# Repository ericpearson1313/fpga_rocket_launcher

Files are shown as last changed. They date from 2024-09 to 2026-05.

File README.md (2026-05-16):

### fpga_rocket_launcher

A long-time hobby of mine is model rocketry where I build and fly models rockets in a club setting.
A launch controller has a push button to electrically launch the models safely from a distance.
The controller feeds current from a battery, through a push button and lead wires to a resistive heater to initiate the launch.
For something so simple it causes consternation when the launch countdown reaches zero, button is pressed, and nothing, due to a fault of the controller!
Years of itteratively building launch controllers has not yet acheived personal perfection in launch controller design, but I'm having fun trying.

This repo contains my design files for a digital, capacitive discharch, launch controller. It was designed as a one-off fully instrumented 
launch controller based on a FPGA which enables built in oscilloscope-like capture and HDMI display. This provides aid in bring-up, observation of algorithm improvements and field analysis during fail-to-launch scenarios to understand how a launch fails (and adjust the design algorithms accordingly, and repeat). 

### Updates / Branches

Well this project has evolved alot. 

The launch controller, fully instrumented, gave me alot of observations of sucessful and failed operations. Burn-through makes this a unique control problem, and when obsereved closely is quite chaotic. Through itterative development and testing I updated the control algorithms and circuits. Alot more testing is needed, but the fpga core 'seems' solid, and my understanding of the initiation process has expanded greatly (and I can see alot more to understand).

Given the core fpga algorithms now for a simple handheld launch controller with rock solid operation.  

Integrating a chip deep within a simple device needs the insight of the development logic (ie hdmi) required tooling(fpgas) to breakout, connect, emulate, monitor, and simulating the system, and test the devices. This required a base architecture and plan to take advantage of the simple interconnect (a dozen I/O signals) available using the algorithm. Since this might be some effort,
planning went into the I/O so that it could address a number of device types in case I wanted to re-use it. The handheld controller was designed and is being trialled.

About this time the TinyTapeout.com course occured. This was an opportunity to move the core logic from Fpga to Asic. The same tooling could be used with an Asic too. 

An ASIC was deveoped integrating the launch control chip core. The system model was used as part of the verification test bench. With some time to spare a BIST (built in self test) was added which contained the system model and runs a 65ms truncated system simulation to self validate the hardware. [3D Chip viewer of the actual chip - way cool!](https://gds-viewer.tinytapeout.com/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)

A quick outline of the different branches that have evolved. The readme docs on the branches are non existant so far.

- main : the fpga launch controller release (V6 = 7298ded) is in regular use.
- lcc_1K : isolated the MVP core and implemented it on a tiny 1k FPGA
- lcc_emu : is the full lauch controller ported to the lcc development board, and then re factoted to use the lcc_1k core and instrument it.
- lcc_mon : is a stand alone monitor that jsut looks at the signals of the LCC. Used to validate correct in system opeation
- lcc_syssim : is a system simulator (in progress) that connects to an LCC to test it.
- lcc_tt : is Tiny Tapeout chip in 130nm on a 0.2 x 0.16 mm die (1x2), it almost fit on a 1x1 tile, but not quite, so utilization is low.
- lccst_tt : is a Tiny Tapeout chip including a full self test (2x2) is 320x200um. The self test logic (a full system simulation) is almost 3x larger than the core, but gives me self test.

The original devlopement doc, where it all started, continues below

# Digital Model Rocket Launch Controller

A FPGA based model rocket digital launch controller.

No embedded CPU, this is Verilog RTL synthesized digital logic.

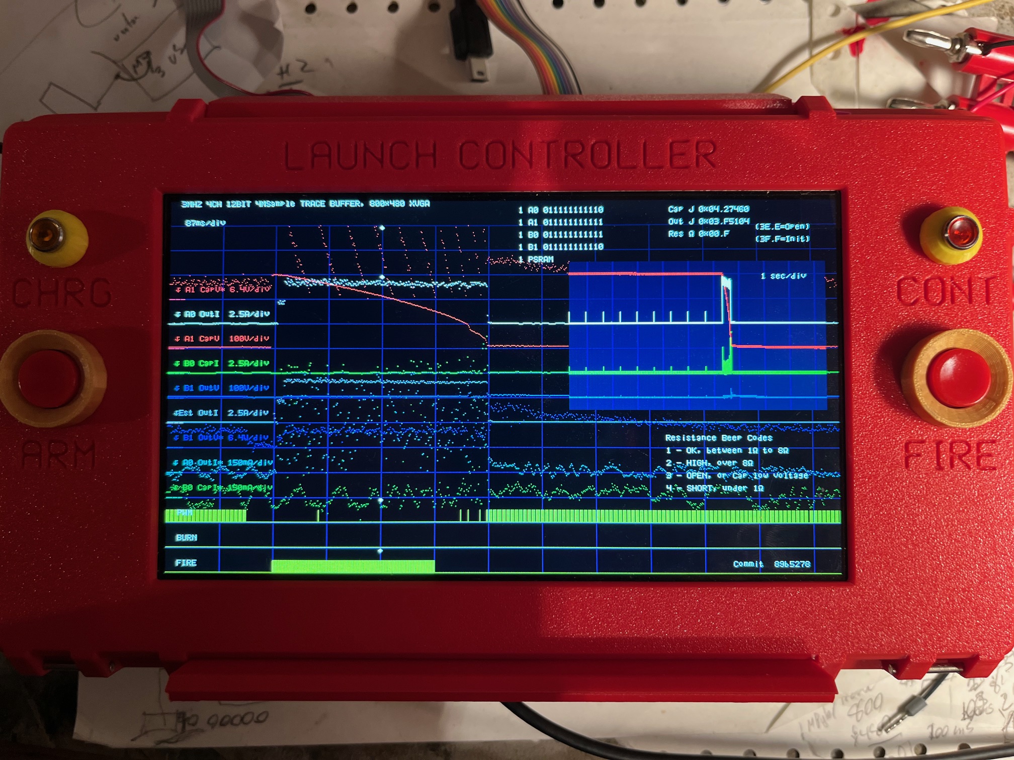
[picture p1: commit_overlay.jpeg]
git commit hash overlay Estes Igniter test


Showing a bench test using an Estes igniter. Observed low resistance (~ 1ohm) and takes 4 Joules at 4 amps for about 300msec.

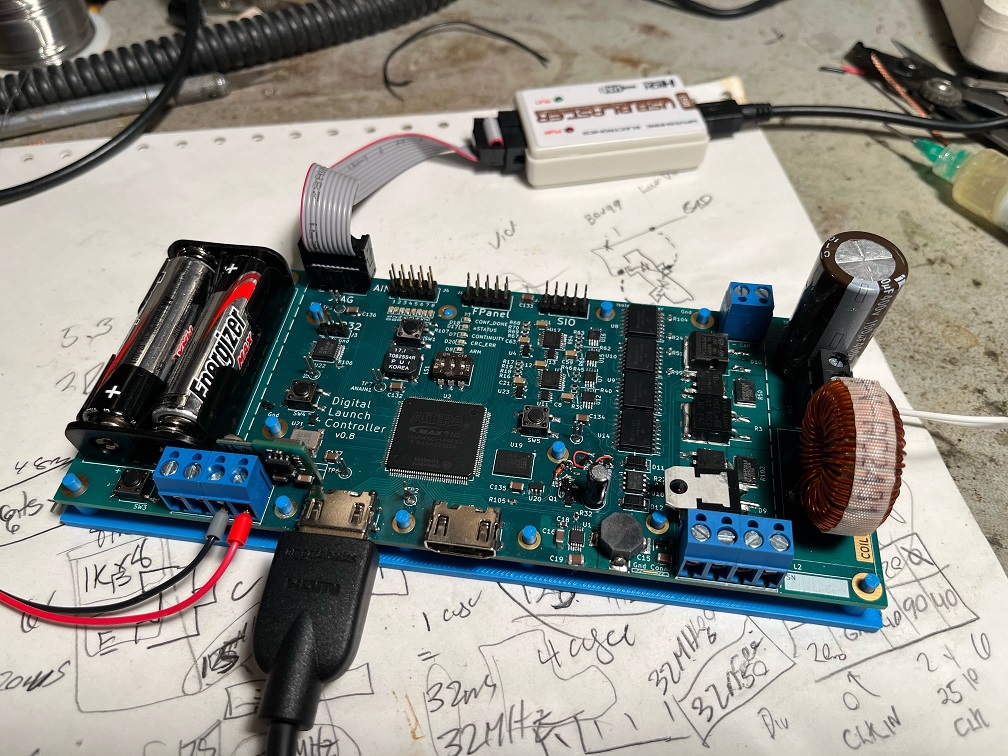
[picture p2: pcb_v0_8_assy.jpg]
Assembled and testing Digital Launch Controller Prototype


[Schematic](fpga_blaster_schem_v0_8.pdf)

### Digital constant current capacitive discharge launch controller.

## Core function

Powered by 4xAA Lithium batteries capable 1A of current. 
When armed, the controller charges a 200uF capactor bank to 320V with a flyback converter giving 10 Joules of stored energy. 
Upon launch, the capacitor is discharged through a 390uH inductor into the igniter.
The discharge is modulated by a FET with a PWM gate drive.
Discharge is digitally current controlled as a buck converter with a setpoint in the range of 2.0 to 6.0 amps.
The set current is maintained over the full capacitor discharge, or until the ignitor burns through and the circuit opens.

The digital control system uses a differential analog front end, used to isolate and instrument the capacitor and output IVs.
12-bit ADCs sample the four signals (cap/out,I/V) which are simultaneously sampled and digitized at 3 Mhz and fed into the digital system.

The PWM signal is generated by a control loop running at 48 Mhz (16x sample rate). 
The control loop models the inductor current based on the PWM signal, ADC capcitor and output voltages (slowly changing), sample rate coil inductance. 
The PWM is turned on when ADC output current falls below a setpoint.
The PWM is turned off when the output current model rises above a setpoint,  
The model used for turn-off to avoid overshoot due to timing accuracy and sample latency.
A stable current pulse is generated limited only by the dropping capacitor voltage with a ripple limited only by the minimum PWM pulse width.

## Extended Functions

Additional uses for FPGA logic and real time ADC data stream can be implemented. These range from simple to Max Headroom.

### Charged LED Hysteresis.

Using the ADC stream include the capacitor voltage, the charge-LED could be operated to reflect the capacitor voltage charge with some hysteresis.
The logic would turn on the charge-LED when the capacitor voltage sample is received and reached 300V, as we want a full charge for launch, 
but would only turn off the charge-LED when the capacitor voltage falls below 50V (<3% energy) as we'ed like to know when it is safe to handle.

```
// Arm is based on vcap with 300v on thresh and 50v off thresh
logic cap_charged;
always @( posedge clk ) begin
	if( reset ) begin
		cap_charged <= 0;
	end else begin
		cap_charged <= ( strobe_d && vcap > (( 300 * 10000 ) / 2005 ) ) ? 1'b1 :
		               ( strobe_d && vcap < (( 50  * 10000 ) / 2005 ) ) ? 1'b0 : cap_charged;
	end
end
```

### Fire Button Debounce and Feedback.

Some dedicated logic to handle the lauch button input is worth while.

To make low cost push button feel nice required: adding debounce logic, and provide audio feedback of its operation. 
To do this debounce counters are used to measure at least 5ms of time before sensing a 'press',
and then generating a fixed 10msec pulse output for logic triggering, and 10msec C5 beep for feedback. 
100ms of release time was required before dectecting another button press. 

Multiple experments and measurements were done to get a basic good enough 'feeling' for this button. The audio feedback worked pleasantly well.

This button also had a long press detect feature to trigger additional functionality. 
If held for 600msec a 2nd signal output would be asserted while held.

### Pulse Energy Accumulation

Ignition energy is a key parameter of igniters. Mensurements
are usefull to check this value.

The instantaneous power (Watts) of the capacitor and outputs can
each be calculated from the ADC samples as E = I * V.

The energy (Joules) over a time period can be accumulated by the sum
of the power measurement.

Using 44 bit sum of product of the unscaled I and V ADC values during ignition period gives allows a 10 Joule range with uJ resolution.
Using the unscaled ADC data elimiates numerical error accumulation. For display the nearest decimal point position was chosen from the 44 bit number
and fixed point hexadecimal coding used for display. 
```
// Acculuate both Cap and Output power products.
always @(posedge clk) begin
	strobe_d <= ad_strobe;
	// P = I * V
   pout[21:0] <= vout[10:0] * iout[10:0];
   pcap[21:0] <= vcap[10:0] * icap[10:0];
	if( strobe_d ) begin
		acc_flag_d <= acc_flag;
		// raw power loaded at flag rise, acculuated during flag, and held afterwards
		eout[43:0] <= ( acc_flag && !acc_flag_d ) ? { 22'b0, pout[21:0] } : ( acc_flag ) ? ({ 22'b0, pout[21:0] } + eout[43:0]) : eout[43:0];
		ecap[43:0] <= ( acc_flag && !acc_flag_d ) ? { 22'b0, pcap[21:0] } : ( acc_flag ) ? ({ 22'b0, pcap[21:0] } + ecap[43:0]) : ecap[43:0];
	end else begin
		acc_flag_d <= acc_flag_d;
		eout[43:0] <= eout[43:0];
		ecap[43:0] <= ecap[43:0];
	end
end
```

Measuring power of both the output and capactor gives insights into the device efficiency and 
some redundancy for measurement validation.

### Continuity Checking

Checking the continuity of an igniter is a resistance measurement to 
check for cases where the circuit is open or shorted.

After the system is armed and waiting for launch, once per second, a 1usec PWM pulse is generated.
Ohms law, R = E / I, is performed on the ADC samples to derive a resistance.

The resistance is averaged and shown to be repeatable over the range 0.4 to 30.0 ohms.

Thresholds are applied to the resistance to decide when the continuity LED is turned on (1.0 to 16 ohms),
and a beep code is generated (A mute dip switch stops the beep codes after the first)

```
1 beep - OK, 1.0 to 8 Ohms
2 beeps - HI, over 8 ohms, but not open
3 beeps - Open circuit,
4 beeps - SHORT circuit maybe, under 1.0 ohms
```
Note: the energy output for this short pulse is accumulated and displayed by the previous function
and usually under 0.25 mJoules which is not enough for ignition.

### HDMI VGA output

Normally on-board LEDs are usefull during development debug to present state to give some insight into
correct operation. Usually there are never enough LEDs as state can get quite involved. 

The next steps usually involve: oscilloscopes, logic analysers, computers and software, however ...

LEDs can be replaced with pixels on an HDMI display. FPGA logic to generate HDMI outputs at XVGA 800x480x60Hz resolution is accomplished
with a 32Mhz pixel clock, and DDR LVDS outputs clocked at 160Mhz giving 320mbit ea for Red, Green and Blue. Digtal counters are used
to generate the video syncronization and maintain the current X and Y locations on the screen.

Connecting an internal signal to a given pixel can be as simple as the logical AND of test signal and desired pixel location, 
with all pels being ORed together to make the video signal
```
assign pel1 = (xcount == 100) & (ycount == 300) & (test_signal1 == 1);
assign pel2 = (xcount == 100) & (ycount == 310) & (test_signal2 == 1);
assign video = pel1 | pel2
```
With some additional logic a font set can be derived giving live text display of binary or hex measurements and dynamic text overlays like:
```
	string_overlay #(.LEN( 9)) _id4 (.clk(hdmi_clk), .reset(reset), .char_x(char_x), .char_y(char_y),
	.ascii_char(ascii_char), .x('h02),.y('h03), .out(id_str[4]), 
	.str(	( zoom == 0 ) ? " 21us/div" :
			( zoom == 1 ) ? " 43us/div" :
			( zoom == 2 ) ? " 85us/div" :
			( zoom == 3 ) ? "170us/div" :
			( zoom == 4 ) ? "340us/div" :
			( zoom == 5 ) ? "680us/div" :
			( zoom == 6 ) ? "1.4ms/div" :
			( zoom == 7 ) ? "2.7ms/div" :
			( zoom == 8 ) ? "5.5ms/div" :
			( zoom == 9 ) ? " 11ms/div" :
			( zoom == 10) ? " 22ms/div" :
			( zoom == 11) ? " 44ms/div" :
			/*zoom == 12)*/ " 87ms/div" ) );
```
Using this method logic was built to allow the display of live values: igniter resistance (ohms), capacitor and output energy (Joules), average ADC binary values, error statuses for ADC channels and PSRAM. Fixed point hex values are used for sake of logic simplicty. Noting that 5 hex digits ~ 1 million is helpful.

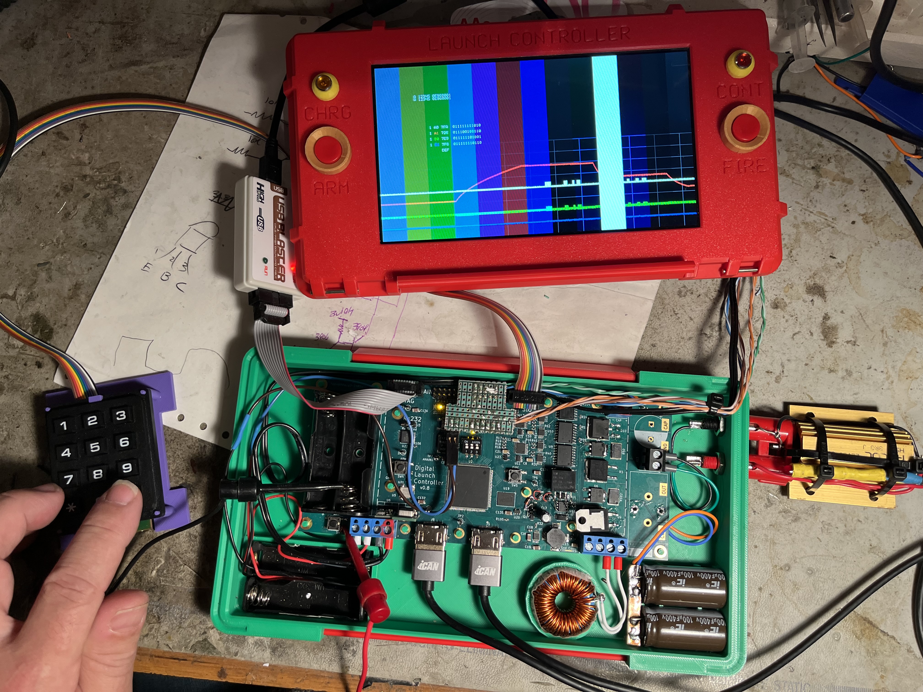
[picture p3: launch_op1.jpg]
Integrated in 3D box with VGA display Integrated with VGA display


### Scrolling Oscilloscope

The 3Mhz ADC samples can have min and max values calculated over longer intervals (1/60s) can be stored
into a 500 sample buffer and plotted and overlayed onto the display giving insight into the coarse
operation of the capacitor charge and discharge without missing a single transient during PWM operation
and allowing sufficient time to visually observer operation. 

This display scrolling is halted 4 seconds after launch to show complete capacitor discharge.

### 32 MBytes Trace Buffer

A PSRAM, or pseudo SRAM, is alow cost ($10), high density (32 Mbytres), high speed (400MBs) sram-like memory, that can connects using only 11 signals. 
It has built in refresh logic, and uses a SPI8 interface for burst access.
A simple controller with an AXI4 interface was developed to configure and 
access the device with 16 byte burst writes, and both 8-byte or 64-byte burst reads.

These PSRAM are only available in ball grid array (BGA) footprints. This was my first home assembled PCB with a BGA. YouTube helped alot for that.

The ADC sampels are stored to a 32 Mbyte circular trace buffer. With 3 Mhz sampling and 64 bits per sample we get 1.3 seconds of storage, which is 
sufficient to capture the full launch operation. 64 bits allows capturing of the 4x 12-bit adc samples, as well as the sampled model (estimated current)
and sampled PWM, and push-button signals as well as an burn-through detect signal.

The buffer is written continuously and only is stopped after launch finished, captureing the full detail from slightly before the launch button is pressed.

### Trace Buffer Display

The 800 samples of data is read from the trace buffer during video blanking and used to plot the sample data multiple scales and colors.
The starting address and stride allows examing the data from very coarse to finest full 3 Mhz detail. 

After launch the fire button is used to step through zoom ranges to see what occured during launch.

### Blipvert

A blipvert is a very brief television advertisement, lasting one second. The term and concept were used in the 1985 film Max Headroom: 20 Minutes into the Future.

HDMI provides a fast and standards compliant way to upload the 32 Mbyte trace buffer to a computer.
The memory is dumped to the RGB video HDMI output, with each visible display line having an memory address
followed by 1 kbyte of data all encoded into the RGB pixels.

This looks like a burst of messy noise, which matched my memory of the blipvert from the film. 

The bipvert is activated by holding down the fire button for at least 1 second and continously dumps the buffer.

Using an HDMI capture card and capturing a second of the video noise gives the entire memory contents,
which can be recovered with a script from the captured video.

#### Blipvert Update #1

The 1st issue is that HDMI capture devices for RGB are costly ($300-$400), but are available
for $20 if a YUV color space is used. That is because the base USB protocol inlcudes support and drivers
for cameras and the cheap HDMI-USB capturee devices only support YUV2 protocol.

So what I planned and did was to switch over to YUV2 during blipvert operation. 
This meant inserting HDMI InfoFrame packets during video blanking, so each viedo frame could be identified
as either RGB24 or YUV2 coded. This swithcing worked.

This raised the 2nd issue was that my awesome and pricy sunlight viewable LCD display only supported the DVI subset of HDMI,
and the presence of InfoFrame packets caused issues. And the HDMI capture device required that the InfoFrames
must always be transmitted (or never transmitted).

The solution was to take advantage of the 2 HDMI ports and simultaneously transmit DVI for the LCD display and HDMI to external devices,
such as the Cheap USB capture device or an LCD display.

### Text Overlay

In addition to the dynamic logic derived text it is useful to have some fixed text overlay.

ROM equivalents for a 5x7 font table and a 16 color text overlay efficiently utilize the FPGA built in SRAMS. 
Unfortuately with this lowest cost (SC) version of the fpga, ROM initialization of the SRAMs is not available,
and the updated device costs 50% more. So logic was added to read the onboard flash and load it into the rom's (SRAMS). 

This text allowed my to display some basic static information without worrying about incremental gate cost if I modified the text.

### Git Commit ID

It is always helpful to be able to trace a running system back to its git commit. 

Some bash and awk scripting was used extract, format, and insert the 7 hex digit git commmit id into the text overlay 
(lower right corner) before the FPGA was compiled. Very handy

## FPGA Selection

The MAX-10 FPGAs from Intel/ALtera were selected as a) free tools were available and b) low cost devices and c) the instant-on (10mSec) boot time.
The 144 pin quad flat pack was chosen as it is hand solderable and probe-able. Devices from 2K to 25K logic cells are avaialable in pin compatible packages.
The free tools support System Verilog design input, and provide support integrating device specific features including differential and DDR IO and PLLs for clock generation. 

The design choice was the Intel Altera 10M04SCE144C8G, breaking down the part number:

```
10M - this family has free software tools.
04 - This was a $20 low cost device, has 4K Logic Elements (LEs) ).
SC - compact(cheap) device, no analog input, limited flash, no rom
E144 - Hand solderable quad flat pack
C - cheap consumer temps only
8G - cheap, slowest speedgrade
```

This 10M04 device also support pin compatibility over a 2 to 25K LE. 

The 10M04 is also a 'limited' device, in that
it is actually an 8K LE device and limited by software to only allow 4K usage. This allow the vendors to sell
their "Floor sweepings", and provides 1/2 cost devices to us. The neat part is that 100% utilization of the 4K LEs is 
then possible as which LEs are used remains flexible, and the interconnect is sized for higher densities, so it can
be fully packed to 99% utilization.

## Free Development Tools 

FPGA Dev Tools : Intel Altera Quartus Prime Lite v23.1

Schematic/PCB  : KiCad 7.0

## Capacitor discharge Pros and Cons

After this experience is a good time to reflect on the trade offs in
capactor discharge launch controllers vs a standard launch controller based with push button.

```
Pros:
+ Current Pulse delivers same power with any cabling
+ safety, can be part of an intrisically safe system
+ Resistance Measurement with 0.1 ohm precision
+ Energy Measurement with 1 uJ precision 
+ Repeatability with constant current with minimal ripple
+ Failure Analysys Data
+ Portable, with small battery
+ Battery Life is extended 
+ Reliability, Feedback gives confidence  

Cons:
- Button - it still needs a push button, and can be replaced by a push button.
- Expensive
- Estes - does not work well with estes igniters
- Complex system
- High Voltage and Arcing
- Majority of limited capacitor energy can be dissipated in launch leads and connections.
```

### A ForgeFPGA-1K implementation

Update: A ForgeFPGA implementation. 

I came across ForgeFPGAs which are 3x3mmm low power low cost ($0.50) FPGA chips containing a respectable 1120 logic cells. 
The 24 pins package had the IO needed and the logic cells seemed appropriate for a the launch controllers core functions.
The free tools for synthesis and place-route worked with my verilog code with minor tweaking.
With functional simplification (eg: no hdmi video, no dividers) the tools fit the core launch controller logic gates into 
the ForgeFPGA-1K and generated power and timing reports. 
I then verified the forgefpga verilog by embedding it into my altera max10 fpga launch controller allowing me to view the instrumented interface 
 between the co-synthesized core ForgeFPGA and the real hardware (very nice!).
I plan to use this launch control fpga for an minimalist handheld digital launch controller PCB. It would have connectors for mounting the ForgeFPGA Eval board for development, and would otherwise re-use the ADC and power circuitry interface as needed from the previous controller.

With the size of the FPGA now reduced to basically nothing, a compact size could be looked at. I stopped and considered the shapes limited by the large components: 4xAA, 2x Caps, 1x Coil, and along with output jacks. 3D printing each allowed some ergonomic testing and locating the 2 pairs of buttons and Leds.
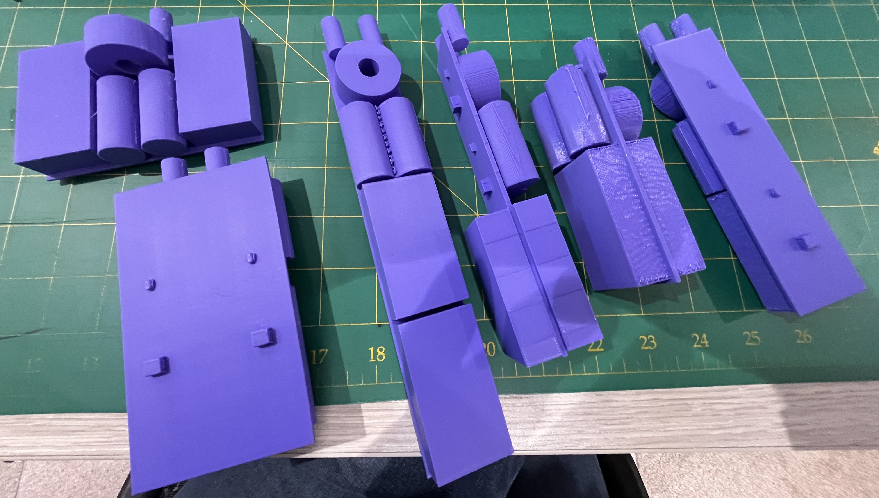
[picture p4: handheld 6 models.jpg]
handheld model trials trial configurations


A starting layout of the PCB using the landscape packing was chosen from among the models.
The landscape form factor nicely extends to put a connector for the ForgeFPGA evaluation board to be plugged into. That part of the PCB is intended to be cut away (but could be integrated into a taller handheld unit). Mouting land for a spare FPGA is nice. The isolation of high voltage areas is considered from the beginning.  The isolation barrier and components crossing it are clear and visible.
The layout packed the high power connections to the top center of the PCB.

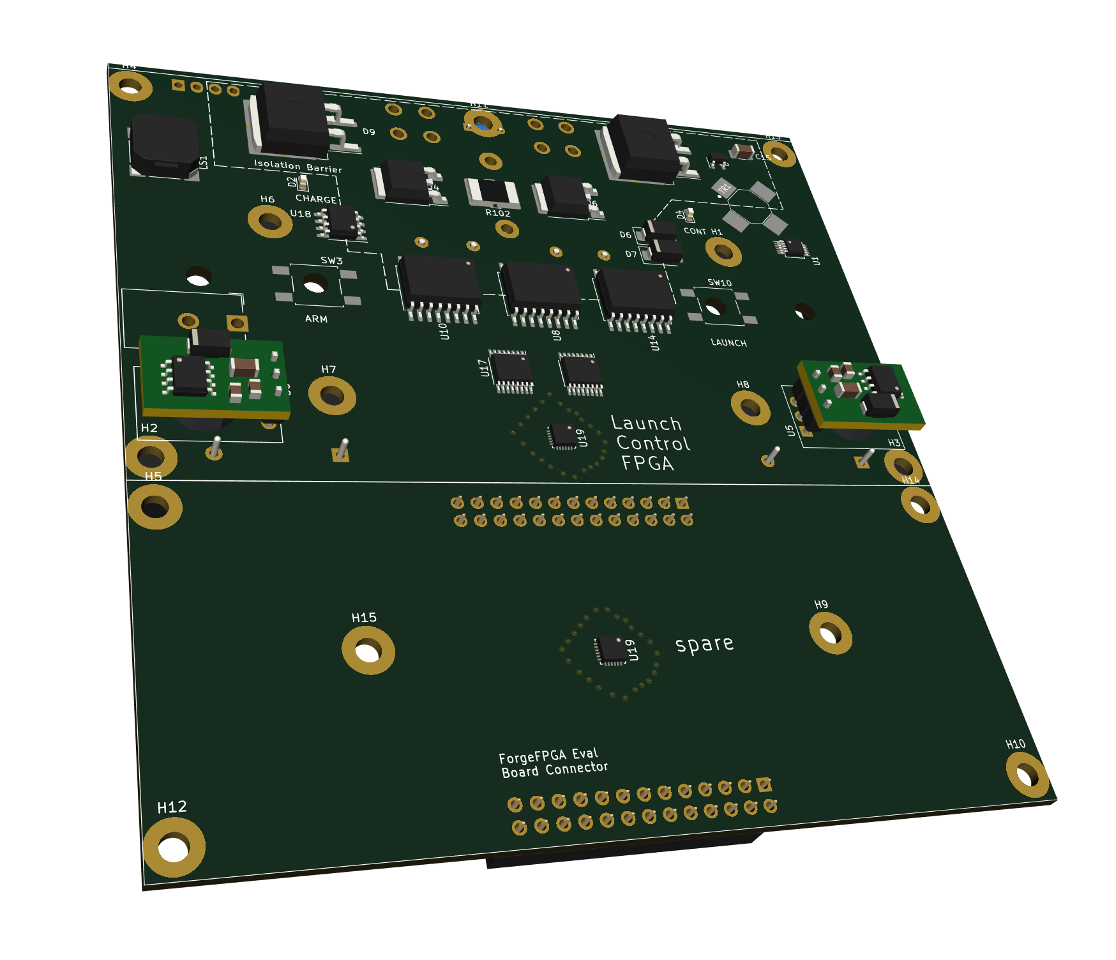
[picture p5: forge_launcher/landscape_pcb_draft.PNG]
landscape PCB starting point Initial PCB layout


Prior to fully detailing the PCB outline and button/led positions and clearnaces are needed.
I wanted to integrate the leds and buttons into the enclosure. Light pipes for the leds, and frogs
for the buttons. (frog aka pushbutton-with-integrated-spring-for-tactile-switch).
A basic 3d printed model of the enclosure was printed to see how it feels and test the frogs.
I definitely want it thinner and rounded/bevelled. The influence of this model will be far reaching in
the final design. 

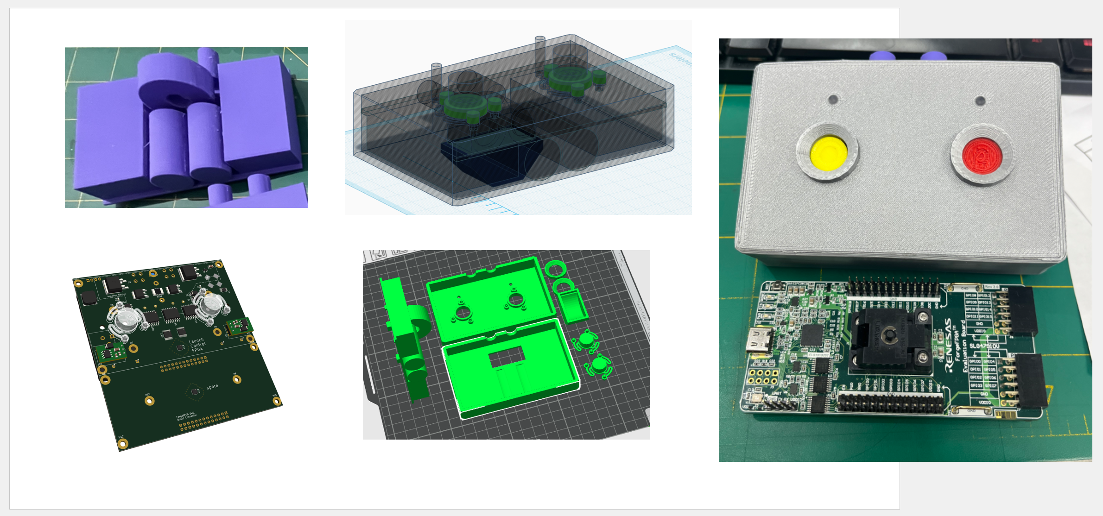
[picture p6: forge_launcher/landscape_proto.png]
landscape prototype Handheld Prototype


Next steps for the minimalist fpga launch controller will be parts ordering, pcb tapeout, and initial 3d enclosure and development stands ...

Its a good point to pause and consider things. So I'm going to loop back and re-examine everything before committing to the next design...

# A Chip ...

lccst_chip Tiny Tapeout of Lauch control chip - 130nm 3x2 tile

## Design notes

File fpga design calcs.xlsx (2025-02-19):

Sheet: Sheet1
Current | Amps | 30 |  |  |  | 48 | mhz vin
 |  |  |  |  |  | 24 | M div
 |  |  |  |  |  | 1152 | mhz vco
Driving | Ohms | Power | Ratio |  | co | 6 | 192 | ext differtial clock
Fet | 0.145 | 130.5 | 5.2 |  | c1 | 24 | 48 | main clock |  |  |  | 60
Sense | 0.05 | 45 | 1.8 |  | c2 | 6 | 192 | 4x for SPI clock |  |  |  | 525
Coil | 0.072 | 64.8 | 2.6 |  | c3 | 45 | 25.6 | VGA video clock |  |  |  | 800
Cable | 0.5 | 450 | 18.1 |  | c4 | 9 | 128 | 5x VGA clock |  |  |  | 25200000
Igniter | 2 | 1800 | 72.3
Coasting
Coil | 0.072 | 64.8 | 2.8 |  |  |  |  |  |  |  |  | 480
Cable | 0.5 | 450 | 19.2 |  |  |  |  |  | 60 |  |  | 256
Igniter | 2 | 1800 | 76.6 |  |  |  |  |  | 106.6666667 |  |  | 224 | 11100000
Diode(v) | 1.15 | 34.5 | 1.5 |  |  |  |  |  |  |  |  | 7
 |  |  |  |  |  |  |  |  |  |  | Energy
 |  |  |  |  |  |  |  |  |  | 0 | 3.260162602e-08
 |  |  |  |  |  |  |  |  |  | 40 | 35845.86689
 |  |  | 800 | 840
 |  |  | 480 | 660
 |  |  | 60 | 60
 |  |  | 23.04 | 33.264
 |  |  |  | 166.32 |  |  |  |  | 19.05
 |  |  |  |  |  |  |  |  |  | 15 | 10682.90081 | nJ
 |  |  |  |  |  |  |  |  |  | 16 | 21365.80163
 |  |  |  |  |  |  |  |  |  | 17 | 42731.60325
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

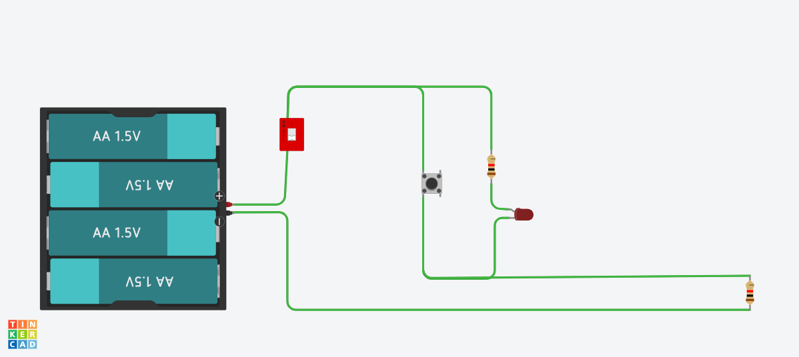
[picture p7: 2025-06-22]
estes_schematic.png

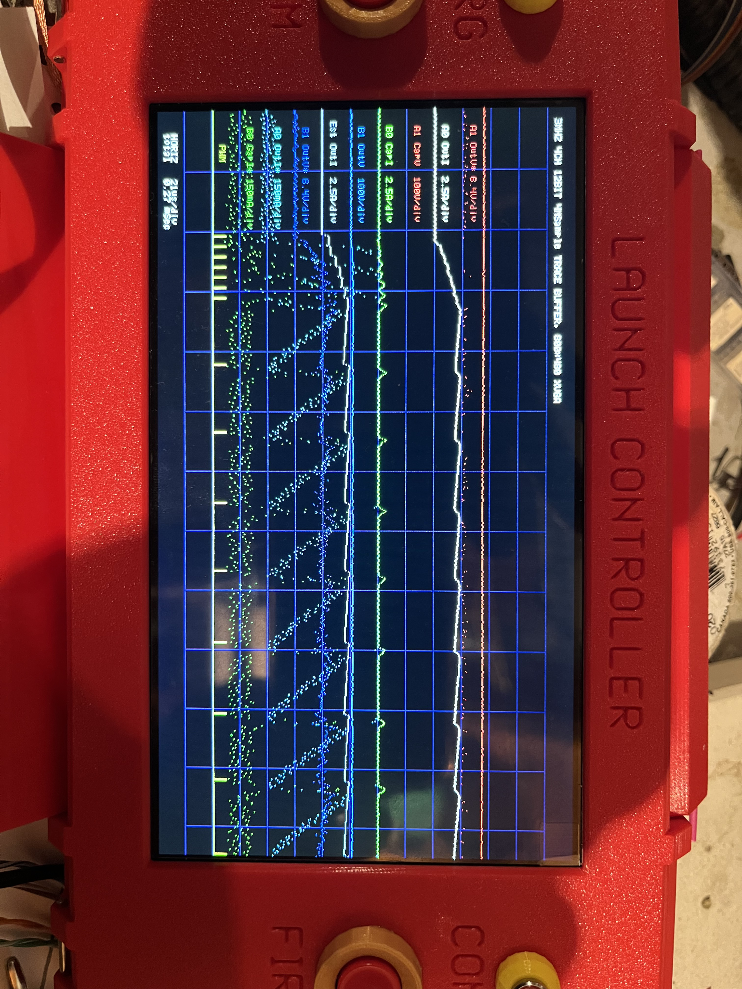
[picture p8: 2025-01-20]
pulse30.jpg

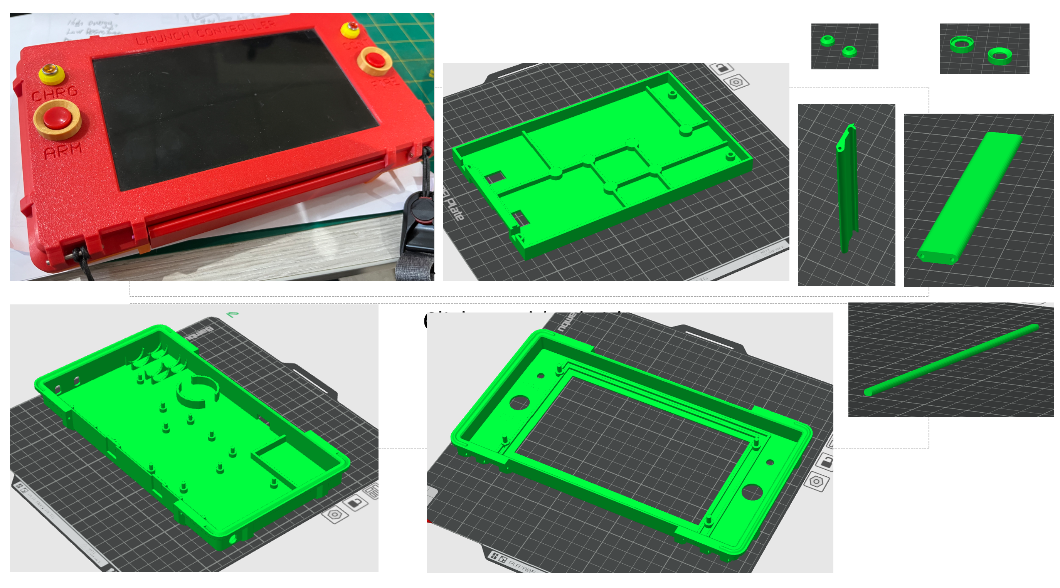
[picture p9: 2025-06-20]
vga_enclosure.png

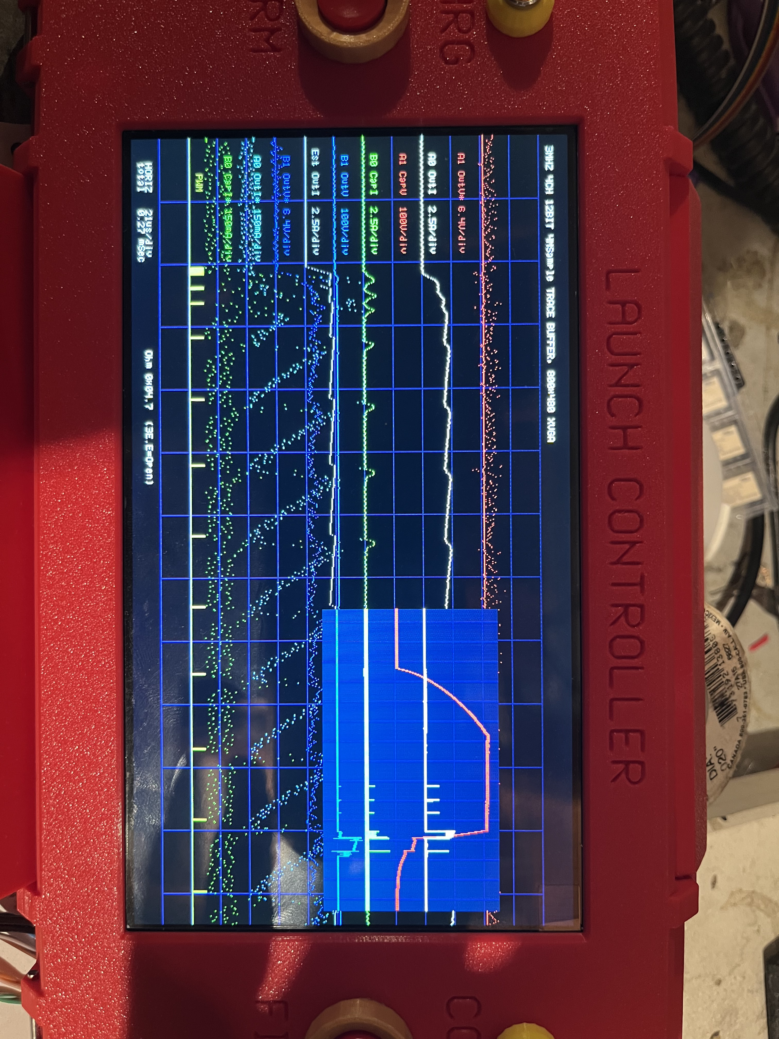
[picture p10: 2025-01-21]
copper_head_trace.jpeg

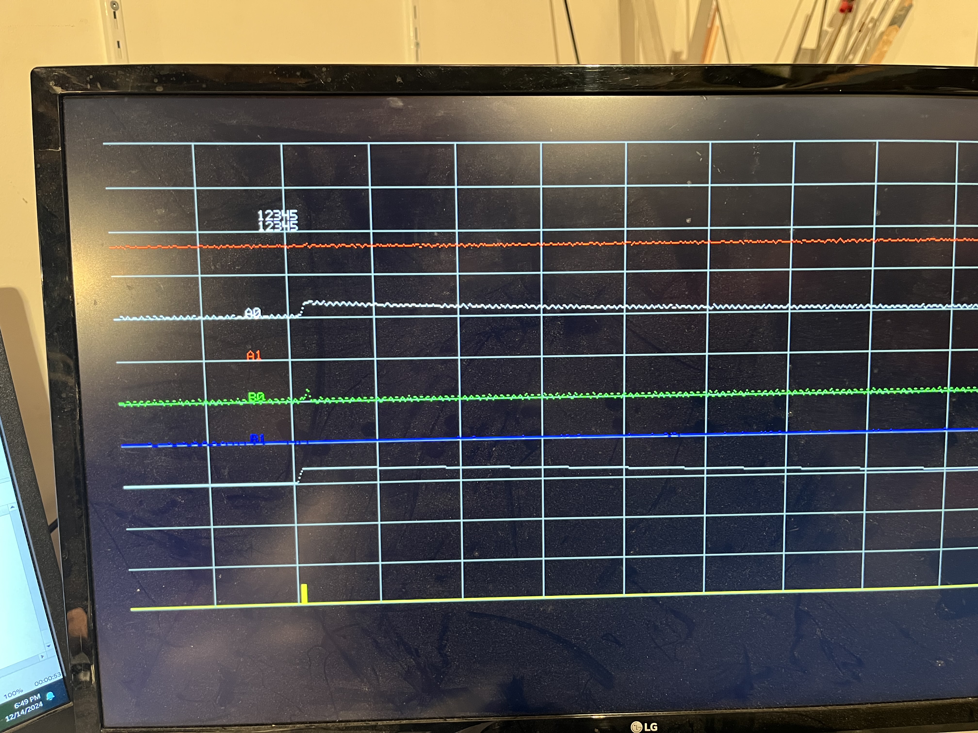
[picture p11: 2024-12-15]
launch_op2.jpg

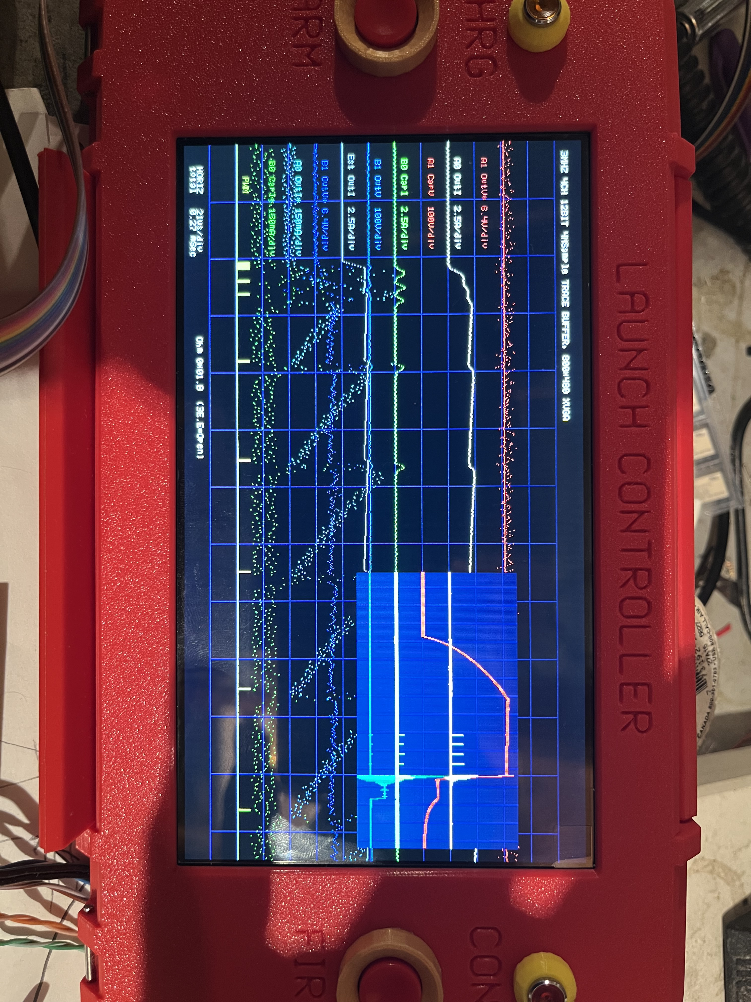
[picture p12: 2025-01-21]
ematch_trace.jpeg

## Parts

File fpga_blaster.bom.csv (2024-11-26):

Qty | Reference(s) | Value | DPN
1 | BT1 | ~ | 36-2462-ND
25 | C1, C3, C5, C7, C10, C11, C18, C20, C26, C30, C34, C45, C50, C51, C66, C70, C75, C87, C88, C89, C90, C91, C128, C129, C130 | 1u | 399-C0603C105K3RAC7867CT-ND
21 | C2, C23, C28, C31, C37, C38, C39, C40, C41, C47, C48, C52, C54, C55, C56, C57, C71, C74, C77, C78, C80 | 0.001u | 399-C0603C102K3RAC7867CT-ND
8 | C4, C6, C27, C33, C36, C44, C65, C72 | 0.01u | 399-C0603C103K3RAC7867CT-ND
6 | C8, C12, C21, C59, C61, C63 | 10u | 399-C1206C106K4PAC7800CT-ND
66 | C9, C13, C14, C22, C24, C25, C29, C32, C35, C42, C43, C46, C49, C53, C58, C60, C62, C64, C68, C69, C73, C76, C79, C81, C82, C83, C84, C85, C86, C92, C93, C94, C95, C96, C97, C98, C99, C100, C101, C102, C103, C104, C105, C106, C107, C108, C109, C110, C111, C112, C113, C114, C115, C116, C117, C118, C119, C120, C121, C122, C123, C124, C125, C126, C127, C131 | 0.1u | 399-C0603C104K3RAC7867CT-ND
1 | C15 | 0.022u 630v | 399-13296-1-ND
8 | C16, C19, C132, C133, C134, C135, C136, C137 | 4.7u | 399-C1206C475K5PAC7800CT-ND
1 | C17 | 100u 20v | 1572-1659-ND
1 | C67 | 100u 400V | 1572-1041-ND
13 | D1, D2, D4, D6, D13, D14, D15, D16, D7, D8, D17, D18, D20 | Yel | 754-2039-1-ND
2 | D3, D19 | BAV99 | 1655-BAV99CT-ND
1 | D5 | MMBD3004SE | GSD2004S-E3-08CT-ND
2 | D9, D10 | ‎STPSC10065G2 | 497-STPSC10065G2-TRCT-ND
2 | D11, D12 | ES1J | 1655-ES1JCT-ND
11 | FB1, FB2, FB3, FB4, FB5, FB6, FB7, FB8, FB9, FB10, FB11 | Ferrite | 490-5254-1-ND
4 | J1, J2, J4, J6 | Conn_02x05_Odd_Even | 732-2672-ND
1 | J3 | Conn_01x03 | 732-5316-ND
2 | J5, J8 | HDMI_D_1.4 | 609-4614-1-ND
6 | J7, J9, J10, J11, J12, J13 | Screw_Terminal_01x02 | 281-2888-ND
1 | L2 | 390uH 5A | M8893-ND
1 | LS1 | Speaker | 668-1068-1-ND
1 | Q1 | STR2P3LLH6(Pfet) | 497-15520-1-ND
4 | Q2, Q5, Q7, Q8 | 2N3904 | 4530-MMBT3904CT-ND
1 | Q3 | 2N3906 | 4878-MMBT3906CT-ND
2 | Q4, Q6 | IPD60R145 | 448-IPD60R145CFD7ATMA1CT-ND
12 | R1, R6, R7, R10, R11, R71, R72, R75, R76, R77, R95, R98 | 10K | P10.0KHCT-ND
3 | R2, R23, R32 | 100K | P100KHCT-ND
1 | R3 | 3K3 25W | 118-PWR263S-20-3301F-ND
14 | R4, R13, R14, R15, R24, R31, R49, R51, R99, R100, R101, R103, R104, R110 | 0R | P0.0GCT-ND
17 | R5, R9, R73, R78, R83, R84, R85, R86, R87, R88, R89, R90, R91, R92, R108, R109, R111 | 1K | P1.00KHCT-ND
1 | R8 | 2K | P2.00KHCT-ND
21 | R12, R16, R17, R18, R19, R39, R40, R45, R46, R61, R62, R63, R64, R67, R68, R69, R70, R74, R105, R106, R107 | 22R | P22.0HCT-ND
4 | R20, R21, R80, R81 | 1.99M | 541-MCT0603MD2004BP500CT-ND
5 | R22, R25, R26, R33, R34 | 10R | P10.0HCT-ND
4 | R27, R30, R52, R79 | 47K | P47KGCT-ND
6 | R28, R47, R48, R65, R66, R82 | 10.01K | 10-ERA-3VRW1002VCT-ND
1 | R29 | 51.1K | P51.1KDBCT-ND
8 | R35, R36, R41, R42, R53, R54, R55, R56 | 1.50K | P1.5KDBCT-ND
8 | R37, R38, R43, R44, R57, R58, R59, R60 | 3.01K | P3.01KDBCT-ND
2 | R50, R102 | 0.005R 1W | 541-3275-1-ND
4 | SW1, SW3, SW4, SW5 | FIRE | 360-2595-1-ND
1 | SW2 | SW_DIP_x03 | CT2193LPST-ND
7 | TP1, TP2, TP3, TP4, TP5, TP6, TP7 | ~ | 36-1037-ND
1 | TR1 | PA0367A | 553-1978-1-ND
1 | U1 | LT3420 | LT3420EMS#PBF-ND
1 | U2 | MAX10M04 | 544-3054-ND
2 | U3, U17 | AD7352 | 505-AD7352BRUZ-ND
2 | U4, U23 | TLV74325 | 296-48989-1-ND
1 | U5 | LMO78_03 | 3182-LMO78_03-1.0-ND
1 | U6 | 4945 | 2183-4945-ND
4 | U7, U12, U15, U16 | LTC6362 | 505-LTC6362CMS8#PBF-ND
2 | U8, U10 | AMC3330 | 296-AMC3330QDWERQ1CT-ND
2 | U9, U14 | AMC3302 | 296-AMC3302DWERCT-ND
2 | U11, U13 | TLV9062xD | 296-TLV9062IDDFRCT-ND
1 | U18 | IR2127 | IR2127SPBFCT-ND
1 | U19 | S80KS2563GABHV020 | 448-S80KS2563GABHV020-ND
1 | U20 | TLV74318 | 296-48712-1-ND
1 | U21 | LM809 | LM809M3-2.63/NOPBCT-ND
1 | U22 | MAX3227 | 296-19849-1-ND
1 | X1 | ASE-48MHz | 535-9328-1-ND

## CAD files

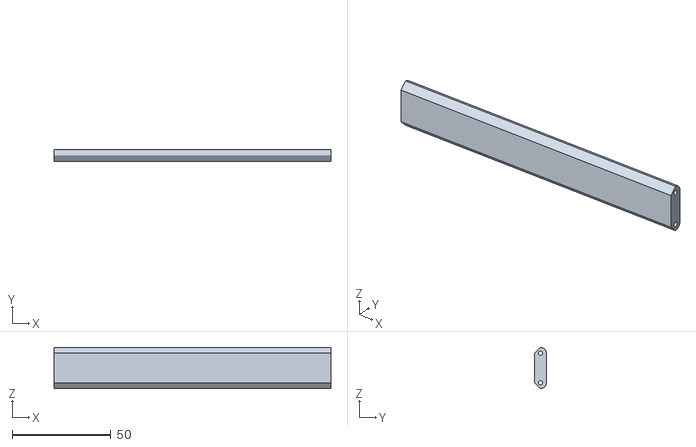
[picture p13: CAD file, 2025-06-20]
vga box hinge v1.stl
140.5 x 6.00 x 21.0

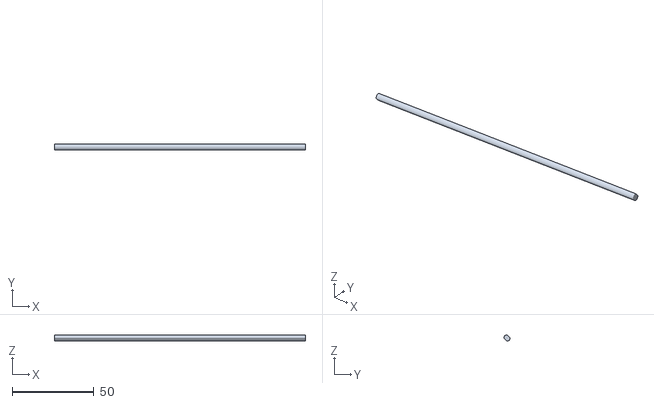
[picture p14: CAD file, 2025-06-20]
vga box pin v1.stl
153.3 x 3.90 x 3.90

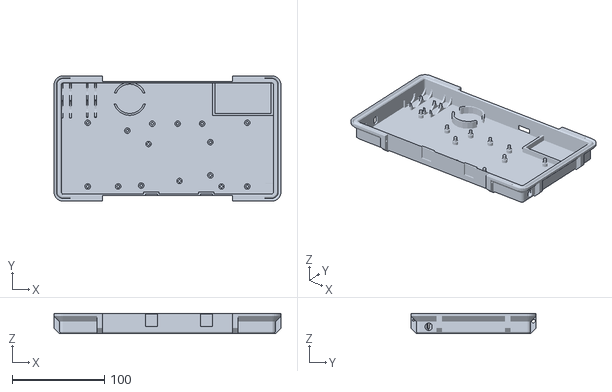
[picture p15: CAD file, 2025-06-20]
vga box bot v4.stl
246.0 x 136.0 x 22.0

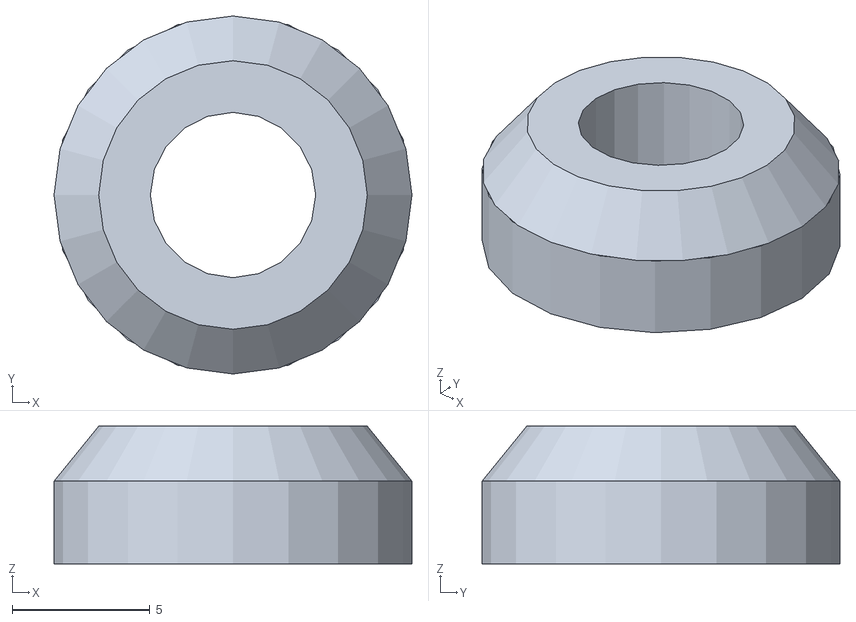
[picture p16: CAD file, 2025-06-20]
led standoff 5mm.stl
13.0 x 13.0 x 5.00

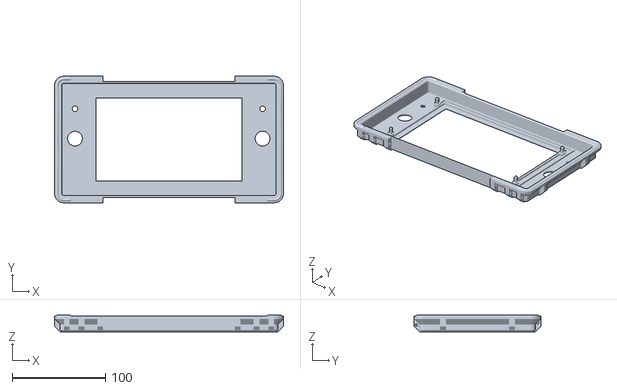
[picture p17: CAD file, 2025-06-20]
vga box top v2.stl
246.0 x 136.1 x 18.1

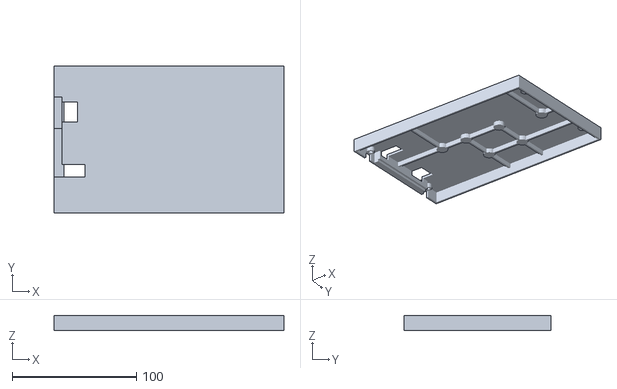
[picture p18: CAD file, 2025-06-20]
lcd 7in rear cover v2.stl
185.0 x 118.0 x 12.0

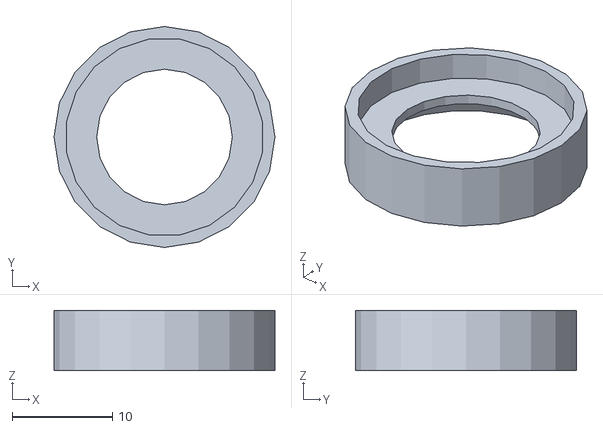
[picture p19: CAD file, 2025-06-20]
button ring v4.stl
22.0 x 22.0 x 6.00

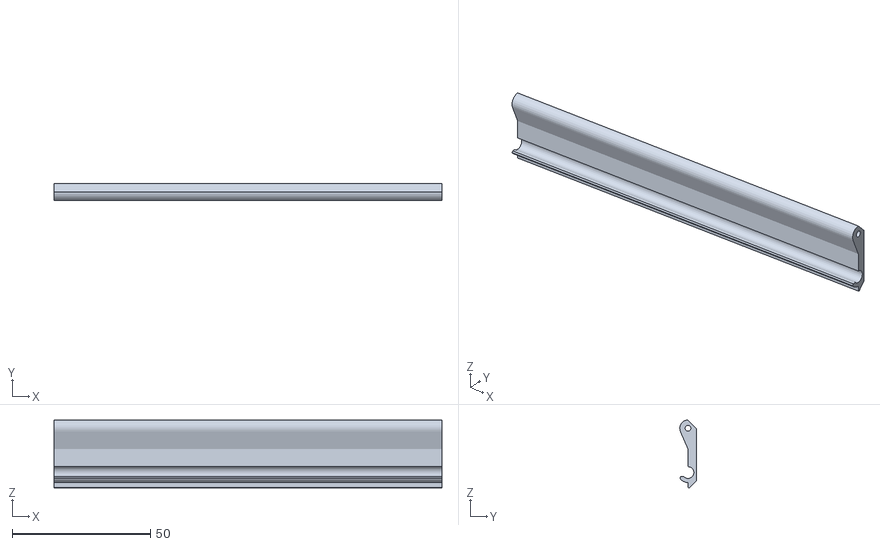
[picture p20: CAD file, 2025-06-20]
vga box clasp v1.stl
140.5 x 6.00 x 24.6

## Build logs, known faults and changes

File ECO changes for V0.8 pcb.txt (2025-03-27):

ECOs for v0.8 PCB

Dec 28, 2024

R23 remove , disconnect continuity circuit.
Q2, Q5, Q7, Q8, footprint fix sot-23 3904 
Q3, footprint fix sot-23 3906
D3, D19, footprint fix sot-23 bav99
D9, D10, Footprint fix
D10 remove 
GDT Add, across coil
R1 replace with 100K
Add 10K R1 to 12V
J6-4 isolate and connect to 12V
Add 3904, 10K for arm LEd
Add 3904, 10K for cont LEd
R43,44,38,37,57,58,59,60 repalce with 1.50K
Add .0022u across differential filters x4
C40,41,38,39,54,56,55,57 replace with 2.2nf
u9.14,10,8 wire pin 15 to gnd
c36,72 remove cap
Add ISO 12v/12v DCDC converter to add power to top gate drive.

Jan 20, 2025

R25,26,33,34 replace 10 ohm with 56 ohm to increase current filtering. 
 observed: had no effect on HAF noise, and current signal too smooth now. (maybe reverse)

Feb, 2025

Added 6K pulldown on pwm signal either end of R105.

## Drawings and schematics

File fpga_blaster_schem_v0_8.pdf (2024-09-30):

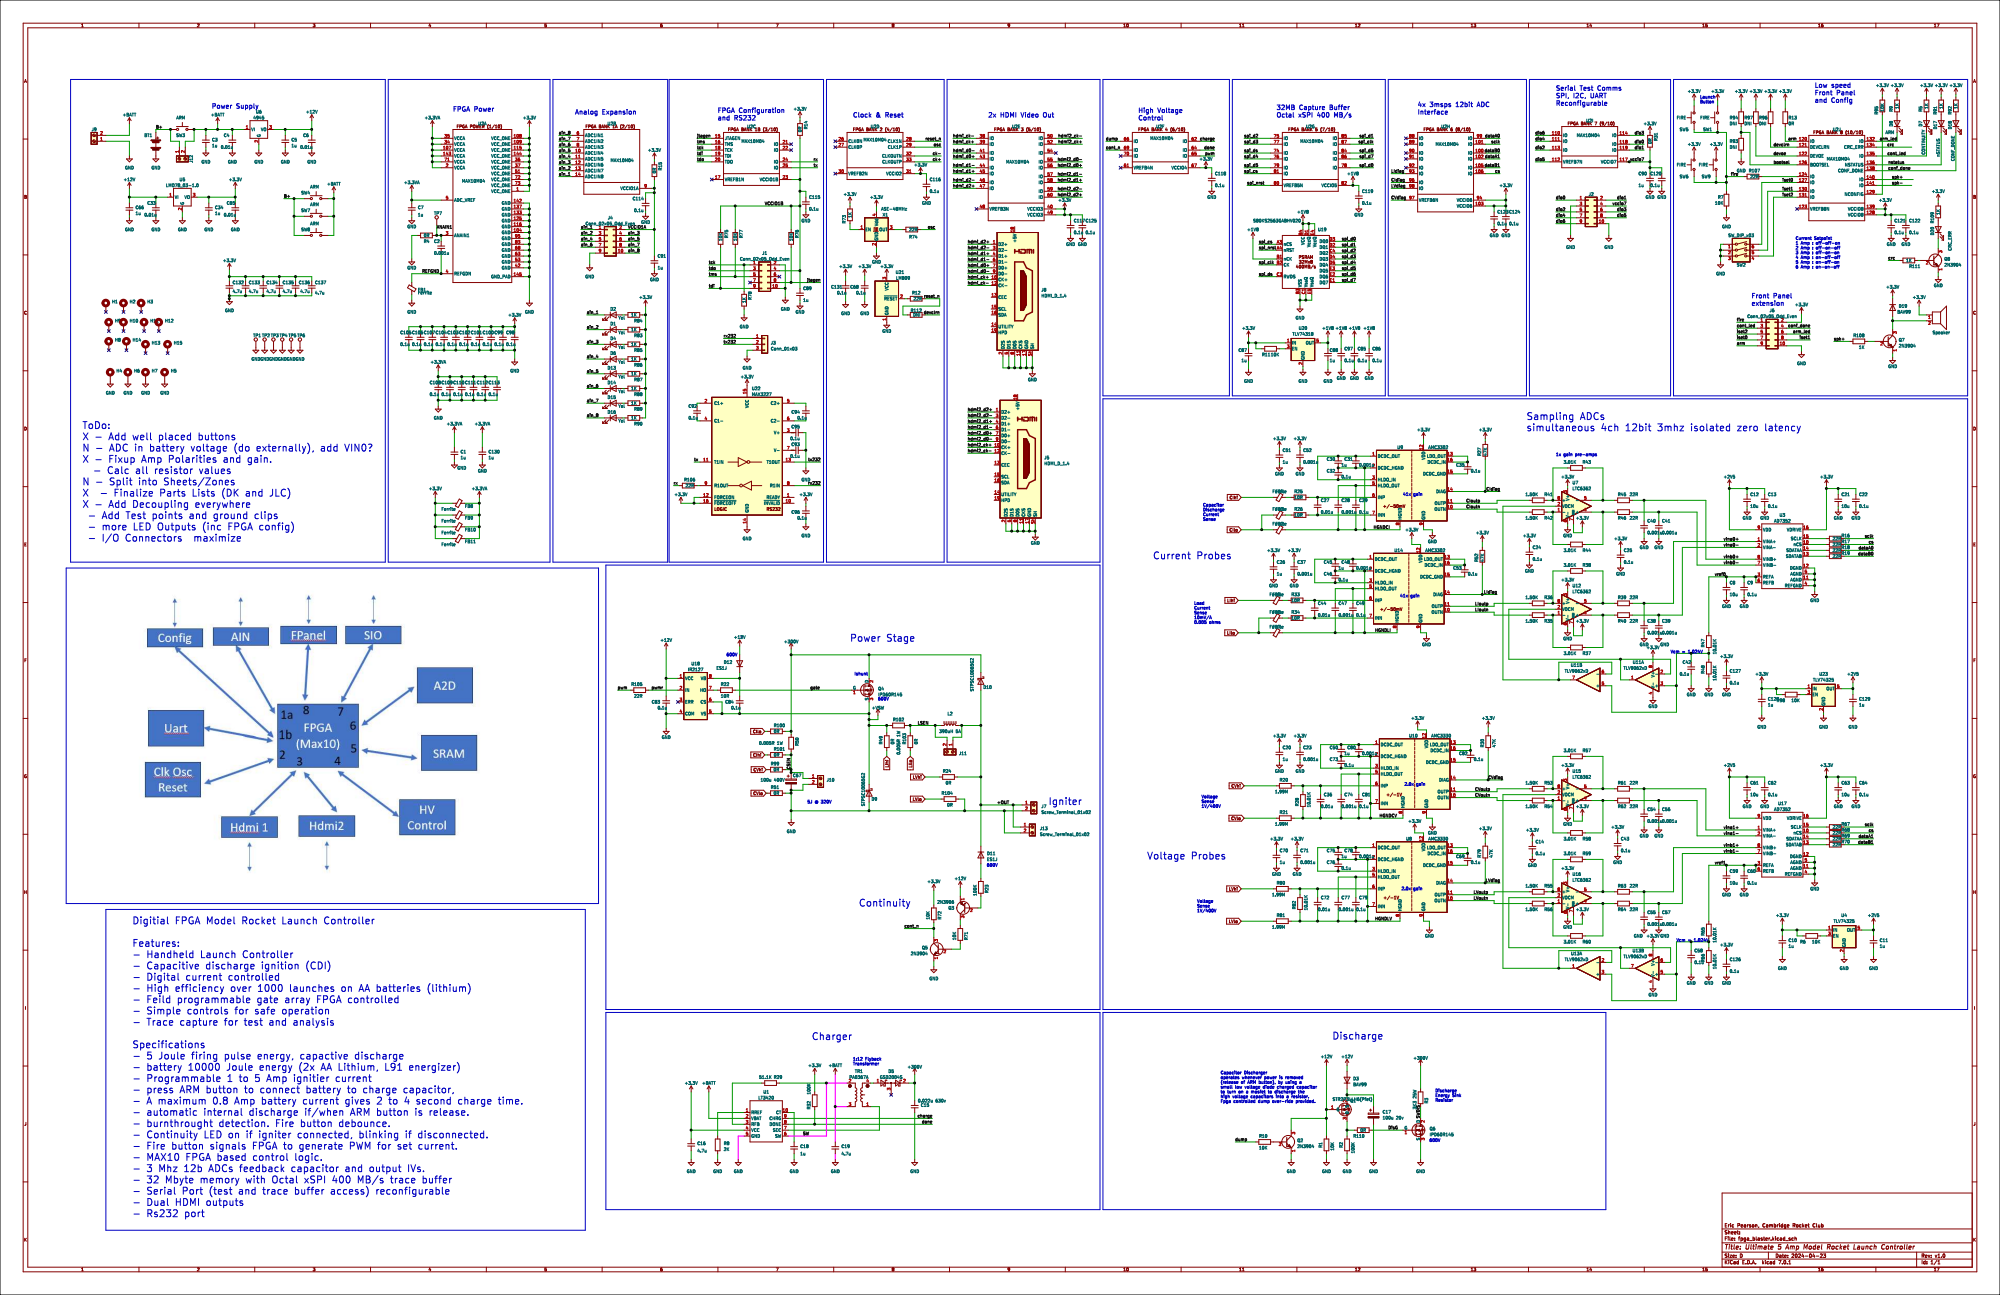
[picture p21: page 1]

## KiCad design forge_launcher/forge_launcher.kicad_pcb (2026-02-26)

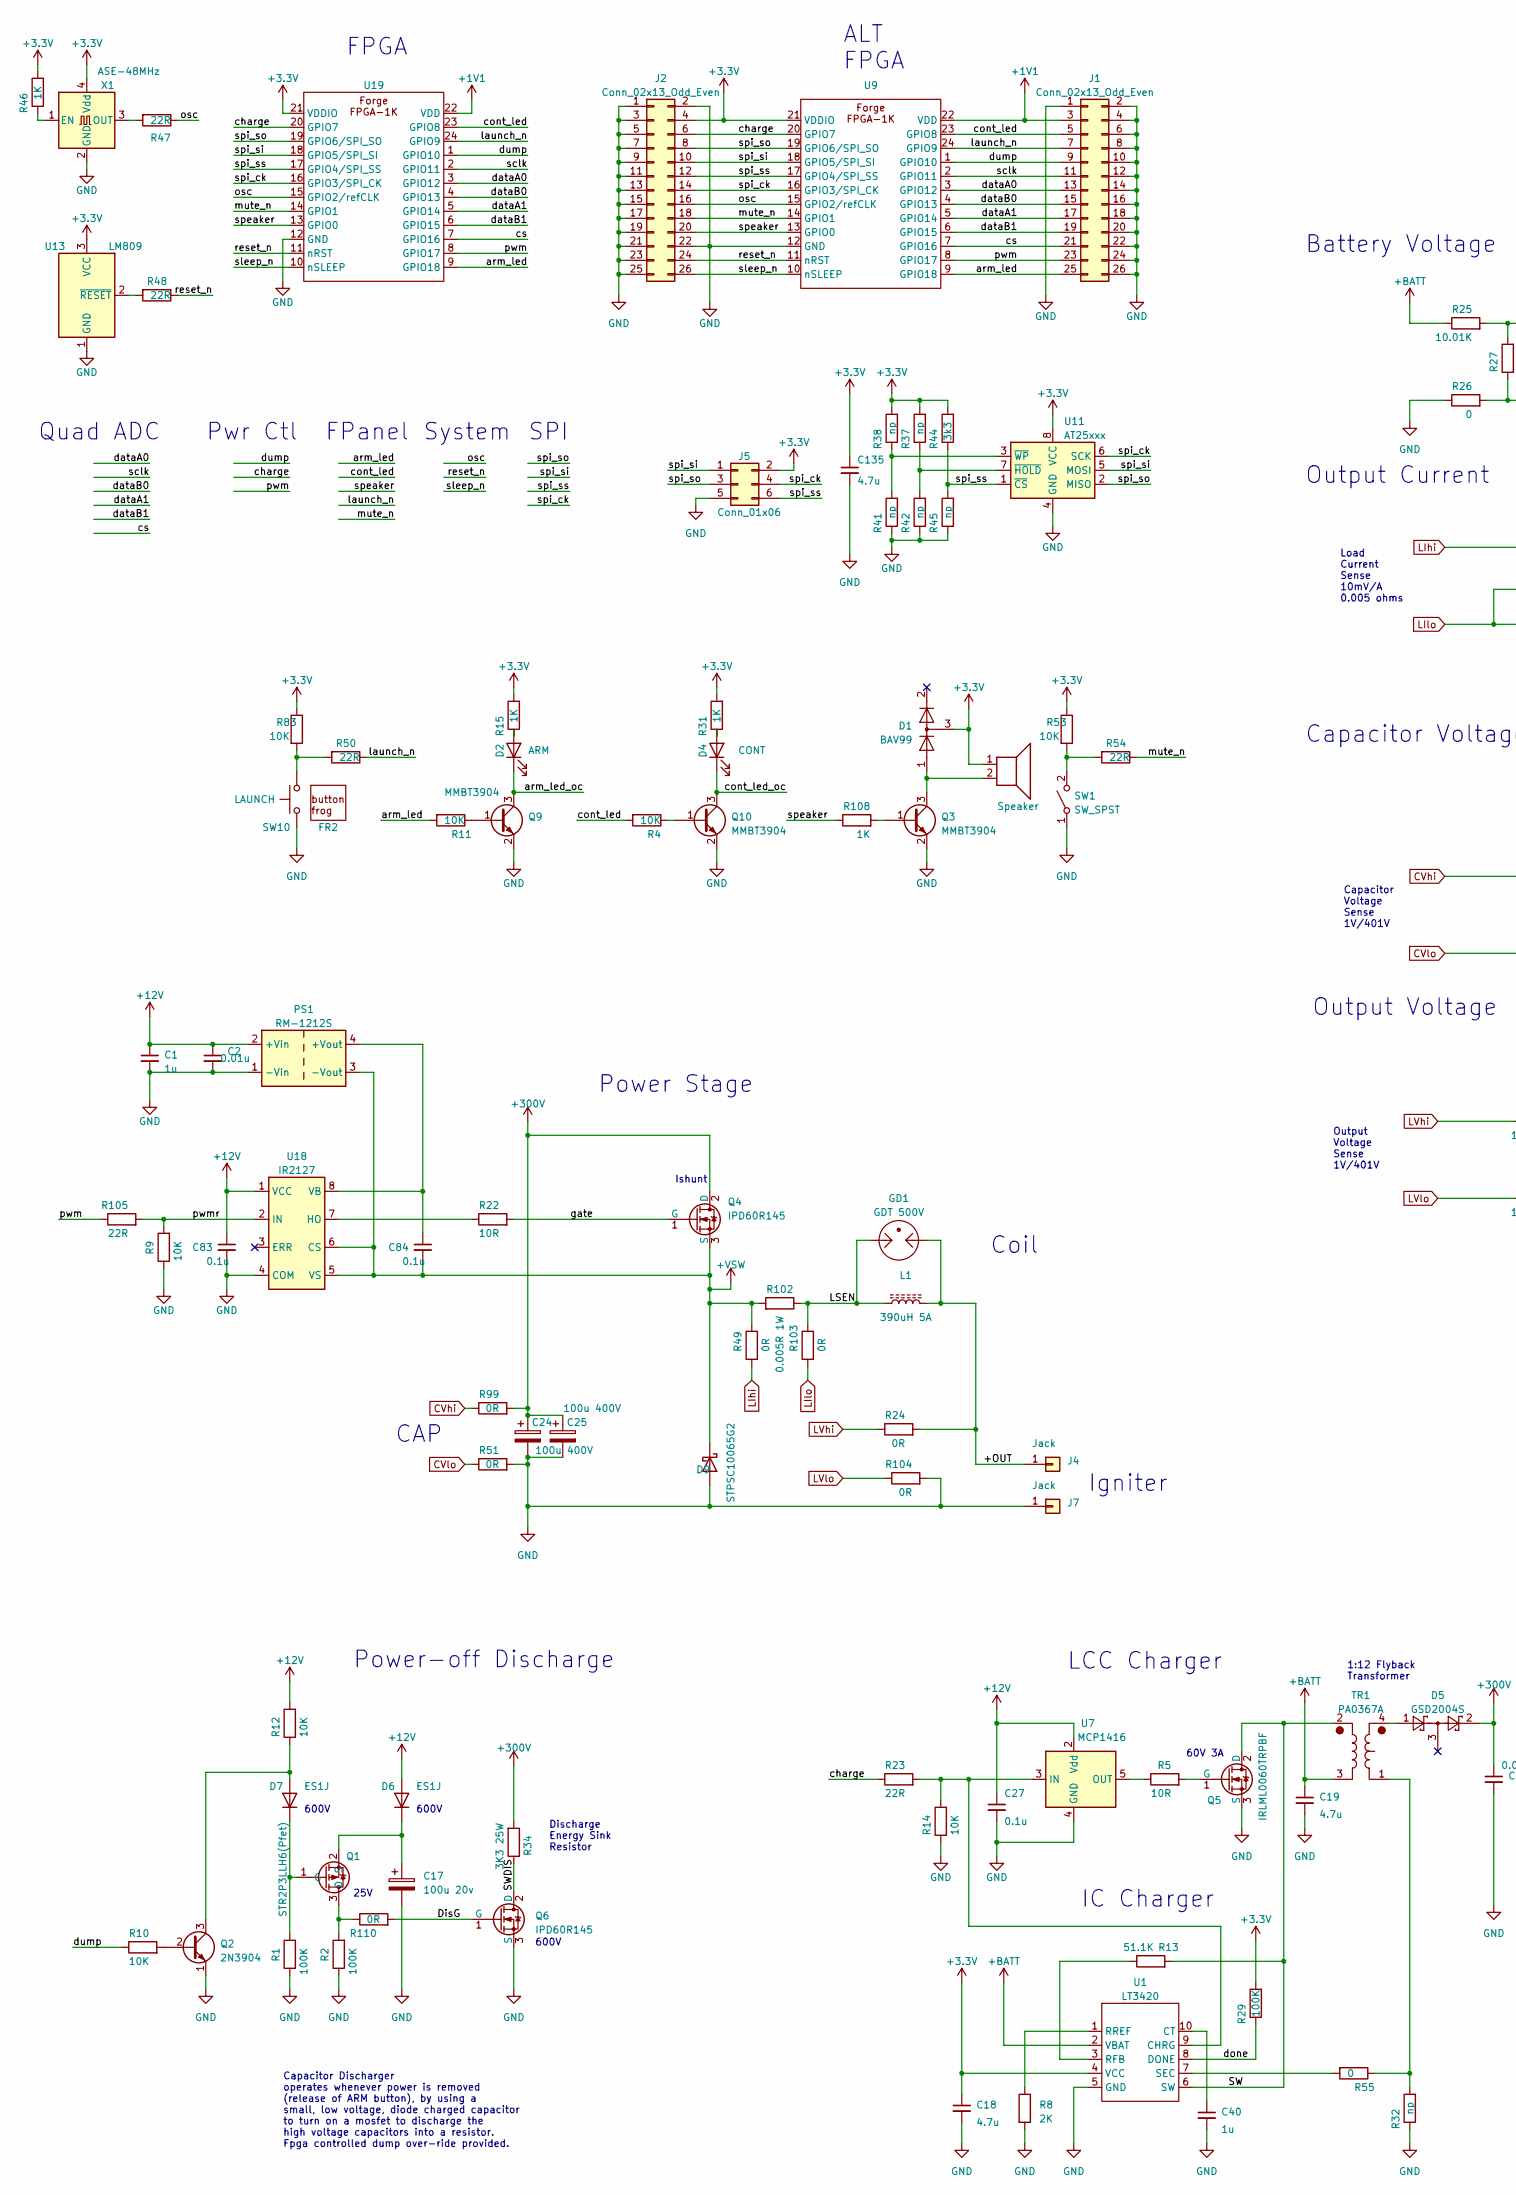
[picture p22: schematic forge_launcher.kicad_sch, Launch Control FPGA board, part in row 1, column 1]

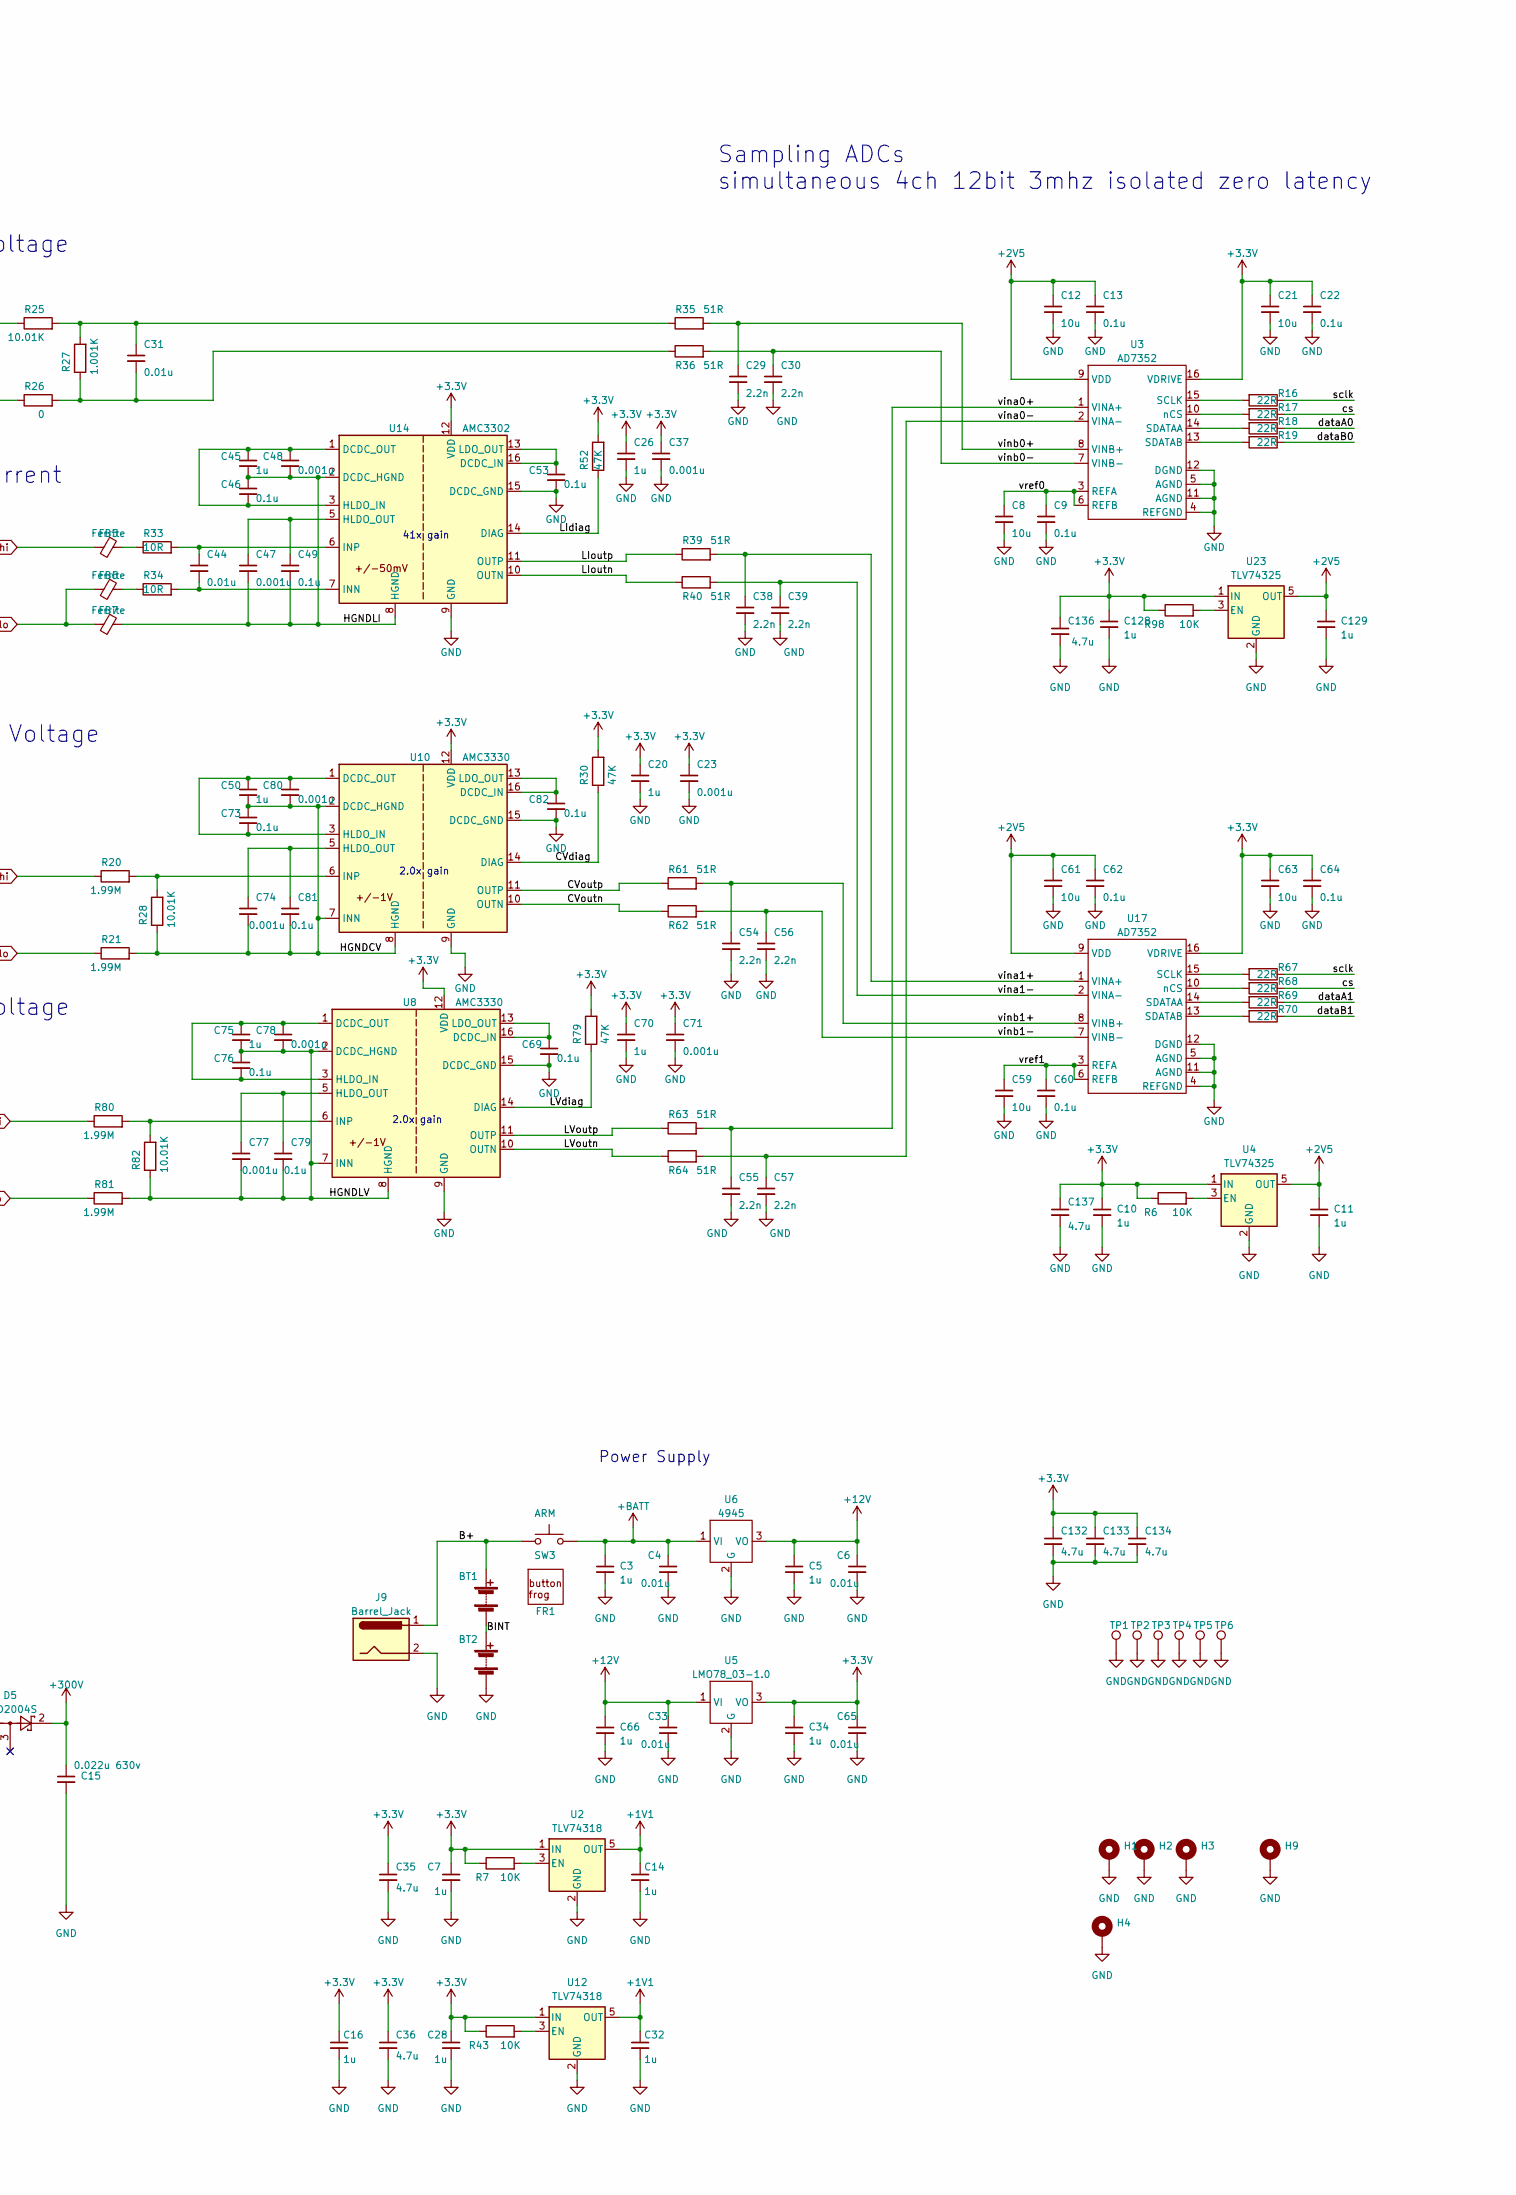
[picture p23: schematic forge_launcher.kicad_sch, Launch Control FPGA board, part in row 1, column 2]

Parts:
BT1, BT2: BatteryHolder_Keystone_2462_2xAA
C1, C3, C5, C7, C10, C11, C14, C16, C20, C26, C28, C32, C34, C40, C45, C50, C66, C70, C75, C128, C129: 1u; C_0603_1608Metric
C2, C4, C6, C31, C33, C44, C65: 0.01u; C_0603_1608Metric
C8, C12, C21, C59, C61, C63: 10u; C_1206_3216Metric
C9, C13, C22, C27, C46, C49, C53, C60, C62, C64, C69, C73, C76, C79, C81, C82, C83, C84: 0.1u; C_0603_1608Metric
C15: 0.022u 630v; C_1206_3216Metric
C17: 100u 20v; C_Radial_D5.0mm_H7.0mm_P2.00mm
C18, C19, C35, C36, C132, C133, C134, C135, C136, C137: 4.7u; C_1206_3216Metric
C23, C37, C47, C48, C71, C74, C77, C78, C80: 0.001u; C_0603_1608Metric
C24, C25: 100u 400V; CP_Radial_D16.0mm_P7.50mm
C29, C30, C38, C39, C54, C55, C56, C57: 2.2n; C_0603_1608Metric
D1: BAV99; SOT-23
D2: ARM; LED_0603_1608Metric
D4: CONT; LED_0603_1608Metric
D5: GSD2004S; SOT-23; JLC C85606
D6, D7: ES1J; D_SMA; JLC C99410
D9: ‎STPSC10065G2; TO-263-2_TabPin1; JLC C602663
FB5, FB6, FB7: Ferrite; L_0603_1608Metric
FR1, FR2: button_frog
GD1: GDT 500V; C_1812_4532Metric_Pad1.57x3.40mm_HandSolder
H1, H2, H3, H4, H9: MountingHole_3mm_Pad
J1, J2: Conn_02x13_Odd_Even
J4, J7: Jack; CalTest_CT3151
J5: Conn_01x06; PinHeader_2x03_P2.54mm_Vertical
J9: Barrel_Jack; BarrelJack_CUI_PJ-063AH_Horizontal
L1: 390uH 5A; L_Toroid_Vertical_L35.6mm_W17.8mm_P12.70mm_Pulse_E
LS1: Speaker; PUIAudio_SMT_0825_S_4_R
PS1: RM-1212S; Converter_DCDC_Murata_MEE1SxxxxSC_THT
Q1: STR2P3LLH6(Pfet); SOT-23
Q2: 2N3904; SOT-23
Q3, Q9, Q10: MMBT3904; SOT-23
Q4, Q6: IPD60R145; TO-252-2; JLC C3277918
Q5: IRLML0060TRPBF; SOT-23; JLC C3277918
R1, R2, R29: 100K; R_0603_1608Metric; JLC C319967
R4, R11: 10K; R_0603_1608Metric; JLC C319967
R5, R22, R33, R34: 10R; R_0603_1608Metric; JLC C778416
R6, R7, R43, R98: 10K; R_0603_1608Metric; JLC C778416
R8: 2K; R_0603_1608Metric; JLC C319700
R9, R12, R14, R53, R83: 10K; R_0603_1608Metric; JLC C491211
R10: 10K; R_0603_1608Metric
R13: 51.1K; R_0603_1608Metric; JLC C234563
R15, R31, R46, R108: 1K; R_0603_1608Metric; JLC C319967
R16, R17, R18, R19, R47, R48, R50, R54, R67, R68, R69, R70: 22R; R_0603_1608Metric; JLC C319967
R20, R21, R80, R81: 1.99M; R_0603_1608Metric; JLC C778416
R23, R105: 22R; R_0603_1608Metric; JLC C778416
R24, R49, R51, R99, R103, R104: 0R; R_0603_1608Metric; JLC C778416
R25, R28, R82: 10.01K; R_0603_1608Metric; JLC C778416
R26: 0; R_0603_1608Metric; JLC C778416
R27: 1.001K; R_0603_1608Metric; JLC C778416
R30, R52, R79: 47K; R_0603_1608Metric; JLC C778416
R32, R37, R38, R41, R42, R45: np; R_0603_1608Metric; JLC C319967
R35, R36, R39, R40, R61, R62, R63, R64: 51R; R_0603_1608Metric; JLC C778416
R44: 3k3; R_0603_1608Metric; JLC C319967
R55: 0; R_0603_1608Metric; JLC C319967
R102: 0.005R 1W; R_2818 current sense
R110: 0R; R_0603_1608Metric; JLC C319967
SW1: SW_SPST; SW_E-Switch_EG1224_SPDT_Angled
SW3: ARM; SW_SPST_HP03
SW10: LAUNCH; SW_SPST_HP03
TP1, TP2, TP3, TP4, TP5, TP6: TestPoint_Keystone_5000-5004_Miniature
TR1: PA0367A; PA0637A Pulse Coil 3D; JLC C5382098
U1: LT3420; MSOP-10_3x3mm_P0.5mm; JLC C670531
U2, U12: TLV74318; SOT-23-5
U3, U17: AD7352; TSSOP-16_4.4x5mm_P0.65mm
U4, U23: TLV74325; SOT-23-5
U5: LMO78_03-1.0; Converter_DCDC_Murata_OKI-78SR_Horizontal
U6: 4945; Converter_DCDC_Murata_OKI-78SR_Horizontal
U7: MCP1416; SOT-23-5
U8, U10: AMC3330; SOIC-16W_7.5x10.3mm_P1.27mm
U9, U19: QFN-24-3x3mm
U11: AT25xxx; SOIC-8_3.9x4.9mm_P1.27mm
U13: LM809; SOT-23
U14: AMC3302; SOIC-16W_7.5x10.3mm_P1.27mm
U18: IR2127; SOIC-8_3.9x4.9mm_P1.27mm; JLC C356723
X1: ASE-48MHz; Oscillator_SMD_Abracon_ASV-4Pin_7.0x5.1mm_HandSoldering

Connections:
+1V1: C14.1, C32.1, J1.3, U2.5 (OUT), U9.22 (VDD), U12.5 (OUT), U19.22 (VDD)
+2V5: C11.1, C12.1, C13.1, C61.1, C62.1, C129.1, U3.9 (VDD), U4.5 (OUT), U17.9 (VDD), U23.5 (OUT)
+3.3V: C7.1, C10.1, C16.1, C18.1, C20.1, C21.1, C22.1, C23.1, C26.1, C28.1, C34.1, C35.1, C36.1, C37.1, C63.1, C64.1, C65.1, C70.1, C71.1, C128.1, C132.1, C133.1, C134.1, C135.1, C136.1, C137.1, D1.3 (K), J2.4, J5.2, LS1.1, R6.1, R7.1, R15.2, R29.2, R30.2, R31.2, R37.2, R38.2, R43.1, R44.2, R46.2, R52.2, R53.1, R79.2, R83.1, R98.1, U1.4 (VCC), U2.1 (IN), U3.16 (VDRIVE), U4.1 (IN), U5.3 (VO), U8.12 (VDD), U9.21 (VDDIO), U10.12 (VDD), U11.8 (VCC), U12.1 (IN), U13.3 (VCC), U14.12 (VDD), U17.16 (VDRIVE), U19.21 (VDDIO), U23.1 (IN), X1.4 (Vdd)
+12V: C1.1, C2.1, C5.1, C6.1, C27.1, C33.1, C66.1, C83.1, D6.2 (A), PS1.2 (+Vin), R12.2, U5.1 (VI), U6.3 (VO), U7.2 (Vdd), U18.1 (VCC)
+BATT: C3.1, C4.1, C19.1, R25.1, SW3.2, TR1.3, U1.2 (VBAT), U6.1 (VI)
+VSW: C84.2, D9.1 (K), PS1.3 (-Vout), Q4.3 (S), R49.1, R102.2, U18.5 (VS), U18.6 (CS)
/+OUT: GD1.1, J4.1, L1.2, R24.2
/B+: BT1.1 (+), J9.1, SW3.1
/BINT: BT1.2 (-), BT2.1 (+)
/CVdiag: R30.1, U10.14 (DIAG)
/CVoutn: R62.1, U10.10 (OUTN)
/CVoutp: R61.1, U10.11 (OUTP)
/DisG: Q6.1 (G), R110.2
/HGNDCV: C50.2, C73.1, C74.2, C80.2, C81.2, R21.2, R28.1, U10.2 (DCDC_HGND), U10.7 (INN), U10.8 (HGND)
/HGNDLI: C45.2, C46.1, C47.2, C48.2, C49.2, FB7.1, U14.2 (DCDC_HGND), U14.8 (HGND)
/HGNDLV: C75.2, C76.1, C77.2, C78.2, C79.2, R81.2, R82.1, U8.2 (DCDC_HGND), U8.7 (INN), U8.8 (HGND)
/LIdiag: R52.1, U14.14 (DIAG)
/LIoutn: R40.1, U14.10 (OUTN)
/LIoutp: R39.1, U14.11 (OUTP)
/LSEN: GD1.3, L1.1, R102.1, R103.1
/LVdiag: R79.1, U8.14 (DIAG)
/LVoutn: R64.1, U8.10 (OUTN)
/LVoutp: R63.1, U8.11 (OUTP)
/SW: Q5.2 (D), R13.2, TR1.2, U1.6 (SW)
/arm_led: J1.25, R11.2, U9.9 (GPIO18), U19.9 (GPIO18)
/arm_led_oc: D2.1 (K), Q9.3 (C)
/charge: J2.6, R23.1, U9.20 (GPIO7), U19.20 (GPIO7)
/cont_led: J1.5, R4.2, U9.23 (GPIO8), U19.23 (GPIO8)
/cont_led_oc: D4.1 (K), Q10.3 (C)
/cs: J1.21, R17.1, R68.1, U9.7 (GPIO16), U19.7 (GPIO16)
/dataA0: J1.13, R18.1, U9.3 (GPIO12), U19.3 (GPIO12)
/dataA1: J1.17, R69.1, U9.5 (GPIO14), U19.5 (GPIO14)
/dataB0: J1.15, R19.1, U9.4 (GPIO13), U19.4 (GPIO13)
/dataB1: J1.19, R70.1, U9.6 (GPIO15), U19.6 (GPIO15)
/done: R29.1, U1.8 (DONE)
/dump: J1.9, R10.1, U9.1 (GPIO10), U19.1 (GPIO10)
/gate: Q4.1 (G), R22.2
/launch_n: J1.7, R50.1, U9.24 (GPIO9), U19.24 (GPIO9)
/mute_n: J2.18, R54.1, U9.14 (GPIO1), U19.14 (GPIO1)
/osc: J2.16, R47.1, U9.15 (GPIO2/refCLK), U19.15 (GPIO2/refCLK)
/pwm: J1.23, R105.1, U9.8 (GPIO17), U19.8 (GPIO17)
/pwmr: R9.2, R105.2, U18.2 (IN)
/reset_n: J2.24, R48.1, U9.11 (nRST), U19.11 (nRST)
/sclk: J1.11, R16.1, R67.1, U9.2 (GPIO11), U19.2 (GPIO11)
/sleep_n: J2.26, U9.10 (nSLEEP), U19.10 (nSLEEP)
/speaker: J2.20, R108.1, U9.13 (GPIO0), U19.13 (GPIO0)
/spi_ck: J2.14, J5.4, U9.16 (GPIO3/SPI_CK), U11.6 (SCK), U19.16 (GPIO3/SPI_CK)
/spi_si: J2.10, J5.1, U9.18 (GPIO5/SPI_SI), U11.5 (MOSI), U19.18 (GPIO5/SPI_SI)
/spi_so: J2.8, J5.3, U9.19 (GPIO6/SPI_SO), U11.2 (MISO), U19.19 (GPIO6/SPI_SO)
/spi_ss: J2.12, J5.6, R44.1, R45.2, U9.17 (GPIO4/SPI_SS), U11.1 (~CS), U19.17 (GPIO4/SPI_SS)
/vina0+: C55.1, R63.2, U3.1 (VINA+)
/vina0-: C57.1, R64.2, U3.2 (VINA-)
/vina1+: C38.1, R39.2, U17.1 (VINA+)
/vina1-: C39.1, R40.2, U17.2 (VINA-)
/vinb0+: C29.1, R35.2, U3.8 (VINB+)
/vinb0-: C30.1, R36.2, U3.7 (VINB-)
/vinb1+: C54.1, R61.2, U17.8 (VINB+)
/vinb1-: C56.1, R62.2, U17.7 (VINB-)
/vref0: C8.1, C9.1, U3.3 (REFA), U3.6 (REFB)
/vref1: C59.1, C60.1, U17.3 (REFA), U17.6 (REFB)
CVhi: R20.1, R99.1
CVlo: R21.1, R51.1
GND: BT2.2 (-), C1.2, C2.2, C3.2, C4.2, C5.2, C6.2, C7.2, C8.2, C9.2, C10.2, C11.2, C12.2, C13.2, C14.2, C15.2, C16.2, C17.2, C18.2, C19.2, C20.2, C21.2, C22.2, C23.2, C24.2, C25.2, C26.2, C27.2, C28.2, C29.2, C30.2, C32.2, C33.2, C34.2, C35.2, C36.2, C37.2, C38.2, C39.2, C40.2, C53.2, C54.2, C55.2, C56.2, C57.2, C59.2, C60.2, C61.2, C62.2, C63.2, C64.2, C65.2, C66.2, C69.2, C70.2, C71.2, C82.2, C83.2, C128.2, C129.2, C132.2, C133.2, C134.2, C135.2, C136.2, C137.2, D9.2 (A), H1.1, H2.1, H3.1, H4.1, H9.1, J1.1, J1.2, J1.4, J1.6, J1.8, J1.10, J1.12, J1.14, J1.16, J1.18, J1.20, J1.22, J1.24, J1.26, J2.1, J2.2, J2.3, J2.5, J2.7, J2.9, J2.11, J2.13, J2.15, J2.17, J2.19, J2.21, J2.22, J2.23, J2.25, J5.5, J7.1, J9.2, PS1.1 (-Vin), Q2.1 (E), Q3.2 (E), Q5.3 (S), Q6.3 (S), Q9.2 (E), Q10.2 (E), R1.1, R2.1, R8.2, R9.1, R14.1, R26.1, R32.1, R41.1, R42.1, R45.1, R51.2, R104.2, SW1.1 (A), SW10.1, TP1.1, TP2.1, TP3.1, TP4.1, TP5.1, TP6.1, U1.5 (GND), U2.2 (GND), U3.4 (REFGND), U3.5 (AGND), U3.11 (AGND), U3.12 (DGND), U4.2 (GND), U5.2 (G), U6.2 (G), U7.4 (GND), U8.9 (GND), U8.15 (DCDC_GND), U9.12 (GND), U10.9 (GND), U10.15 (DCDC_GND), U11.4 (GND), U12.2 (GND), U13.1 (GND), U14.9 (GND), U14.15 (DCDC_GND), U17.4 (REFGND), U17.5 (AGND), U17.11 (AGND), U17.12 (DGND), U18.4 (COM), U19.12 (GND), U23.2 (GND), X1.2 (GND)
LIhi: FB5.2, R49.2
LIlo: FB6.2, FB7.2, R103.2
LVhi: R24.1, R80.1
LVlo: R81.1, R104.1
unnamed: C31.1, R25.2, R27.2, R35.1
unnamed: C31.2, R26.2, R27.1, R36.1
unnamed: D2.2 (A), R15.1
unnamed: D4.2 (A), R31.1
unnamed: D5.1, TR1.4
unnamed: C17.1, D6.1 (K), Q1.2 (S)
unnamed: D7.2 (A), Q2.3 (C), R12.1
unnamed: D7.1 (K), Q1.1 (G), R1.2
unnamed: FB5.1, R33.1
unnamed: C84.1, PS1.4 (+Vout), U18.8 (VB)
unnamed: Q1.3 (D), R2.2, R110.1
unnamed: Q2.2 (B), R10.2
unnamed: Q3.1 (B), R108.2
unnamed: D1.1 (K), LS1.2, Q3.3 (C)
unnamed: Q5.1 (G), R5.2
unnamed: Q9.1 (B), R11.1
unnamed: Q10.1 (B), R4.1
unnamed: R32.2, R55.1, TR1.1
unnamed: R50.2, R83.2, SW10.2
unnamed: R53.2, R54.2, SW1.2 (B)
unnamed: R14.2, R23.2, U1.9 (CHRG), U7.3 (IN)
unnamed: C40.1, U1.10 (CT)
unnamed: R13.1, U1.3 (RFB)
unnamed: R8.1, U1.1 (RREF)
unnamed: R55.2, U1.7 (SEC)
unnamed: R7.2, U2.3 (EN)
unnamed: R16.2, U3.15 (SCLK)
unnamed: R18.2, U3.14 (SDATAA)
unnamed: R19.2, U3.13 (SDATAB)
unnamed: R17.2, U3.10 (nCS)
unnamed: R6.2, U4.3 (EN)
unnamed: R5.1, U7.5 (OUT)
unnamed: C69.1, U8.13 (LDO_OUT), U8.16 (DCDC_IN)
unnamed: C75.1, C76.2, C78.1, U8.1 (DCDC_OUT), U8.3 (HLDO_IN)
unnamed: C77.1, C79.1, U8.5 (HLDO_OUT)
unnamed: R80.2, R82.2, U8.6 (INP)
unnamed: C82.1, U10.13 (LDO_OUT), U10.16 (DCDC_IN)
unnamed: C50.1, C73.2, C80.1, U10.1 (DCDC_OUT), U10.3 (HLDO_IN)
unnamed: C74.1, C81.1, U10.5 (HLDO_OUT)
unnamed: R20.2, R28.2, U10.6 (INP)
unnamed: R37.1, R42.2, U11.7 (~HOLD)
unnamed: R38.1, R41.2, U11.3 (~WP)
unnamed: R43.2, U12.3 (EN)
unnamed: R48.2, U13.2 (~RESET)
unnamed: C53.1, U14.13 (LDO_OUT), U14.16 (DCDC_IN)
unnamed: C45.1, C46.2, C48.1, U14.1 (DCDC_OUT), U14.3 (HLDO_IN)
unnamed: C47.1, C49.1, U14.5 (HLDO_OUT)
unnamed: C44.1, R33.2, U14.6 (INP)
unnamed: R67.2, U17.15 (SCLK)
unnamed: R69.2, U17.14 (SDATAA)
unnamed: R70.2, U17.13 (SDATAB)
unnamed: R68.2, U17.10 (nCS)
unnamed: R22.1, U18.7 (HO)
unnamed: R98.2, U23.3 (EN)
unnamed: R46.1, X1.1 (EN)
unnamed: R47.2, X1.3 (OUT)

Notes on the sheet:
600V
Power-off Discharge
Igniter
Quad ADC
Capacitor Voltage
41x gain
Coil
Capacitor Voltage Sense 1V/401V
Output Voltage
SPI
Ishunt
Output Voltage Sense 1V/401V
Sampling ADCs simultaneous 4ch 12bit 3mhz isolated zero latency
CAP
2.0x gain
FPGA
25V
IC Charger
System
Pwr Ctl
FPanel
ALT FPGA
Discharge Energy Sink Resistor
60V 3A
Power Supply
Power Stage
Output Current
Battery Voltage
Load Current Sense 10mV/A 0.005 ohms
Capacitor Discharger operates whenever power is removed (release of ARM button), by using a small, low voltage, diode charged capacitor to turn on a mosfet to discharge the high voltage capacitors into a resistor. Fpga controlled dump over-ride provided.
1:12 Flyback Transformer
LCC Charger

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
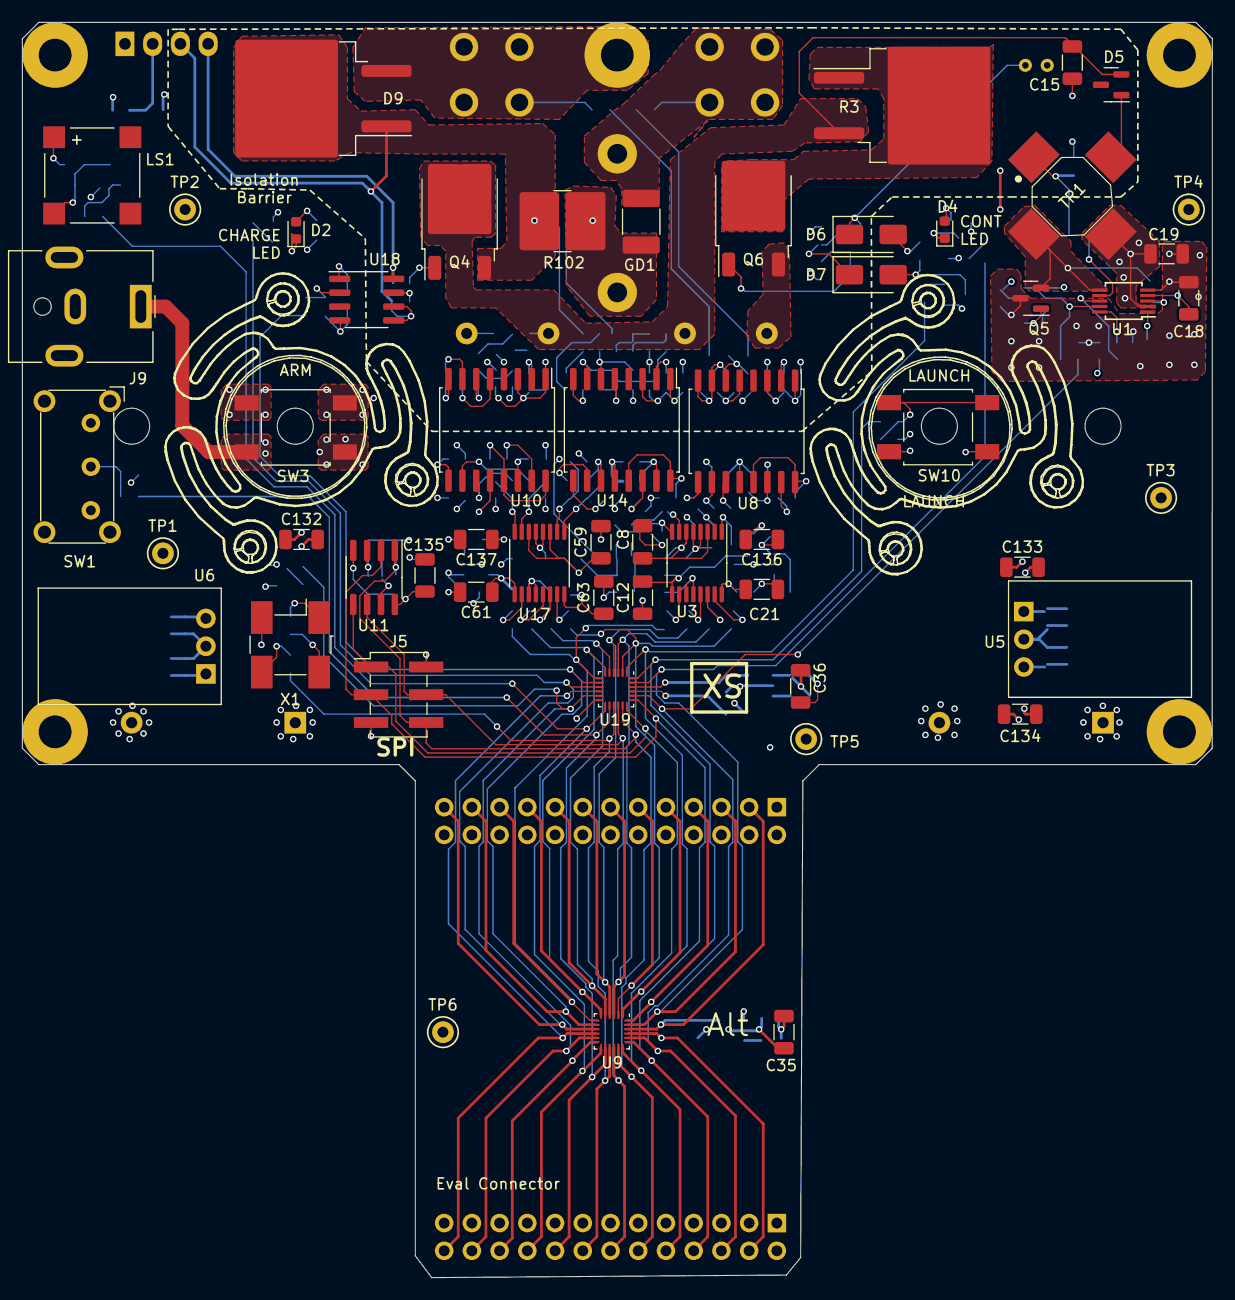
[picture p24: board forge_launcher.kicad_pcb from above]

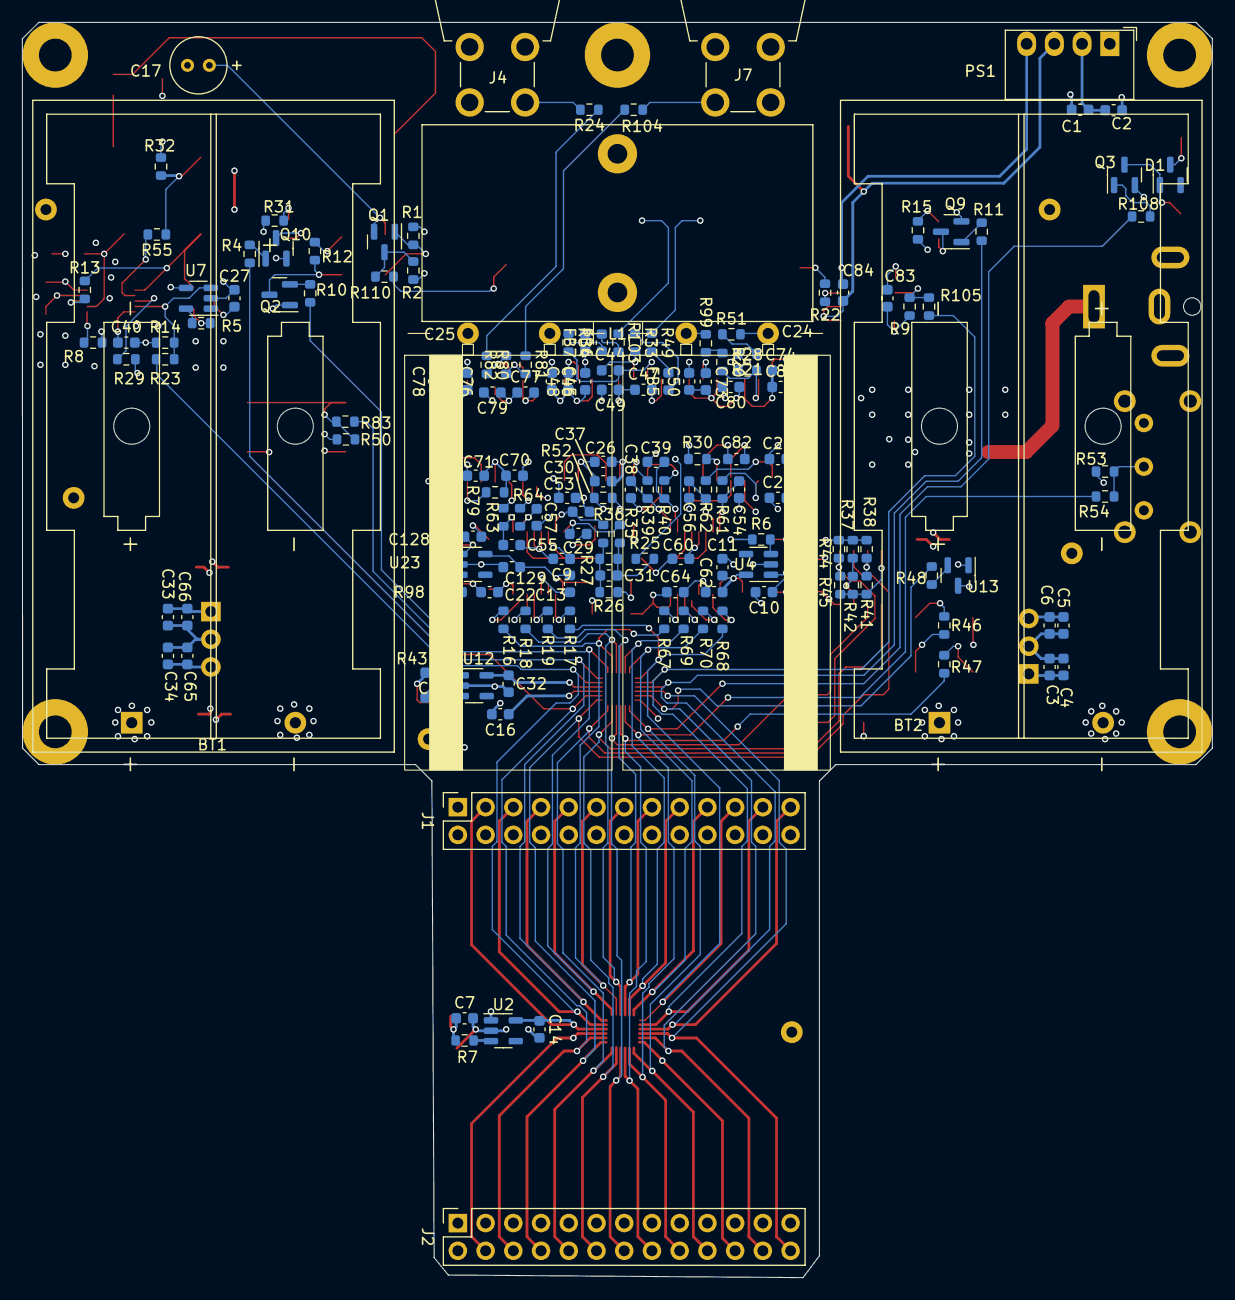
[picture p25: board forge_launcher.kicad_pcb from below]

Board: 6 copper layers, 109.0 x 115.0 mm, 225 parts (163 on the bottom side), 127 nets.

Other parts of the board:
R3: 3K3 25W; TO-263-2_TabPin1

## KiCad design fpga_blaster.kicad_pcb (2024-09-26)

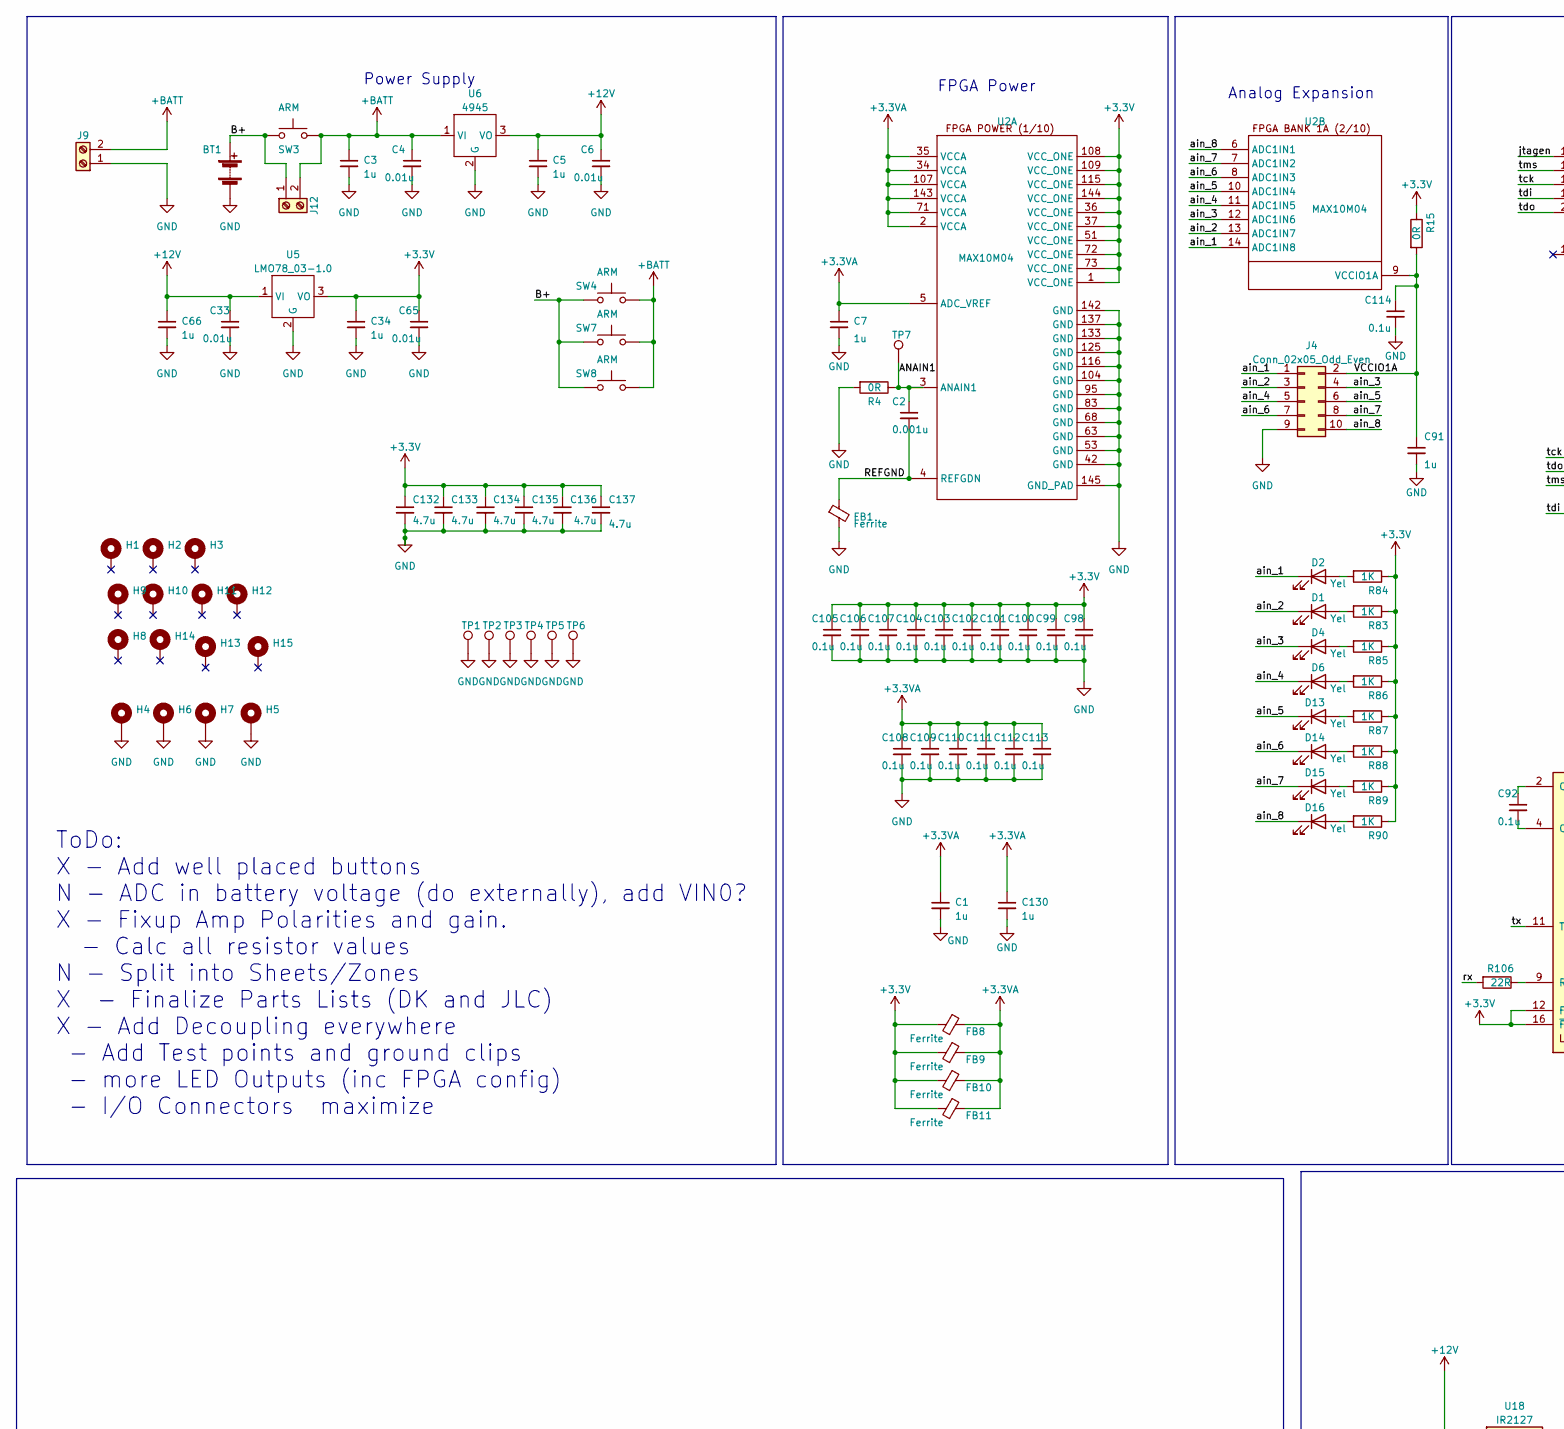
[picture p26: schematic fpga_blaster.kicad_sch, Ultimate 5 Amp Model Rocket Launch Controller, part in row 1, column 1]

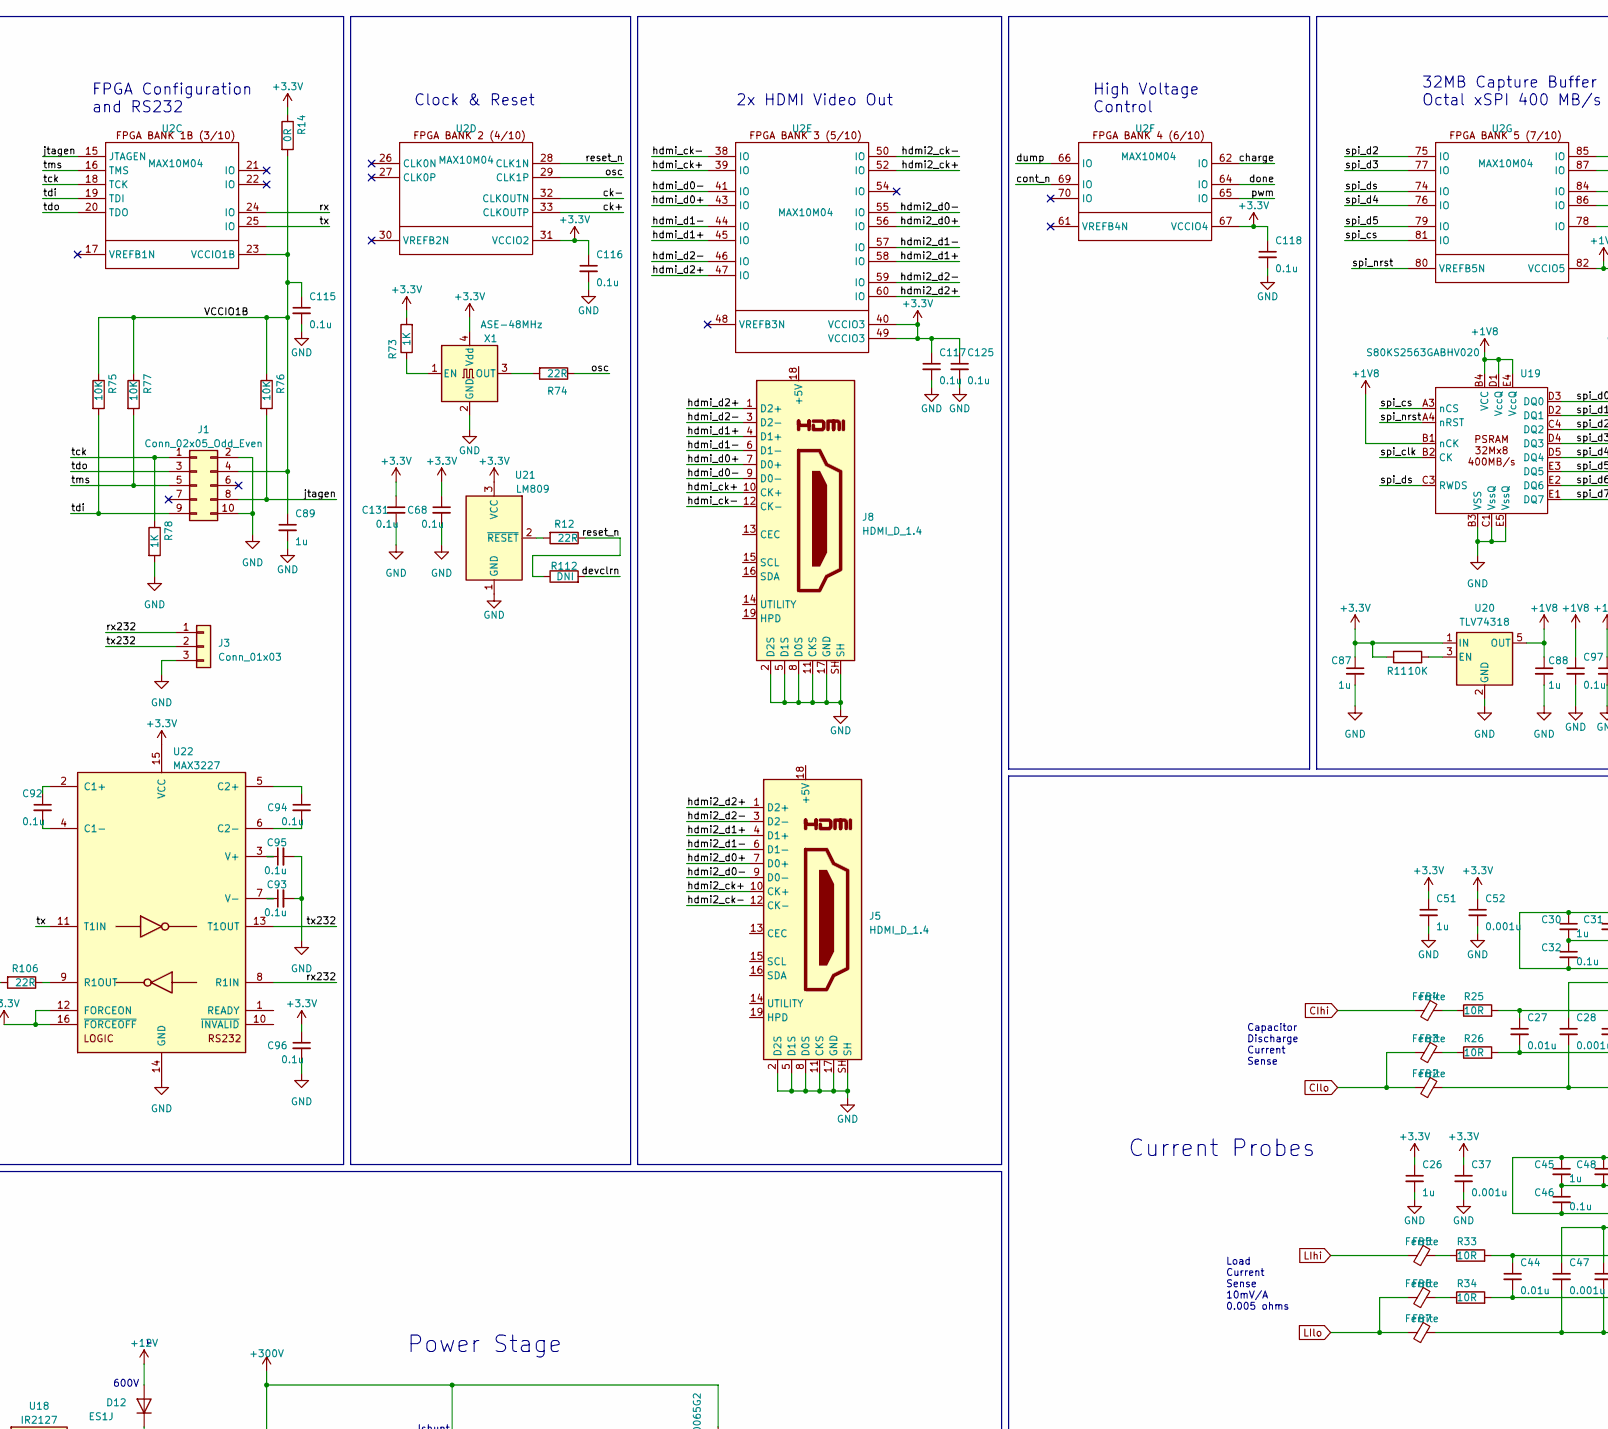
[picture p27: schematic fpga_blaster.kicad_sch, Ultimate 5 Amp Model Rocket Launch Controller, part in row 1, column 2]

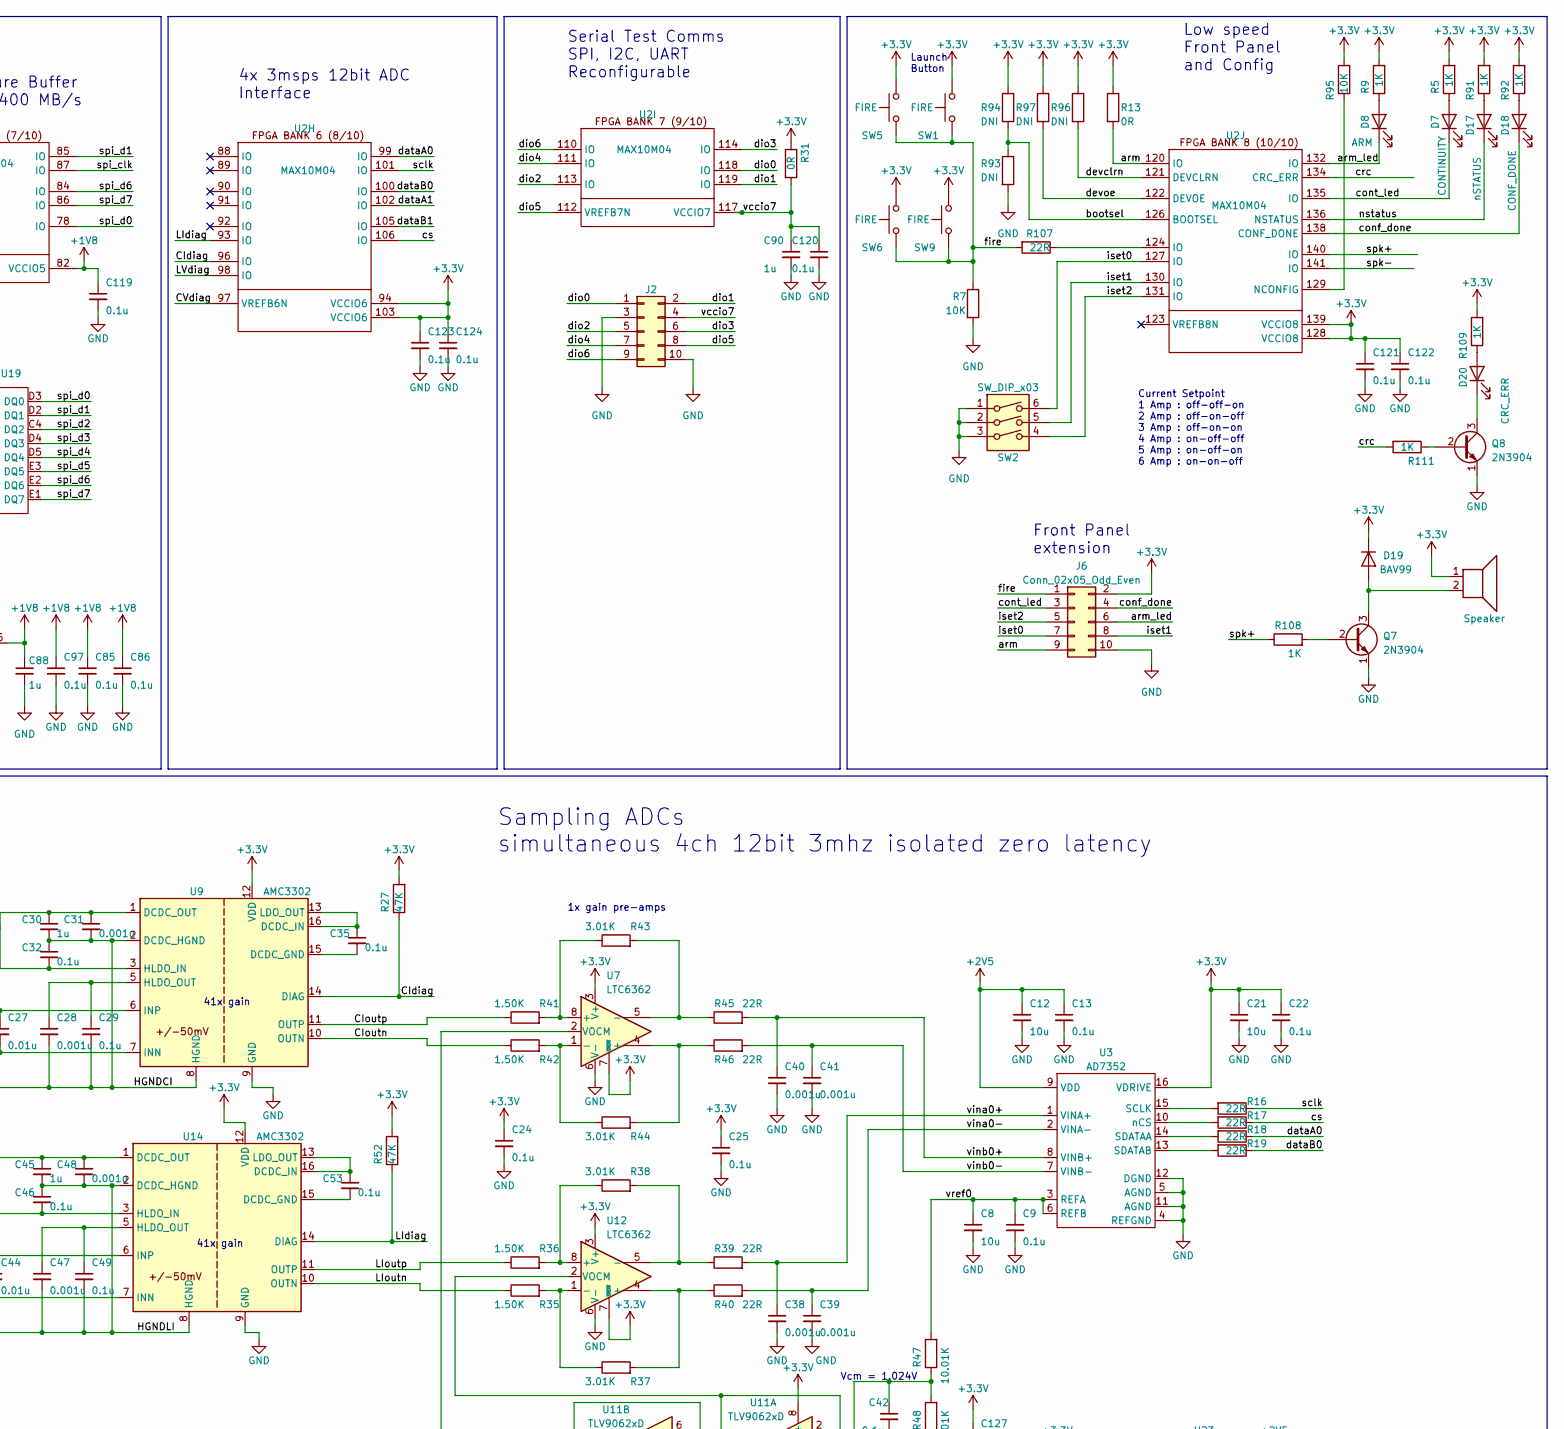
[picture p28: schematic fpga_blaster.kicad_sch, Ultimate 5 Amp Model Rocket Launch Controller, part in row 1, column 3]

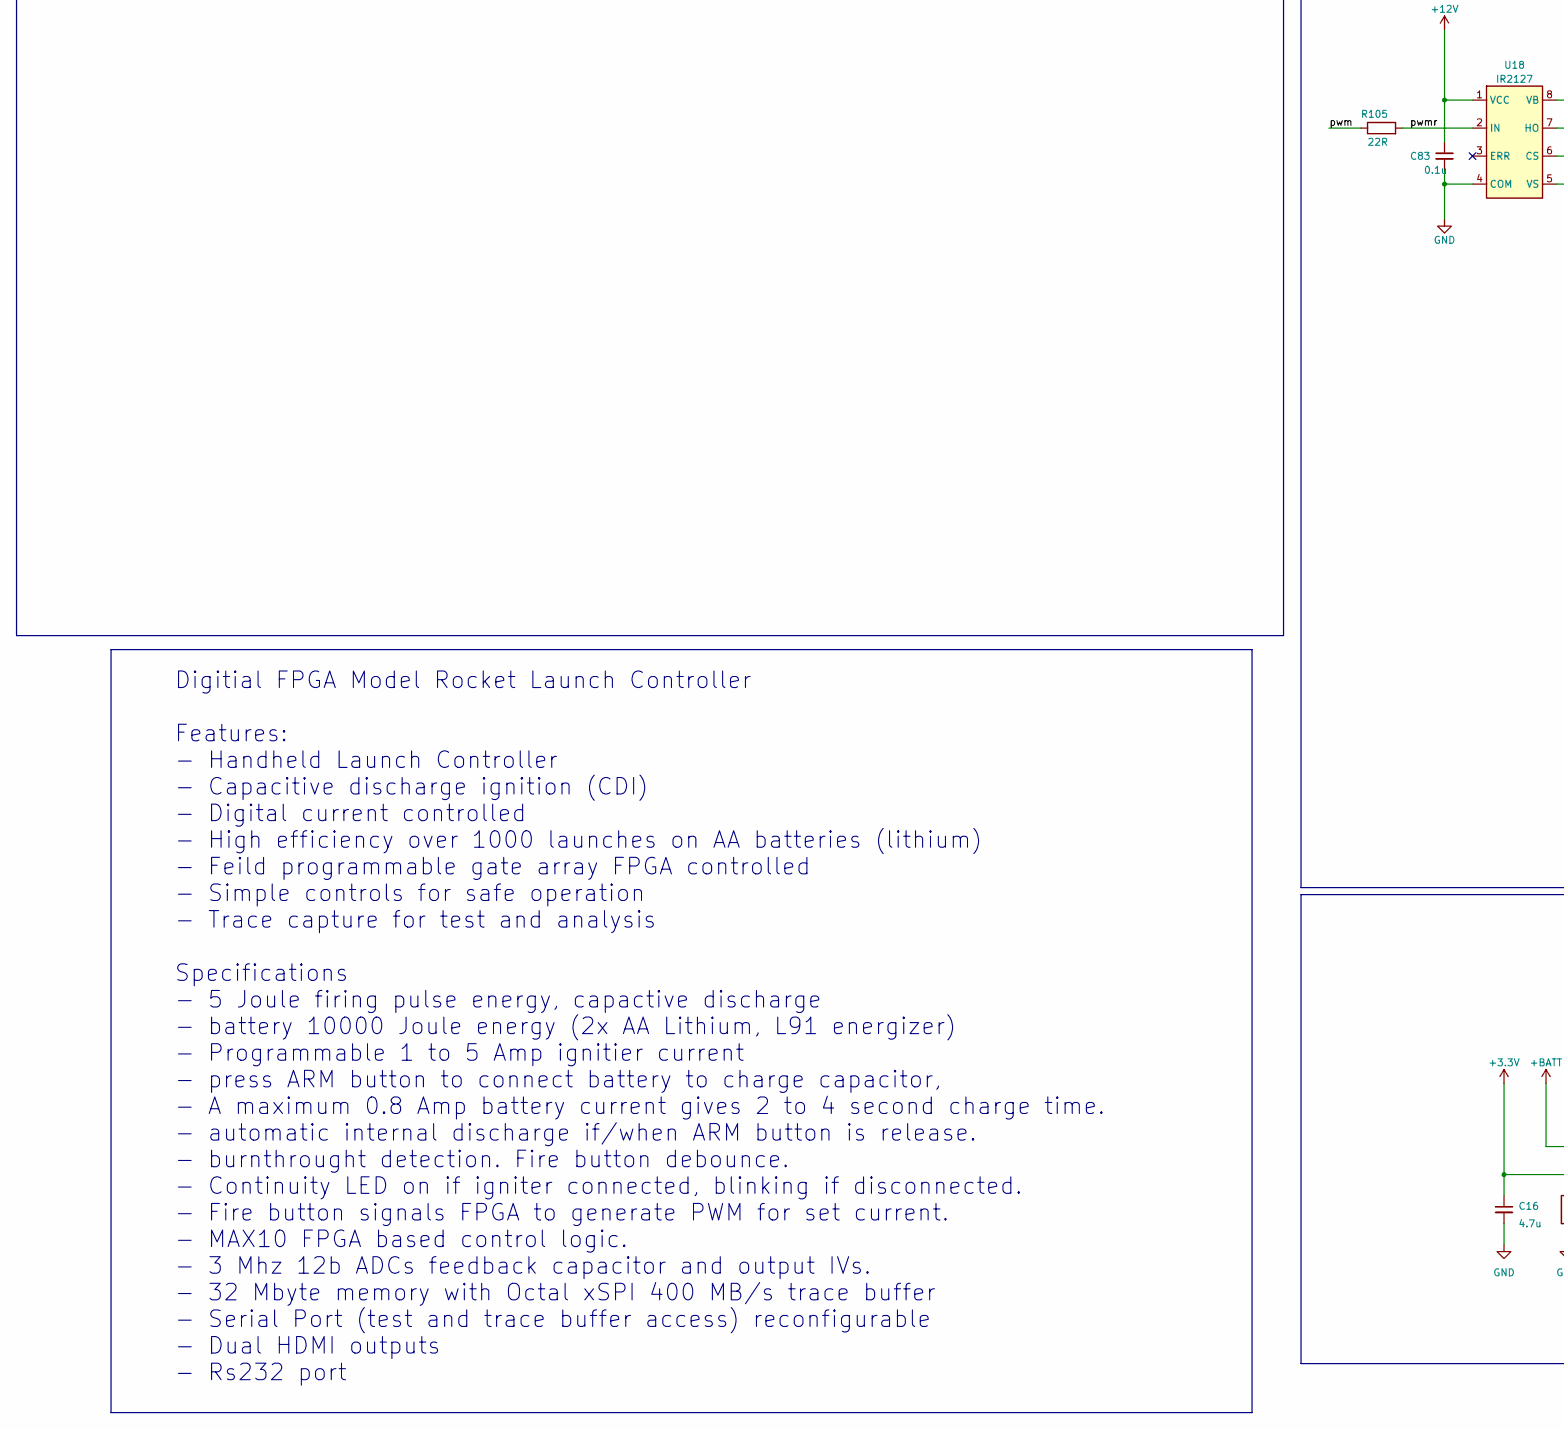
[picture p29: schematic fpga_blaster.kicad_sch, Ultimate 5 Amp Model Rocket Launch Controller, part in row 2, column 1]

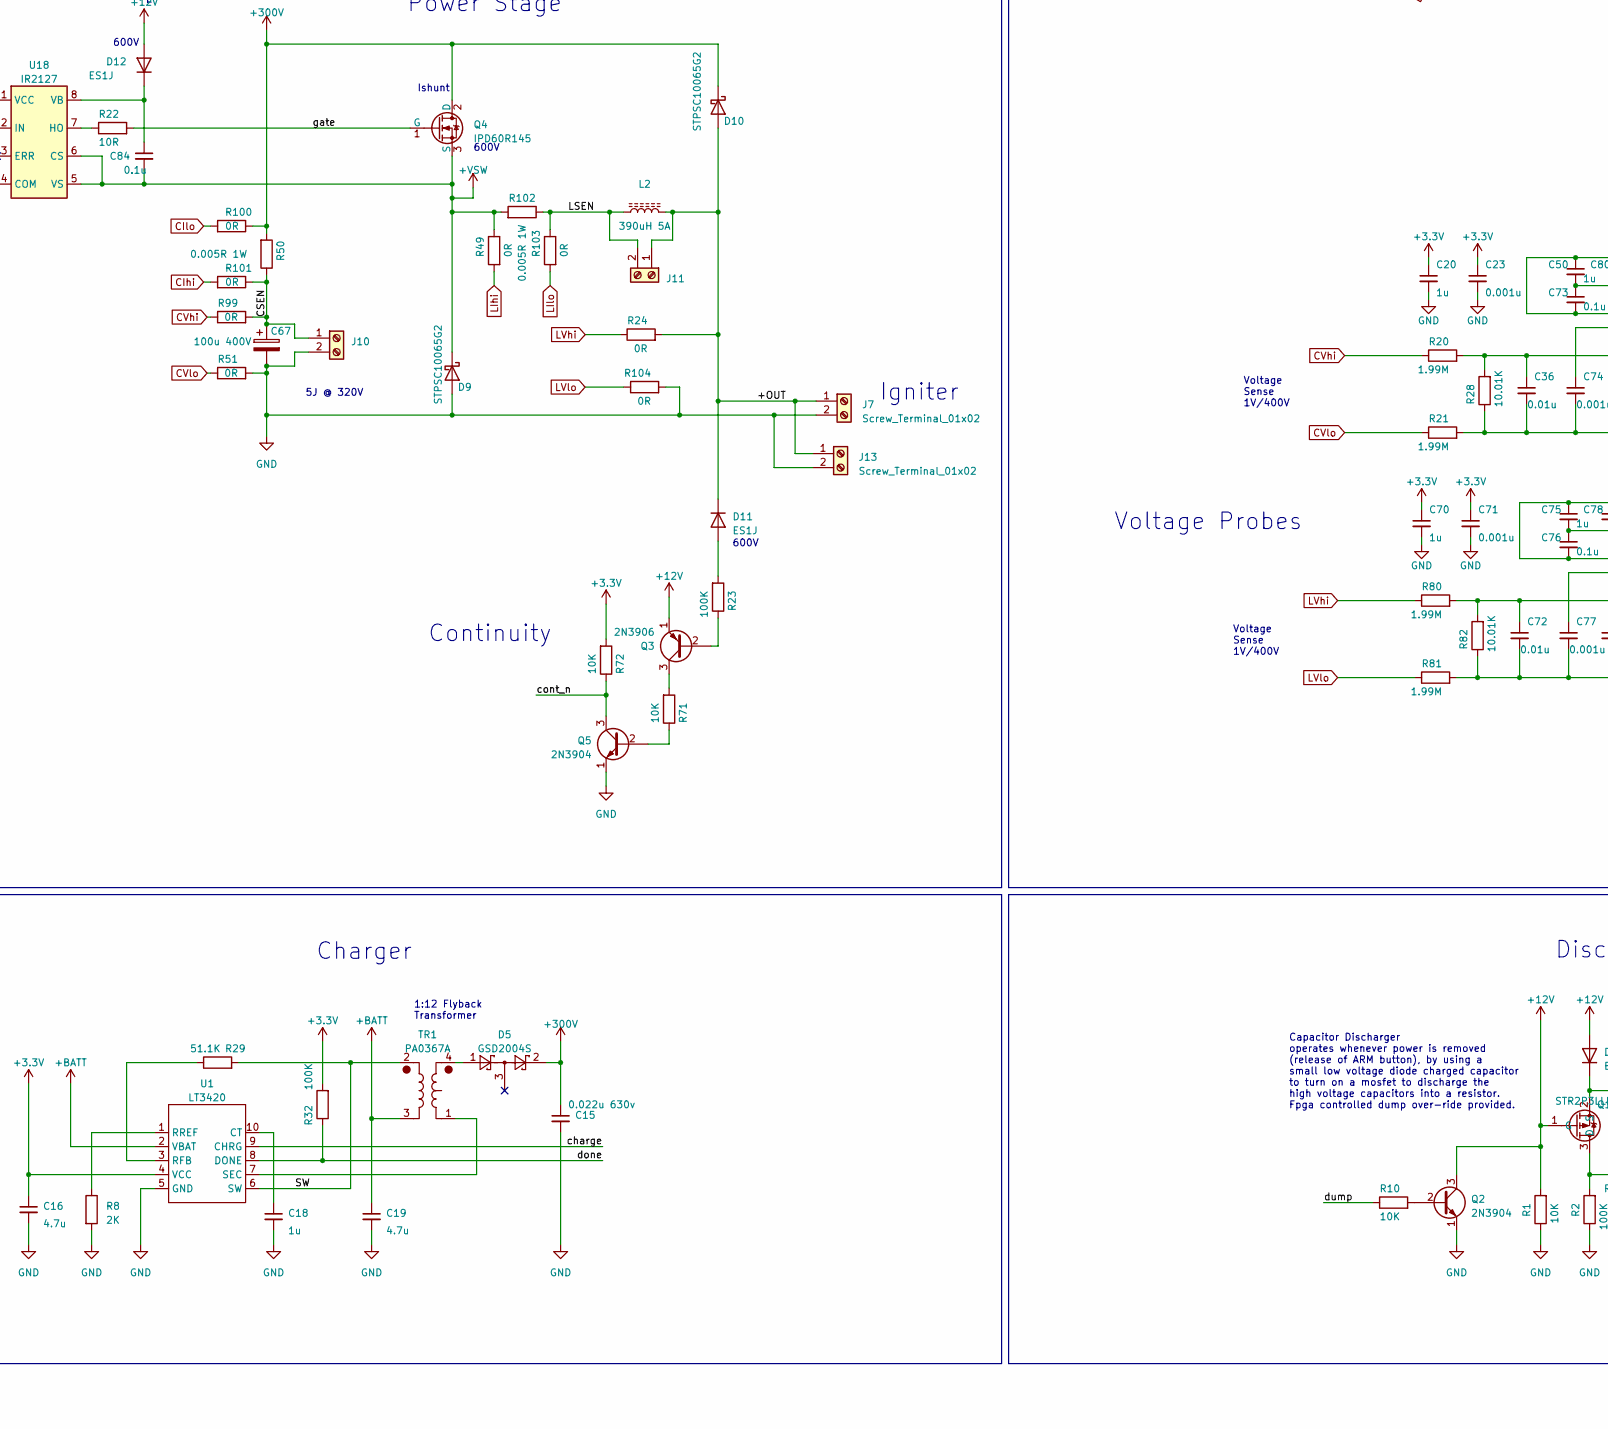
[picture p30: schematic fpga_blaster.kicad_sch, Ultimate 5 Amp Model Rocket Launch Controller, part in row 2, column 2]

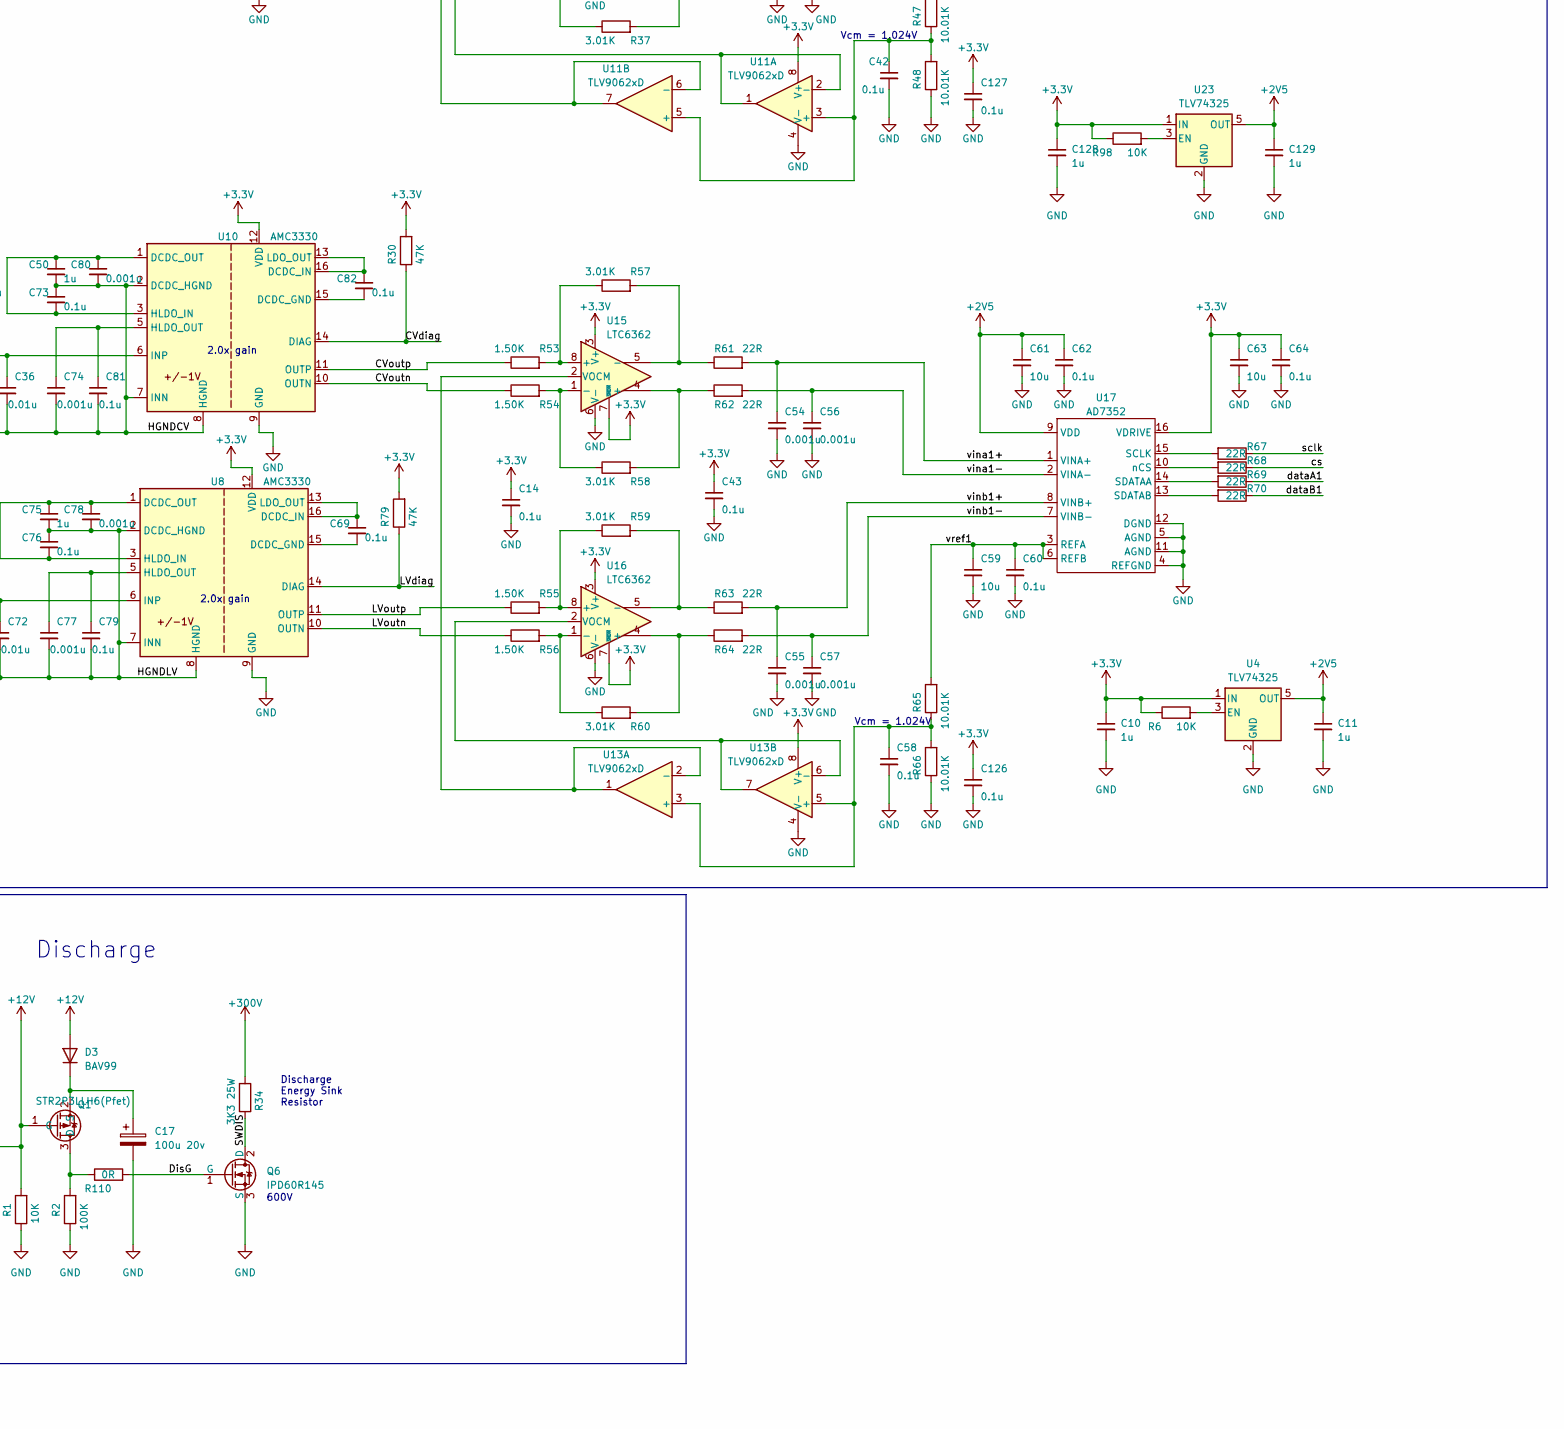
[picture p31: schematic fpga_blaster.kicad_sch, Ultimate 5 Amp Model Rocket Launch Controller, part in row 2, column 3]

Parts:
BT1: BatteryHolder_Keystone_2462_2xAA
C1, C3, C5, C7, C10, C11, C18, C20, C26, C30, C34, C45, C50, C51, C66, C70, C75, C87, C88, C89, C90, C91, C128, C129, C130: 1u; C_0603_1608Metric
C2, C23, C28, C31, C37, C38, C39, C40, C41, C47, C48, C52, C54, C55, C56, C57, C71, C74, C77, C78, C80: 0.001u; C_0603_1608Metric
C4, C6, C27, C33, C36, C44, C65, C72: 0.01u; C_0603_1608Metric
C8, C12, C21, C59, C61, C63: 10u; C_1206_3216Metric
C9, C13, C14, C22, C24, C25, C29, C32, C35, C42, C43, C46, C49, C53, C58, C60, C62, C64, C68, C69, C73, C76, C79, C81, C82, C83, C84, C85, C86, C92, C93, C94, C95, C96, C97, C98, C99, C100, C101, C102, C103, C104, C105, C106, C107, C108, C109, C110, C111, C112, C113, C114, C115, C116, C117, C118, C119, C120, C121, C122, C123, C124, C125, C126, C127, C131: 0.1u; C_0603_1608Metric
C15: 0.022u 630v; C_1206_3216Metric
C16, C19, C132, C133, C134, C135, C136, C137: 4.7u; C_1206_3216Metric
C17: 100u 20v; C_Radial_D5.0mm_H7.0mm_P2.00mm
C67: 100u 400V; CP_Radial_D16.0mm_P7.50mm
D1, D2, D4, D6, D13, D14, D15, D16: Yel; LED_0603_1608Metric
D3, D19: BAV99; SOT-23; JLC C7420336
D5: GSD2004S; SOT-23; JLC C85606
D7: CONTINUITY; LED_0603_1608Metric
D8: ARM; LED_0603_1608Metric
D9, D10: ‎STPSC10065G2; TO-263-2_TabPin1; JLC C602663
D11, D12: ES1J; D_SMA; JLC C99410
D17: nSTATUS; LED_0603_1608Metric
D18: CONF_DONE; LED_0603_1608Metric
D20: CRC_ERR; LED_0603_1608Metric
FB1, FB2, FB3, FB4, FB5, FB6, FB7, FB8, FB9, FB10, FB11: Ferrite; L_0603_1608Metric
H1, H2, H3, H4, H5, H6, H7, H8, H9, H10, H11, H12, H13, H14, H15: MountingHole_3mm_Pad
J1, J2, J4, J6: Conn_02x05_Odd_Even; PinHeader_2x05_P2.54mm_Vertical
J3: Conn_01x03; PinHeader_1x03_P2.54mm_Vertical
J5, J8: HDMI_D_1.4; HDMI_A_Amphenol_10029449-x01xLF_Horizontal
J7, J9, J10, J11, J12, J13: Screw_Terminal_01x02; TerminalBlock_Phoenix_MKDS-1,5-2-5.08_1x02_P5.08mm_Horizont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
L2: 390uH 5A; L_Toroid_Vertical_L35.6mm_W17.8mm_P12.70mm_Pulse_E
LS1: Speaker; PUIAudio_SMT_0825_S_4_R
Q1: STR2P3LLH6(Pfet); SOT-23
Q2, Q5, Q7, Q8: 2N3904; SOT-23
Q3: 2N3906; SOT-23; JLC C909755
Q4, Q6: IPD60R145; TO-252-2; JLC C3277918
R1, R7: 10K; R_0603_1608Metric; JLC C491211
R2, R32: 100K; R_0603_1608Metric; JLC C319967
R4, R13: 0R; R_0603_1608Metric; JLC C491211
R5, R9, R73, R78, R83, R84, R85, R86, R87, R88, R89, R90, R91, R92, R108, R109, R111: 1K; R_0603_1608Metric; JLC C319967
R6, R11, R98: 10K; R_0603_1608Metric; JLC C778416
R8: 2K; R_0603_1608Metric; JLC C319700
R10, R71, R72: 10K; R_0603_1608Metric
R12, R16, R17, R18, R19, R67, R68, R69, R70, R74, R106, R107: 22R; R_0603_1608Metric; JLC C319967
R14, R15, R31, R110: 0R; R_0603_1608Metric; JLC C319967
R20, R21, R80, R81: 1.99M; R_0603_1608Metric; JLC C778416
R22, R25, R26, R33, R34: 10R; R_0603_1608Metric; JLC C778416
R23: 100K; R_0603_1608Metric; JLC C491211
R24, R49, R51, R99, R100, R101, R103, R104: 0R; R_0603_1608Metric; JLC C778416
R27, R30, R52, R79: 47K; R_0603_1608Metric; JLC C778416
R28, R47, R48, R65, R66, R82: 10.01K; R_0603_1608Metric; JLC C778416
R29: 51.1K; R_0603_1608Metric; JLC C234563
R35, R36, R41, R42, R53, R54, R55, R56: 1.50K; R_0603_1608Metric; JLC C778416
R37, R38, R43, R44, R57, R58, R59, R60: 3.01K; R_0603_1608Metric; JLC C778416
R39, R40, R45, R46, R61, R62, R63, R64, R105: 22R; R_0603_1608Metric; JLC C778416
R50, R102: 0.005R 1W; R_2818 current sense
R75, R76, R77, R95: 10K; R_0603_1608Metric; JLC C319967
R93, R94, R96, R97, R112: DNI; R_0603_1608Metric; JLC C491211
SW1, SW5, SW6, SW9: FIRE; SW_SPST_HP03
SW2: SW_DIP_x03; SW_DIP_SPSTx03_Slide_Omron_A6S-310x_W8.9mm_P2.54mm
SW3, SW4, SW7, SW8: ARM; SW_SPST_HP03
TP1, TP2, TP3, TP4, TP5, TP6, TP7: TestPoint_Keystone_5000-5004_Miniature
TR1: PA0367A; PA0637A Pulse Coil; JLC C5382098
U1: LT3420; MSOP-10_3x3mm_P0.5mm; JLC C670531
U2: MAX10M04; EQFP-144-1EP_20x20mm_P0.5mm_EP8.93x8.7mm_ThermalVias
U3, U17: AD7352; TSSOP-16_4.4x5mm_P0.65mm
U4, U23: TLV74325; SOT-23-5
U5: LMO78_03-1.0; TO-220-3_Vertical
U6: 4945; TO-220-3_Vertical
U7, U12, U15, U16: LTC6362; MSOP-8_3x3mm_P0.65mm
U8, U10: AMC3330; SOIC-16W_7.5x10.3mm_P1.27mm
U9, U14: AMC3302; SOIC-16W_7.5x10.3mm_P1.27mm
U11, U13: TLV9062xD; SOT-23-8
U18: IR2127; SOIC-8_3.9x4.9mm_P1.27mm; JLC C356723
U19: S80KS2563GABHV020; FBGA-24_6mmx8mm_Layout5x5_P1.00mm
U20: TLV74318; SOT-23-5
U21: LM809; SOT-23
U22: MAX3227; SSOP-16_5.3x6.2mm_P0.65mm
X1: ASE-48MHz; Oscillator_SMD_Abracon_ASV-4Pin_7.0x5.1mm_HandSoldering

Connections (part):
+1V8: C85.1, C86.1, C88.1, C97.1, C119.1, U2.82 (VCCIO5), U19.B1 (nCK), U19.B4 (VCC), U19.D1 (VccQ), U19.E4 (VccQ), U20.5 (OUT)
+2V5: C11.1, C12.1, C13.1, C61.1, C62.1, C129.1, U3.9 (VDD), U4.5 (OUT), U17.9 (VDD), U23.5 (OUT)
+3.3V: C10.1, C14.1, C16.1, C20.1, C21.1, C22.1, C23.1, C24.1, C25.1, C26.1, C34.1, C37.1, C43.1, C51.1, C52.1, C63.1, C64.1, C65.1, C68.1, C70.1, C71.1, C87.1, C96.1, C98.1, C99.1, C100.1, C101.1, C102.1, C103.1, C104.1, C105.1, C106.1, C107.1, C116.1, C117.1, C118.1, C121.1, C122.1, C123.1, C124.1, C125.1, C126.1, C127.1, C128.1, C131.1, C132.1, C133.1, C134.1, C135.1, C136.1, C137.1, D19.1 (K), FB8.1, FB9.1, FB10.1, FB11.1, J6.2, LS1.1, R5.2, R6.1, R9.2, R11.1, R13.1, R14.1, R15.1, R27.2, R30.2, R31.1, R32.2, R52.2, R72.2, R73.2, R79.2, R83.1, R84.1, R85.1, R86.1, R87.1, R88.1, R89.1, R90.1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
+3.3VA: C1.1, C7.1, C108.1, C109.1, C110.1, C111.1, C112.1, C113.1, C130.1, FB8.2, FB9.2, FB10.2, FB11.2, U2.2 (VCCA), U2.5 (ADC_VREF), U2.34 (VCCA), U2.35 (VCCA), U2.71 (VCCA), U2.107 (VCCA), U2.143 (VCCA)
+12V: C5.1, C6.1, C33.1, C66.1, C83.1, D3.2 (A), D12.2 (A), Q1.1 (G), Q2.3 (C), Q3.1 (E), R1.2, U5.1 (VI), U6.3 (VO), U18.1 (VCC)
+BATT: C3.1, C4.1, C19.1, J9.2, J12.2, SW3.2, SW4.2, SW7.2, SW8.2, TR1.3, U1.2 (VBAT), U6.1 (VI)
+VSW: C84.2, D9.2 (K), Q4.3 (S), R49.1, R102.2, U18.5 (VS), U18.6 (CS)
/+OUT: D10.1 (A), D11.1 (K), J7.1, J11.1, J13.1, L2.2, R24.2
/ANAIN1: C2.1, R4.1, TP7.1, U2.3 (ANAIN1)
/B+: BT1.1 (+), J12.1, SW3.1, SW4.1, SW7.1, SW8.1
/CIdiag: R27.1, U2.96 (IO), U9.14 (DIAG)
/CIoutn: R42.1, U9.10 (OUTN)
/CIoutp: R41.1, U9.11 (OUTP)
/CSEN: C67.1, J10.1, R50.1, R99.2, R101.1
/CVdiag: R30.1, U2.97 (VREFB6N), U10.14 (DIAG)
/CVoutn: R54.1, U10.10 (OUTN)
/CVoutp: R53.1, U10.11 (OUTP)
/DisG: Q6.1 (G), R110.2
/HGNDCI: C28.2, C29.2, C30.2, C31.2, C32.1, FB2.1, U9.2 (DCDC_HGND), U9.8 (HGND)
/HGNDCV: C36.2, C50.2, C73.1, C74.2, C80.2, C81.2, R21.2, R28.1, U10.2 (DCDC_HGND), U10.7 (INN), U10.8 (HGND)
/HGNDLI: C45.2, C46.1, C47.2, C48.2, C49.2, FB7.1, U14.2 (DCDC_HGND), U14.8 (HGND)
/HGNDLV: C72.2, C75.2, C76.1, C77.2, C78.2, C79.2, R81.2, R82.1, U8.2 (DCDC_HGND), U8.7 (INN), U8.8 (HGND)
/LIdiag: R52.1, U2.93 (IO), U14.14 (DIAG)
/LIoutn: R35.1, U14.10 (OUTN)
/LIoutp: R36.1, U14.11 (OUTP)
/LSEN: J11.2, L2.1, R102.1, R103.1
/LVdiag: R79.1, U2.98 (IO), U8.14 (DIAG)
/LVoutn: R56.1, U8.10 (OUTN)
/LVoutp: R55.1, U8.11 (OUTP)
/REFGND: C2.2, FB1.1, U2.4 (REFGDN)
/SW: R29.2, TR1.2, U1.6 (SW)
/VCCIO1A: C91.1, C114.1, J4.2, R15.2, U2.9 (VCCIO1A)
/VCCIO1B: C89.1, C115.1, J1.4, R14.2, R75.1, R76.1, R77.1, U2.23 (VCCIO1B)
/ain_1: D2.1 (K), J4.1, U2.14 (ADC1IN8)
/ain_2: D1.1 (K), J4.3, U2.13 (ADC1IN7)
/ain_3: D4.1 (K), J4.4, U2.12 (ADC1IN6)
/ain_4: D6.1 (K), J4.5, U2.11 (ADC1IN5)
/ain_5: D13.1 (K), J4.6, U2.10 (ADC1IN4)
/ain_6: D14.1 (K), J4.7, U2.8 (ADC1IN3)
/ain_7: D15.1 (K), J4.8, U2.7 (ADC1IN2)
/ain_8: D16.1 (K), J4.10, U2.6 (ADC1IN1)
/arm: J6.9, R13.2, U2.120 (IO)
/arm_led: D8.1 (K), J6.6, U2.132 (IO)
/bootsel: R93.1, R94.2, U2.126 (BOOTSEL)
/charge: U1.9 (CHRG), U2.62 (IO)
/ck+: U2.33 (CLKOUTP)
/ck-: U2.32 (CLKOUTN)
/conf_done: D18.1 (K), J6.4, U2.138 (CONF_DONE)
/cont_led: D7.1 (K), J6.3, U2.135 (IO)
/cont_n: Q5.3 (C), R72.1, U2.69 (IO)
/crc: R111.2, U2.134 (CRC_ERR)
/cs: R17.1, R68.1, U2.106 (IO)
/dataA0: R18.1, U2.99 (IO)
/dataA1: R69.1, U2.102 (IO)
/dataB0: R19.1, U2.100 (IO)
/dataB1: R70.1, U2.105 (IO)
/devclrn: R96.2, R112.2, U2.121 (DEVCLRN)
/devoe: R97.2, U2.122 (DEVOE)
/dio0: J2.1, U2.118 (IO)
/dio1: J2.2, U2.119 (IO)
/dio2: J2.5, U2.113 (IO)
/dio3: J2.6, U2.114 (IO)
/dio4: J2.7, U2.111 (IO)
/dio5: J2.8, U2.112 (VREFB7N)
/dio6: J2.9, U2.110 (IO)
/done: R32.1, U1.8 (DONE), U2.64 (IO)
/dump: R10.1, U2.66 (IO)
/fire: J6.1, R7.1, R107.2, SW1.1, SW5.1, SW6.1, SW9.1
/gate: Q4.1 (G), R22.2
/hdmi2_ck+: J5.10 (CK+), U2.52 (IO)
/hdmi2_ck-: J5.12 (CK-), U2.50 (IO)
/hdmi2_d0+: J5.7 (D0+), U2.56 (IO)
/hdmi2_d0-: J5.9 (D0-), U2.55 (IO)
/hdmi2_d1+: J5.4 (D1+), U2.58 (IO)
/hdmi2_d1-: J5.6 (D1-), U2.57 (IO)
/hdmi2_d2+: J5.1 (D2+), U2.60 (IO)
/hdmi2_d2-: J5.3 (D2-), U2.59 (IO)
/hdmi_ck+: J8.10 (CK+), U2.39 (IO)
/hdmi_ck-: J8.12 (CK-), U2.38 (IO)
/hdmi_d0+: J8.7 (D0+), U2.43 (IO)
/hdmi_d0-: J8.9 (D0-), U2.41 (IO)
/hdmi_d1+: J8.4 (D1+), U2.45 (IO)
/hdmi_d1-: J8.6 (D1-), U2.44 (IO)
/hdmi_d2+: J8.1 (D2+), U2.47 (IO)
/hdmi_d2-: J8.3 (D2-), U2.46 (IO)
/iset0: J6.7, SW2.6, U2.127 (IO)
/iset1: J6.8, SW2.5, U2.130 (IO)
/iset2: J6.5, SW2.4, U2.131 (IO)
/jtagen: J1.8, R76.2, U2.15 (JTAGEN)
/nstatus: D17.1 (K), U2.136 (NSTATUS)
/osc: R74.1, U2.29 (CLK1P)
/pwm: R105.1, U2.65 (IO)
/pwmr: R105.2, U18.2 (IN)
/reset_n: R12.1, R112.1, U2.28 (CLK1N)
/rx: R106.2, U2.24 (IO)
/rx232: J3.1, U22.8 (R1IN)
/sclk: R16.1, R67.1, U2.101 (IO)
/spi_clk: U2.87 (IO), U19.B2 (CK)
/spi_cs: U2.81 (IO), U19.A3 (nCS)
/spi_d0: U2.78 (IO), U19.D3 (DQ0)
/spi_d1: U2.85 (IO), U19.D2 (DQ1)
/spi_d2: U2.75 (IO), U19.C4 (DQ2)
/spi_d3: U2.77 (IO), U19.D4 (DQ3)
/spi_d4: U2.76 (IO), U19.D5 (DQ4)
/spi_d5: U2.79 (IO), U19.E3 (DQ5)
/spi_d6: U2.84 (IO), U19.E2 (DQ6)
/spi_d7: U2.86 (IO), U19.E1 (DQ7)
/spi_ds: U2.74 (IO), U19.C3 (RWDS)
/spi_nrst: U2.80 (VREFB5N), U19.A4 (nRST)
/spk+: R108.1, U2.140 (IO)
/spk-: U2.141 (IO)
/tck: J1.1, R78.1, U2.18 (TCK)
/tdi: J1.9, R75.2, U2.19 (TDI)
/tdo: J1.3, U2.20 (TDO)
/tms: J1.5, R77.2, U2.16 (TMS)
/tx: U2.25 (IO), U22.11 (T1IN)
/tx232: J3.2, U22.13 (T1OUT)
/vccio7: C90.1, C120.1, J2.4, R31.2, U2.117 (VCCIO7)
/vina0+: C38.1, R39.2, U3.1 (VINA+)
/vina0-: C39.1, R40.2, U3.2 (VINA-)
/vina1+: C54.1, R61.2, U17.1 (VINA+)
/vina1-: C56.1, R62.2, U17.2 (VINA-)
/vinb0+: C40.1, R45.2, U3.8 (VINB+)
/vinb0-: C41.1, R46.2, U3.7 (VINB-)
/vinb1+: C55.1, R63.2, U17.8 (VINB+)
/vinb1-: C57.1, R64.2, U17.7 (VINB-)
/vref0: C8.1, C9.1, R47.2, U3.3 (REFA), U3.6 (REFB)
/vref1: C59.1, C60.1, R65.2, U17.3 (REFA), U17.6 (REFB)
CIhi: FB4.2, R101.2
CIlo: FB2.2, FB3.2, R100.2
CVhi: R20.1, R99.1
CVlo: R21.1, R51.1
GND: BT1.2 (-), C1.2, C3.2, C4.2, C5.2, C6.2, C7.2, C8.2, C9.2, C10.2, C11.2, C12.2, C13.2, C14.2, C15.2, C16.2, C17.2, C18.2, C19.2, C20.2, C21.2, C22.2, C23.2, C24.2, C25.2, C26.2, C33.2, C34.2, C37.2, C38.2, C39.2, C40.2, C41.2, C42.2, C43.2, C51.2, C52.2, C54.2, C55.2, C56.2, C57.2, C58.2, C59.2, C60.2, C61.2, C62.2, C63.2, C64.2, C65.2, C66.2, C67.2, C68.2, C70.2, C71.2, C83.2, C85.2, C86.2, C87.2, C88.2, C89.2, C90.2, C91.2, C93.2, C95.2, C96.2, C97.2, C98.2, C99.2, C100.2, C101.2, C102.2, C103.2, C104.2, C105.2, C106.2, C107.2, C108.2, C109.2, C110.2, C111.2, C112.2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
LIhi: FB5.2, R49.2
LIlo: FB6.2, FB7.2, R103.2
LVhi: R24.1, R80.1
LVlo: R81.1, R104.1
unnamed: D1.2 (A), R83.2
unnamed: D2.2 (A), R84.2
unnamed: C17.1, D3.1 (K), Q1.2 (S)
unnamed: D4.2 (A), R85.2
unnamed: D5.1, TR1.4
unnamed: D6.2 (A), R86.2
unnamed: D7.2 (A), R5.1
unnamed: D8.2 (A), R9.1
unnamed: D11.2 (A), R23.2
unnamed: C84.1, D12.1 (K), U18.8 (VB)
unnamed: D13.2 (A), R87.2
unnamed: D14.2 (A), R88.2
unnamed: D15.2 (A), R89.2
unnamed: D16.2 (A), R90.2
unnamed: D17.2 (A), R91.1
unnamed: D18.2 (A), R92.1
unnamed: D19.2 (A), LS1.2, Q7.3 (C)
unnamed: D20.2 (A), R109.1
unnamed: D20.1 (K), Q8.3 (C)
unnamed: FB3.1, R26.1
unnamed: FB4.1, R25.1
unnamed: FB5.1, R33.1
unnamed: Q1.3 (D), R2.2, R110.1
unnamed: Q2.2 (B), R10.2
unnamed: Q3.2 (B), R23.1
unnamed: Q3.3 (C), R71.2
unnamed: Q5.2 (B), R71.1
unnamed: Q7.2 (B), R108.2
unnamed: Q8.2 (B), R111.1
unnamed: R35.2, R37.1, U12.1 (-)
unnamed: R36.2, R38.1, U12.8 (+)
unnamed: R37.2, R40.1, U12.4 (+)
unnamed: R38.2, R39.1, U12.5 (-)
unnamed: R41.2, R43.1, U7.8 (+)
unnamed: R42.2, R44.1, U7.1 (-)
unnamed: R43.2, R45.1, U7.5 (-)
unnamed: R44.2, R46.1, U7.4 (+)
unnamed: R53.2, R57.1, U15.8 (+)
unnamed: R54.2, R58.1, U15.1 (-)
unnamed: R55.2, R59.1, U16.8 (+)
unnamed: R56.2, R60.1, U16.1 (-)
unnamed: R57.2, R61.1, U15.5 (-)
unnamed: R58.2, R62.1, U15.4 (+)
unnamed: R59.2, R63.1, U16.5 (-)
unnamed: R60.2, R64.1, U16.4 (+)
unnamed: R107.1, U2.124 (IO)
unnamed: C18.1, U1.10 (CT)
unnamed: R29.1, U1.3 (RFB)
unnamed: R8.1, U1.1 (RREF)
unnamed: TR1.1, U1.7 (SEC)
unnamed: R95.1, U2.129 (NCONFIG)
unnamed: R16.2, U3.15 (SCLK)
unnamed: R18.2, U3.14 (SDATAA)
unnamed: R19.2, U3.13 (SDATAB)
unnamed: R17.2, U3.10 (nCS)
unnamed: R6.2, U4.3 (EN)
unnamed: C69.2, U8.15 (DCDC_GND)
unnamed: C69.1, U8.13 (LDO_OUT), U8.16 (DCDC_IN)
unnamed: C75.1, C76.2, C78.1, U8.1 (DCDC_OUT), U8.3 (HLDO_IN)
unnamed: C77.1, C79.1, U8.5 (HLDO_OUT)
unnamed: C72.1, R80.2, R82.2, U8.6 (INP)
unnamed: C35.2, U9.15 (DCDC_GND)
unnamed: C35.1, U9.13 (LDO_OUT), U9.16 (DCDC_IN)
unnamed: C30.1, C31.1, C32.2, U9.1 (DCDC_OUT), U9.3 (HLDO_IN)
unnamed: C28.1, C29.1, U9.5 (HLDO_OUT)
unnamed: C27.2, R26.2, U9.7 (INN)
unnamed: C27.1, R25.2, U9.6 (INP)
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

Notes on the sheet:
600V
Front Panel extension
Discharge
Igniter
4x 3msps 12bit ADC Interface
32MB Capture Buffer Octal xSPI 400 MB/s
41x gain
2x HDMI Video Out
Voltage Sense 1V/400V
Voltage Probes
Ishunt
Sampling ADCs simultaneous 4ch 12bit 3mhz isolated zero latency
FPGA Power
2.0x gain
FPGA Configuration and RS232
Vcm = 1.024V
Continuity
Discharge Energy Sink Resistor
Capacitor Discharge Current Sense
Digitial FPGA Model Rocket Launch Controller Features: - Handheld Launch Controller - Capacitive discharge ignition (CDI) - Digital current controlled - High efficiency over 1000 launches on AA batteries (lithium) - Feild programmable gate array FPGA controlled - Simple controls for safe operation 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
Serial Test Comms SPI, I2C, UART Reconfigurable
5J @ 320V
Power Supply
Low speed Front Panel and Config
Power Stage
Analog Expansion
Current Probes
1x gain pre-amps
Current Setpoint 1 Amp : off-off-on 2 Amp : off-on-off 3 Amp : off-on-on 4 Amp : on-off-off 5 Amp : on-off-on 6 Amp : on-on-off
Load Current Sense 10mV/A 0.005 ohms
Capacitor Discharger operates whenever power is removed (release of ARM button), by using a small low voltage diode charged capacitor to turn on a mosfet to discharge the high voltage capacitors into a resistor. Fpga controlled dump over-ride provided.
1:12 Flyback Transformer
High Voltage Control
Launch Button
Charger
Clock & Reset
ToDo: X - Add well placed buttons N - ADC in battery voltage (do externally), add VIN0? X - Fixup Amp Polarities and gain. - Calc all resistor values N - Split into Sheets/Zones X - Finalize Parts Lists (DK and JLC) X - Add Decoupling everywhere - Add Test points and ground clips - more LED Outputs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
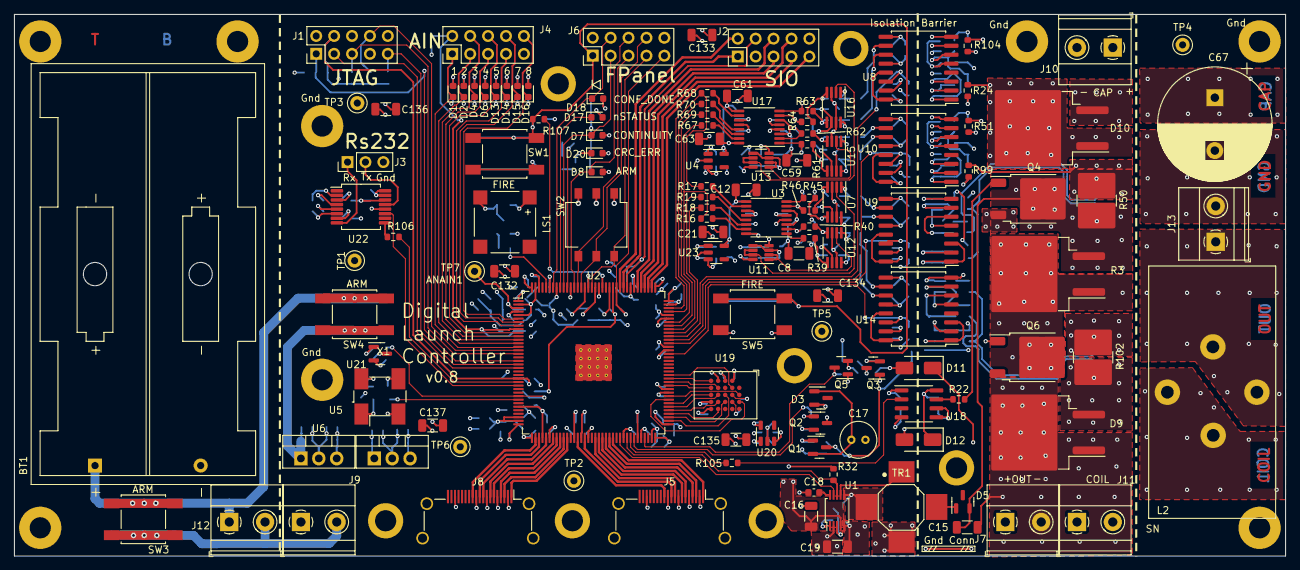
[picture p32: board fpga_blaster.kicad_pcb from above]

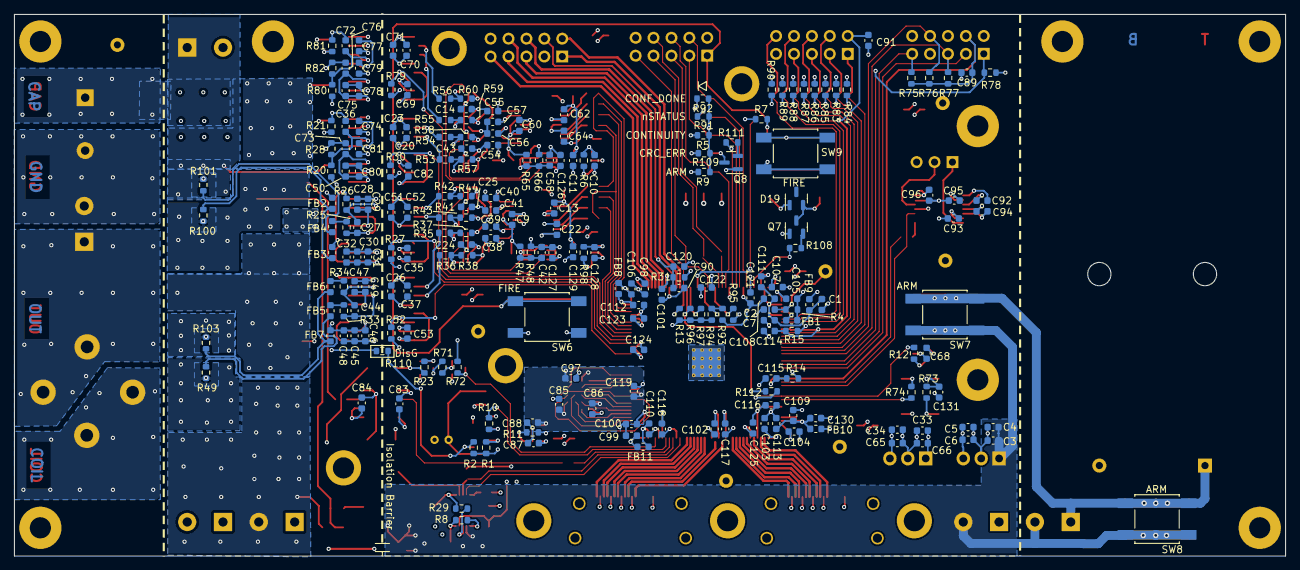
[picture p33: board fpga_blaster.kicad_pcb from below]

Board: 4 copper layers, 180.3 x 76.8 mm, 360 parts (221 on the bottom side), 238 nets.

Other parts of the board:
R3: 3K3 25W; TO-263-2_TabPin1

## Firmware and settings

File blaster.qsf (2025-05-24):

# -------------------------------------------------------------------------- #
#
# Copyright (C) 2023  Intel Corporation. All rights reserved.
# Your use of Intel Corporation's design tools, logic functions 
# and other software and tools, and any partner logic 
# functions, and any output files from any of the foregoing 
# (including device programming or simulation files), and any 
# associated documentation or information are expressly subject 
# to the terms and conditions of the Intel Program License 
# Subscription Agreement, the Intel Quartus Prime License Agreement,
# the Intel FPGA IP License Agreement, or other applicable license
# agreement, including, without limitation, that your use is for
# the sole purpose of programming logic devices manufactured by
# Intel and sold by Intel or its authorized distributors.  Please
# refer to the applicable agreement for further details, at
# https://fpgasoftware.intel.com/eula.
#
# -------------------------------------------------------------------------- #
#
# Quartus Prime
# Version 23.1std.0 Build 991 11/28/2023 SC Lite Edition
# Date created = 11:07:06  May 16, 2024
#
# -------------------------------------------------------------------------- #
#
# Notes:
#
# 1) The default values for assignments are stored in the file:
#		blaster_assignment_defaults.qdf
#    If this file doesn't exist, see file:
#		assignment_defaults.qdf
#
# 2) Intel recommends that you do not modify this file. This
#    file is updated automatically by the Quartus Prime software
#    and any changes you make may be lost or overwritten.
#
# -------------------------------------------------------------------------- #


set_global_assignment -name FAMILY "MAX 10"
set_global_assignment -name DEVICE 10M04SCE144C8G
set_global_assignment -name TOP_LEVEL_ENTITY blaster_chip
set_global_assignment -name ORIGINAL_QUARTUS_VERSION 23.1STD.0
set_global_assignment -name PROJECT_CREATION_TIME_DATE "11:07:06  MAY 16, 2024"
set_global_assignment -name LAST_QUARTUS_VERSION "23.1std.0 SP0.02std Lite Edition"
set_global_assignment -name PROJECT_OUTPUT_DIRECTORY output_files
set_global_assignment -name MIN_CORE_JUNCTION_TEMP 0
set_global_assignment -name MAX_CORE_JUNCTION_TEMP 85
set_global_assignment -name DEVICE_FILTER_PACKAGE EQFP
set_global_assignment -name DEVICE_FILTER_PIN_COUNT 144
set_global_assignment -name DEVICE_FILTER_SPEED_GRADE 8
set_global_assignment -name ERROR_CHECK_FREQUENCY_DIVISOR 256
set_global_assignment -name EDA_SIMULATION_TOOL "Questa Intel FPGA (Verilog)"
set_global_assignment -name EDA_TIME_SCALE "1 ps" -section_id eda_simulation
set_global_assignment -name EDA_OUTPUT_DATA_FORMAT "VERILOG HDL" -section_id eda_simulation
set_global_assignment -name EDA_GENERATE_FUNCTIONAL_NETLIST OFF -section_id eda_board_design_timing
set_global_assignment -name EDA_GENERATE_FUNCTIONAL_NETLIST OFF -section_id eda_board_design_symbol
set_global_assignment -name EDA_GENERATE_FUNCTIONAL_NETLIST OFF -section_id eda_board_design_signal_integrity
set_global_assignment -name EDA_GENERATE_FUNCTIONAL_NETLIST OFF -section_id eda_board_design_boundary_scan
set_global_assignment -name POWER_PRESET_COOLING_SOLUTION "23 MM HEAT SINK WITH 200 LFPM AIRFLOW"
set_global_assignment -name POWER_BOARD_THERMAL_MODEL "NONE (CONSERVATIVE)"
set_global_assignment -name EDA_TEST_BENCH_ENABLE_STATUS TEST_BENCH_MODE -section_id eda_simulation
set_global_assignment -name EDA_NATIVELINK_SIMULATION_TEST_BENCH testbench -section_id eda_simulation
set_global_assignment -name EDA_TEST_BENCH_NAME testbench -section_id eda_simulation
set_global_assignment -name EDA_DESIGN_INSTANCE_NAME NA -section_id testbench
set_global_assignment -name EDA_TEST_BENCH_MODULE_NAME testbench -section_id testbench
set_global_assignment -name EDA_TEST_BENCH_FILE testbench.sv -section_id testbench
set_global_assignment -name FLOW_ENABLE_POWER_ANALYZER ON
set_global_assignment -name POWER_DEFAULT_INPUT_IO_TOGGLE_RATE "12.5 %"
set_location_assignment PIN_33 -to clk_out
set_location_assignment PIN_29 -to clk_in
set_location_assignment PIN_120 -to arm_button
set_location_assignment PIN_124 -to fire_button
set_location_assignment PIN_127 -to iset[0]
set_location_assignment PIN_130 -to iset[1]
set_location_assignment PIN_131 -to iset[2]
set_location_assignment PIN_132 -to arm_led_n
set_location_assignment PIN_135 -to cont_led_n
set_location_assignment PIN_140 -to speaker
set_location_assignment PIN_141 -to speaker_n
set_location_assignment PIN_62 -to lt3420_charge
set_location_assignment PIN_64 -to lt3420_done
set_location_assignment PIN_28 -to reset_n
set_location_assignment PIN_65 -to pwm
set_location_assignment PIN_69 -to cont_n
set_location_assignment PIN_66 -to dump
set_location_assignment PIN_106 -to ad_cs
set_location_assignment PIN_102 -to ad_sdata_a[1]
set_location_assignment PIN_99 -to ad_sdata_a[0]
set_location_assignment PIN_105 -to ad_sdata_b[1]
set_location_assignment PIN_100 -to ad_sdata_b[0]
set_location_assignment PIN_86 -to spi8_data_pad[7]
set_location_assignment PIN_84 -to spi8_data_pad[6]
set_location_assignment PIN_79 -to spi8_data_pad[5]
set_location_assignment PIN_76 -to spi8_data_pad[4]
set_location_assignment PIN_77 -to spi8_data_pad[3]
set_location_assignment PIN_75 -to spi8_data_pad[2]
set_location_assignment PIN_85 -to spi8_data_pad[1]
set_location_assignment PIN_78 -to spi8_data_pad[0]
set_location_assignment PIN_74 -to spi_ds
set_location_assignment PIN_81 -to spi_ncs
set_location_assignment PIN_87 -to spi_clk0
set_location_assignment PIN_101 -to ad_sclk
set_location_assignment PIN_96 -to CIdiag
set_location_assignment PIN_97 -to CVdiag
set_location_assignment PIN_93 -to LIdiag
set_location_assignment PIN_98 -to LVdiag
set_location_assignment PIN_39 -to hdmi_ck
set_location_assignment PIN_38 -to "hdmi_ck(n)"
set_location_assignment PIN_43 -to hdmi_d0
set_location_assignment PIN_41 -to "hdmi_d0(n)"
set_location_assignment PIN_45 -to hdmi_d1
set_location_assignment PIN_44 -to "hdmi_d1(n)"
set_location_assignment PIN_47 -to hdmi_d2
set_location_assignment PIN_46 -to "hdmi_d2(n)"
set_location_assignment PIN_13 -to anain[7]
set_location_assignment PIN_12 -to anain[6]
set_location_assignment PIN_11 -to anain[5]
set_location_assignment PIN_10 -to anain[4]
set_location_assignment PIN_8 -to anain[3]
set_location_assignment PIN_7 -to anain[2]
set_location_assignment PIN_6 -to anain[1]
set_location_assignment PIN_24 -to rx232
set_location_assignment PIN_25 -to tx232
set_location_assignment PIN_110 -to digio[6]
set_location_assignment PIN_112 -to digio[5]
set_location_assignment PIN_111 -to digio[4]
set_location_assignment PIN_114 -to digio[3]
set_location_assignment PIN_113 -to digio[2]
set_location_assignment PIN_119 -to digio[1]
set_location_assignment PIN_14 -to anain[8]
set_location_assignment PIN_118 -to digio[0]
set_location_assignment PIN_52 -to hdmi2_ck
set_location_assignment PIN_50 -to "hdmi2_ck(n)"
set_location_assignment PIN_56 -to hdmi2_d0
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

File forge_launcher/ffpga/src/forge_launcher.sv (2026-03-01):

// vim: ts=4:
`timescale 1ns / 1ps
// ForgeFPGA model rocket launcher
// Digital PWM, current controlled buck converter. capacitive discharge
// igniter pulse generator 
module forge_launcher
(
	// System
	input logic clk,
	input logic reset,

	// Front Panel I/O
	input  logic fire_button,
	output logic arm_led,
	output logic cont_led,
	output logic speaker,

	// High Voltage 
	output logic lt3420_charge,
	input  logic lt3420_done,
	output logic pwm,	
	output logic dump,
	
	// External A/D Converters (2.5v)
	output logic  ad_cs,
	input  logic  ad_s_vcap, 
	input  logic  ad_s_vout,
	input  logic  ad_s_iout,
	input  logic  neg_vcap,
	input  logic  neg_vout,
	input  logic  neg_iout,
	
	///////////////////
	// Emulation I/o //
	///////////////////
	
	// Debug Controls
	input logic auto_mode,  // Run launch sequence
	input logic use_est,	// trust current estimations
	input logic mute,	// Only beep on 1st cont measurement
	
	// Backdoor keypad controls
	input	logic [4:0] key,  // keypad 

	// monitor outputs for Display
	output logic [11:0] 	ad_iout, 
	output logic [11:0] 	ad_vcap, 
	output logic [11:0] 	ad_vbat, // future 
	output logic [11:0] 	ad_vout,
	output logic 		ad_strobe,
	output logic [11:0] 	iest,
	output logic 		burn = 0,
	output logic [11:0]	igniter_res,	
	
	// Display and Logging control outputs
	output logic scroll_halt = 0,
	output logic charge,
	output logic fire_done = 0,
	output logic fire_button_debounce,
	output logic cap_halt = 0,
	output logic long_fire
);

	// ADC Scale parameters
	parameter ADC_VOLTS_PER_DN = 0.2005;
	parameter ADC_DN_PER_AMP = 205;
	// Physical parameters
	parameter CLOCK_FREQ_MHZ = 48;  // 48 or 24 Mhz
	parameter COIL_IND_UH = 390;


// Free running counter
logic [25:0] count;
always_ff @(posedge clk) 
	count <= count + 1;

//////////////////////////////////////////////
// fire button 10ms debounce 
// signal to get 1.3 sec of pwm current control
// signal One shot capture mode on 1st rising pwm edge 1.3 sec
// signal to set discharge at 1.3sec
// signal to stop tiny scroll window at 4.3 sec
//////////////////////////////////////////////

logic [27:0] fire_count = 0; 
logic fire_flag = 0;

forge_debounce #( CLOCK_FREQ_MHZ ) _firedb ( .clk( clk ), .reset( reset ), .in( fire_button ), .out( fire_button_debounce ), .long( long_fire ));

parameter PWM_START     = 1; // Enable PWM current control 
parameter PWM_END			= (CLOCK_FREQ_MHZ*4/3) * 1000 * 1000; // Total time 1.333 sec
parameter SCROLL_HALT	= (CLOCK_FREQ_MHZ*13/3) * 1000 * 1000; // Total time 4.333 sec
parameter CAP_HALT		= PWM_START + 1000 * CLOCK_FREQ_MHZ/3; // stop capture before re-trigger or wrap

always @(posedge clk) begin
	if( reset ) begin // for now, later should allow arm release
		fire_count <= 0;
		fire_flag <= 0;
		fire_done <= 0;
		scroll_halt <= 0;
		cap_halt <= 0;
	end else begin
		fire_count <= ( fire_count == 0 && !fire_button_debounce ) ? 0 : fire_count + 1; // committed when past debounce
		fire_flag <= ( fire_count == PWM_START && !fire_done ) ? 1'b1 : ( fire_count == PWM_END ) ? 1'b0 : fire_flag;
		scroll_halt <= ( fire_count == SCROLL_HALT ) ? 1'b1 : scroll_halt;
		cap_halt <= ( fire_count == CAP_HALT ) ? 1'b1 : cap_halt;
		fire_done <= ( fire_count == PWM_END ) ? 1'b1 : fire_done;
	end
end

assign dump = fire_done  | key == 5'h1B; // always dump after firing

////////////////////////////////
// Power On auto charge and continuity until fire button
////////////////////////////////
logic charge_reg;
logic continuity;
logic [1:0] one_time;
initial charge_reg = 0;
initial continuity = 0;
initial one_time = 0;
always @( posedge clk ) begin
	if( reset ) begin
		charge_reg <= 0;
		continuity <= 0;
		one_time <= 0;
	end else begin
		one_time <= ( one_time == 3 ) ? 3 : one_time + 1;
		if( one_time == 2 ) begin
			charge_reg <= auto_mode;
			continuity <= 0;
		end else if( ( lt3420_done || cap_charged ) && charge_reg ) begin // switch to continuity
			charge_reg <= 0;
			continuity <= 1;
		end else if( continuity && fire_flag ) begin // and end the launch sequence
			charge_reg <= 0;
			continuity <= 0;
		end else begin
			charge_reg <= charge_reg;
			continuity <= continuity;	
		end
	end
end
assign charge = charge_reg;
assign lt3420_charge = charge | key == 5'h1A;

//////////////////////////////

// Speaker is differential out gives 6Vp-p
logic [15:0] tone_cnt;
logic cont_tone, first_tone;
logic spk_en, spk_toggle;

always @(posedge clk) begin
	if( tone_cnt == 0 ) begin
		spk_toggle <= !spk_toggle;
		if( CLOCK_FREQ_MHZ == 24 ) begin
			{spk_en, tone_cnt}<= ( key == 5'h11 || fire_button_debounce ) ? { 1'b1, 16'h1665 } :
										//( key == 5'h12 ) ? { 1'b1, 16'h13f3 } :
										( key == 5'h13 ) ? { 1'b1, 16'h11c6 } :
										//( key == 5'h14 ) ? { 1'b1, 16'h10C7 } :
										( key == 5'h15 ) ? { 1'b1, 16'h0EF2} :
										//( key == 5'h16 ) ? { 1'b1, 16'h0d51 } :
										//( key == 5'h17 ) ? { 1'b1, 16'h0bdd } :
										( /*key == 5'h18 ||*/ ( (cont_tone && !mute) || first_tone ) ) ? { 1'b1, 16'h0b32 } : 0; // sw0 mutes tone
		end else begin // CLK_FREQ_MHZ == 48
			{spk_en, tone_cnt}<= ( key == 5'h11 || fire_button_debounce ) ? { 1'b1, 16'h2CCA } :
										//( key == 5'h12 ) ? { 1'b1, 16'h27E7 } :
										( key == 5'h13 ) ? { 1'b1, 16'h238D } :
										//( key == 5'h14 ) ? { 1'b1, 16'h218E } :
										( key == 5'h15 ) ? { 1'b1, 16'h1DE5 } :
										//( key == 5'h16 ) ? { 1'b1, 16'h1AA2 } :
										//( key == 5'h17 ) ? { 1'b1, 16'h17BA } :
										( /*key == 5'h18 ||*/ ( (cont_tone && !mute) || first_tone ) ) ? { 1'b1, 16'h1665 } : 0; // sw0 mutes tone
		end
	end else begin
		tone_cnt <= tone_cnt - 1;
		spk_en <= spk_en;
		spk_toggle <= spk_toggle;
	end
end

assign speaker = spk_toggle & spk_en ; 

////////////////////////////////////////////
// Burn-through detect 
// If burn through occurs we will see high dvdt on the output.
// In this case we'll stop operation to minimize voltage spikes.
 
logic [11:0] ad_vout_del = 0;
logic signed [12:0] dv; // delta voltage
assign dv[12:0] = { ad_vout[11], ad_vout[11:0] } - { ad_vout_del[11], ad_vout_del[11:0] };
initial ad_vout_del = 0;
logic signed [12:0] max_dvdt = 24 * (16 * 10000) / (ADC_VOLTS_PER_DN * 10000 * CLOCK_FREQ_MHZ); // (24 v/usec limit * 16 cyc/sample)/(.2005 v/dn * 48 Mhz)
always @(posedge clk) begin
	if( reset ) begin
		burn <= 0;
		ad_vout_del <= 0;
	end else begin
		burn <=( fire_flag && ( dv > max_dvdt ) ) ? 1'b1 : burn;	// dv > +24 V/us
		ad_vout_del <= ad_vout; // ad_vout only changes on sample x16, but is fine for our detection use
	end
end

////////////////////////////////////////////
// PWM Current limited pulse generator
////////////////////////////////////////////
logic 			pwm_pulse = 0;
logic [15:0] 	pulse_time = 0;
logic [9:0] 	pulse_count = 0;
logic				ramp_flag = 0;

logic [11:0] 	thresh_hi, thresh_lo;
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

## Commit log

2024-06-01 added arm button respone - not used in practice but helpful in testing and sims
2024-06-12 Added current estimation model with correction feedback to control PWM Gives earlier and finer control over PWM timing
    [blaster.sv]
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2024-07-30 Add the PCB KiCad current version
    [fpga_blaster.kicad_pcb, fpga_blaster.kicad_sch]
2024-09-26 PCB V0.8 tapeout
    [fpga_blaster.kicad_pcb, fpga_blaster.kicad_sch]
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2024-11-04 SPI8_pll fixes (patched altpll wizard)
    [blaster.qsf]
2024-11-04 tunr off charger, hook up cont led to sw1, halve the tone to 14 (was very jarring)
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2024-11-06 fonts fixed and working
    [blaster.qsf]
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2024-11-08 uninvert adsclk issues with config
    [blaster.qsf, blaster_chip.sv]
2024-11-08 Scope to bits 10:2 works for now till adc is adjusted by a cycle. (and inverted?)
    [blaster_chip.sv]
2024-11-12 starting to put pseduo sram with SPI8 interface together. Support, soft reset, read ID, write CR0(lat=3), read burst8, write burst16
    [blaster_chip.sv]
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2024-11-14 Keypad kinda working. need to invert digio and turn on weak pullups. All need to detect release
    [blaster_chip.sv]
2024-11-14 inverted keypad signals and turned on weak pullups (and on iset inputs)
    [blaster.qsf, blaster_chip.sv]
2024-11-14 Fixed up keypad to detect 4 cycles with no contact closure
    [blaster_chip.sv]
2024-11-18 fixup typo's (maybe fix bug?)
    [blaster_chip.sv]
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2024-11-20 Font color and trace stagger incl fixup
2024-11-21 Delay the ADC sample window 1 cycle for full 12 bit capture
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2024-11-26 Digikey bill of materials for v0.8 pcb. Note 1) Does *not* include ECOs. 2) the 2183-4945-ND dc/dc is best gotten directly from mfg.
    [fpga_blaster.bom.csv]
2024-11-26 A Digikey fastcart link BOM v0.8 (before ECO and missing pololu dc/dc)
2024-12-06 Added 5x7 vga font for more complete ASCII chars. (xls generated data)
    [font_5x7_gen.xlsx]
2024-12-09 Invert continuity panel LED.
    [blaster_chip.sv]
2024-12-12 Add coil model, stand alone ADC module, and integrate pwm and iest into wave display datapath
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2024-12-12 Clip current to zero and direction to be aligned with PWM to limit drift
2024-12-14 wire in pwm signal. basic operation observed scale seems 4x too small
    [blaster_chip.sv]
2024-12-15 Added a VGA string overlay module, and convereted the vga wage trace funciton over too it.
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2024-12-16 clean up VGA scopes by removing local fonts and switch over to overlay strings
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2025-01-02 fix text. it is an estimate of output (or coil) current
2025-01-02 wired up '(' key to genrate a 2.6usec pwm pulse, 1ms repeat
2025-01-08 Added testbench and used it to confirmed that Resistance ouput is a clipped 6.5 format
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2025-01-09 Add offsets to the adc in lieu of trimpots. There should? be no issue with wrap. Offsets seemed about 5.5. Next version put some resistive trimmers in.
    [blaster.sv]
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2025-01-09 Fixed comment on clamp testcase
2025-01-11 Add simplest pwm pulse generation logic with 8us max width and 2amp current limit, observed overshoot due to loop delay..
    [blaster_chip.sv]
2025-01-12 hack Recalibrated the estimate as each PWM cycle is started to control model drift
2025-01-12 PWM controlled by current feedback with min 1 pulse and max 16 usec high. .(just a 3 cycle experiment)
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2025-01-14 Restored display of B0 trace (was temp driven by R=E/I resistance plot)
2025-01-15 cobbled together an igniter resistance unit which uses a 2usec PWM pulse to get an average output resistanced.
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2025-01-16 Added 3E.E (62.9) ohms as open circuit indication. (or no cap voltage), and single-shot operation debounce.
2025-01-18 First run with model feedback. 3 cycle pwm operation. Wish I could record a photo with this commit.
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2025-01-19 Added ramp flag for min pulses until the first time we've seen current over the min tolerance. Flatest so far.
    [blaster_chip.sv]
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2025-01-21 added one-shot fire button behavior with frame capture. First Match ignition captured. Nice has 10Msec fire debounce then 1.3 of firing (need burnthrough abort), and freezing of capture display disch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
    [blaster_chip.sv]
2025-01-21 Move text for ADC, PSRam, key, and my name to HDMI 2 display, for pending removal of independant displays, Currently 96% fpga utilization
2025-01-22 Resistance calculation included a long ~1s holdoff and includes updating continuity led and has coded tone outputs
2025-01-22 integrate tones and LED, and iset[0] mute input and iset[2] latch on reset auto charge/continutity util fire. Gives us a working launch controller
    [blaster_chip.sv]
2025-01-23 Add power accumulate flag to resistance measurement unit to accumulate power delivered to igniter during resistance pulse
2025-01-23 Repalced 5x7font for $ with omega for ohm char
    [font_5x7_gen.xlsx]
2025-01-23 Added Pulse energy as integral of cap and output power (sum of I*V samples). operates for resistance and firing pulses
2025-01-23 Added first tone so it always beeps the first continuity result even when muted. also inverted arm light (not perfect functionallity yet)
    [blaster_chip.sv, ohm_div.sv]
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2025-01-24 Limit battery current in RUN mode by holding hdmi encoder in reset until we've finished charging.
    [blaster_chip.sv]
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2025-01-27 Igniter burthrough detect, if after seeing 0.5A then see 0. current falls < 150 mA while still having 100 Volts in the cap. Burn through detect discontinues pulse initiation (todo terminate current p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
    [blaster_chip.sv]
2025-01-27 Full buffer capture after cap halt, and burn address and burn display if detected, and PWM pulse terminated on burn
    [blaster_chip.sv]
2025-01-28 Centered zoom, added burnthrough on vout>vcap, turned off some text saves logic (99%->97%)
    [blaster_chip.sv]
2025-02-01 Add burn detect trace bit to capture buffer to show detected burnthrough
2025-02-01 Add dv > 24v/usec as term to burn through detect.
    [blaster_chip.sv]
2025-02-02 Fix issue with reset of enegy measurements when zooming with the fire button
    [blaster_chip.sv]
2025-02-02 Fix post fire setting of burn flag
    [blaster_chip.sv]
2025-02-02 stop energy accumulation upon burn detect. Try to improve robust fire button (ie fire flag not set during fire sequence)
    [blaster_chip.sv]
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2025-02-08 Redo the model so it runs in ADC current units for easy re-initialization from ADC
    [fpga design calcs.xlsx]
2025-02-08 Fixed up formatting of re-init data from adc to model. Seems to be behaving ...
2025-02-08 Fire pushbutton debounce 5/80ms on/off AND 20ms beep. Basic usable button with feedback (no mute)
2025-02-12 Lesson Learned "the MAX10SC-compact devices do not support Memory Initialization" needed for the text overlay. Un-integrated from chip at this time, sigh
2025-02-14 Changed , to upper bar in font. And fixed up verillog for simulator that generates the font rom init txt file
    [font_5x7_gen.xlsx]
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2025-02-15 SW1 disables model feedback into control loop (will just use ADC current feedback, proves it controls current in model-gone-crazy situations)
2025-02-19 Added text chars, Updated font file, ran sim, editted overlay. Commit to gen mif file
    [font_5x7_gen.xlsx, fpga design calcs.xlsx]
2025-02-19 Moving special chars into 7-bit ASCII space. Unicode handling during rom building is needed.
    [font_5x7_gen.xlsx]
2025-02-22 change scope trace ram to infered (hoping to dave space, but no space saving, just reduced synthesis efforts to optimize)
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2025-03-04 Fixed width of ohm mult input, no effect
    [ohm_div.sv]
2025-03-06 Fixed up debounce, blitvert operational
    [blaster_chip.sv]
2025-03-08 filter in the flow to embed the git commit 7 digit hash into the video overlay. Part of the command: git rev-parse HEAD | head -c7 | basenc --base2msbf --wrap=8 | awk -f format_commit.awk
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2025-03-22 missed added DC/DC ISO power for top side fet driver.
    The bootstrap power assumptions are not always valid, and consistancy was prefered so ISO power supply 12v/12v added for far side gate drive
2025-03-25 Generate HDMI info frames for RGB and YUV format HDMI. 32w by 9bits each. For use in hardwired logic used tools from https://github.com/hdl-util/hdmi.git
2025-03-27 Update ECO changes for V0.8 pcb.txt
    Pulldown to stop pwm floating when programming (never good)
2025-03-27 To save $500. Dynamically switch HDMI to YUV2 during blipvert to use cheap $20 USB capture dongles supporting lossless driverless YUV2 capture
2025-04-01 Text overlay resistance legend expanded and tightened
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2025-05-24 Split out forge launcher wrapper and changed to .sv and fixed some error. cleanish syntax in Forge and Quartus
    [blaster.qsf, forge_launcher.sv]
2025-05-24 both quartus and forge build without severe errors
    [forge_launcher.sv]
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2025-05-25 Change over to reset-less operation by setting config time defaults. Still no fit 125% even with 64 element deltaiv table.
    [forge_launcher.sv]
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2025-05-25 Replace resistance based continuity with simple IVmax circuit. Compiles 96% ultil 23 Mhz so far
    [forge_launcher.sv]
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2025-05-26 Shorten manual pulse test to 3 pulses
    [forge_launcher.sv]
2025-05-26 Forge functioning in emulation with reset
    [forge_launcher.sv]
2025-05-26 Tried reset-less mode. not working in emulation with sof load. tried initial statements,, improved (blink) but no more action
    [blaster_chip.sv, forge_launcher.sv]
2025-05-29 Simplified burnthrough to trigger if deltaV > 24V/us.
    [forge_launcher.sv]
2025-06-04 early PCB design files
    [forge_launcher.kicad_pcb, forge_launcher.kicad_sch]
2025-06-05 Revert "Simplified burnthrough to trigger if deltaV > 24V/us."
    This reverts commit 615e04b294d4fd2ba8a925b19df2fbe28992f398.
    [forge_launcher.sv]
2025-06-08 handheld controller PCB layout. Caps, Coil and 4xAA battery holder on bottom side. 2 buttons, 2 leds on topside. ForgeFPGA can mount below with battery removed and 02x13 header sockets added. Will 3d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
    [forge_launcher.kicad_pcb, forge_launcher.kicad_sch]
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2025-06-17 Landscape style PCB initial layout 3d. Large components on bottom as per model. Forge emulator connector section of PCB can be cut away, but also has a spare fpga land point.
    [forge_launcher.kicad_pcb, forge_launcher.kicad_sch]
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2025-06-20 The stl files for the 3d printed enclosure I'm using at the launch field with overview png
    [button ring v4.stl, lcd 7in rear cover v2.stl, led standoff 5mm.stl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]
2025-06-21 Added mosfet so FPGA can eventually replace the LT3420 capacitor charger
    [forge_launcher.kicad_sch]
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2025-06-25 Added component for 3d button frogs (better name than push-button-with-spring-for-tactile-switch)
    [forge_launcher.kicad_pcb]
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2026-02-26 Update to last ver before fork
    [forge_launcher.kicad_pcb, forge_launcher.kicad_sch]
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2026-02-28 handle small vcap clipping correctly
    [forge_launcher.sv]
2026-02-28 Switch over to positive ADC values, disconnect reset
    [lcc_tb.sv]
2026-03-01 remove div0 protect logic (no div), and simplify burn through to delta V only, save CLBs (for later)
    [forge_launcher.sv]
2026-03-01 Revert "change a0,b0 nomenclature to actual"
    This reverts commit 8ab39ee2bacc326bad7372e209d56e6ba7c35253.
    [forge_launcher.sv, lcc_tb.sv]
